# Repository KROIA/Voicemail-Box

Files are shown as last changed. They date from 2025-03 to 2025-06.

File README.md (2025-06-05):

# Voicemail-Box

## About
Modern-day communication is more and more reliant on smartphones. This can cause issues in numerous situations. It can alienate people with writing, seeing, or technological deficiencies. 

Since the development of new electronic systems is often too complicated for non-affine people, the goal is to develop a platform that makes it easier to get started with such a project. The highest priority was given to audio input and output, user differentiation/management, file saving, and transferring those wirelessly.

<tr>
<td>
<div align="center">
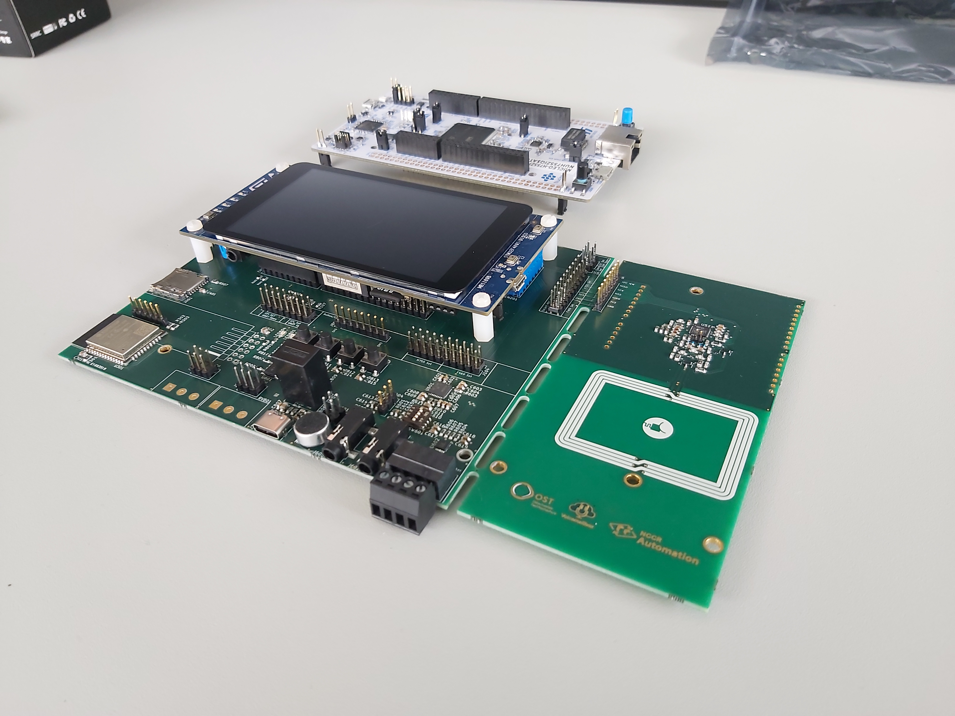
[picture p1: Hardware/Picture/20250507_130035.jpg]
     
</div>
</td>

---
## Repository overview
The repository is structured the following way:
- **Hardware** folder contains the hardware specific project.  
[Go to Hardware Dokumentation](Hardware/README.md)

- **Software** folder contains the main source code and api.  
[Go to Software Dokumentation](Software/BSP_VoiceMailBox/README.md)

---
## Features
The Voicemailbox Development Platform offers the basic hardware and software components to develop specific use cases out of it.
The custom PCB is designed to be flexible for different kind of configurations and the software is built in a modular and structural way, using modern C++ to be able to abstract hardware components better and make it easy to develop custom business logic on to it.

### The current state of development features the following:
- Recording audio from different sources:
  - Audio jack for left and right audio channel.
  - Built-in microphone
- Playback audio to the audio output jack
- Filesystem using a SD-Card and easy to use file class for reading and writing files
- Two different audio encodings for files are supported:
  - **WAV** Which is a lossless easy to write/read file format for audio data with the downside of beeing very large in filesize.
  - **MP3** Which is a more common used audio format, much more compressed and the prefered choice for a application such as this one.
            The only downside is, that it is not fully supported on a **M7** core.
- Testserver implementation that manages file upload/download.
  With the help of the ESP32, files can be uploaded/downloaded from a server using a WIFI connection.
  No user authentication is implemented at the current state of the development.
- Two free programmable LED's.
- Four free programmable buttons.
- Two free programmable analog inputs.
  
### Untested features:
- Playback using the speaker connection (J603) is implemented in hardware but not implemented and tested in the software.
- NFC module

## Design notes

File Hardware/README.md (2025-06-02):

# Hardware
This folder contains all HW-Files and documentation of how to use them

## Info
The name for the Microcontroller/Evaluation Boards will be abreviated in the instructions as the following:
- Voicemail-Box Board: 	VMBB
- STM32F469-Disco:		F469
- Nucleo-H755:			H755
- X-Nucleo NFC8:		NFC8
- P-Mod ESP32:			PMOD
- ...

## Orientation
All jumper/switch settings asume that the board is orientet like this image unless otherwise specified.   
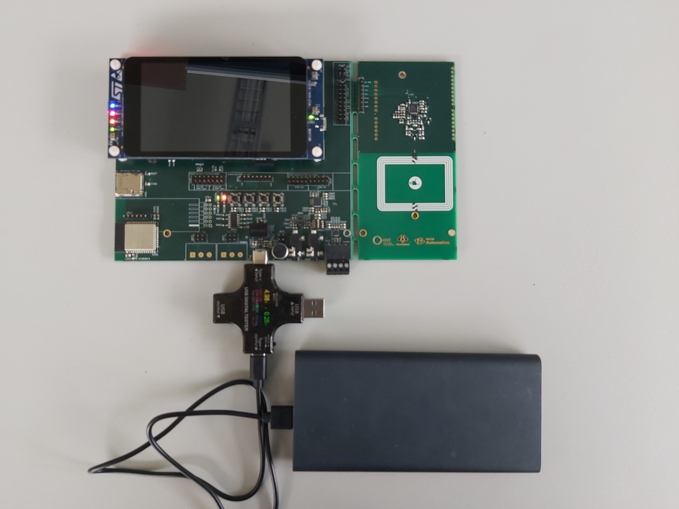
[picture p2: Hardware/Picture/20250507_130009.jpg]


Here is a schematic view where jumpers are also labled:  
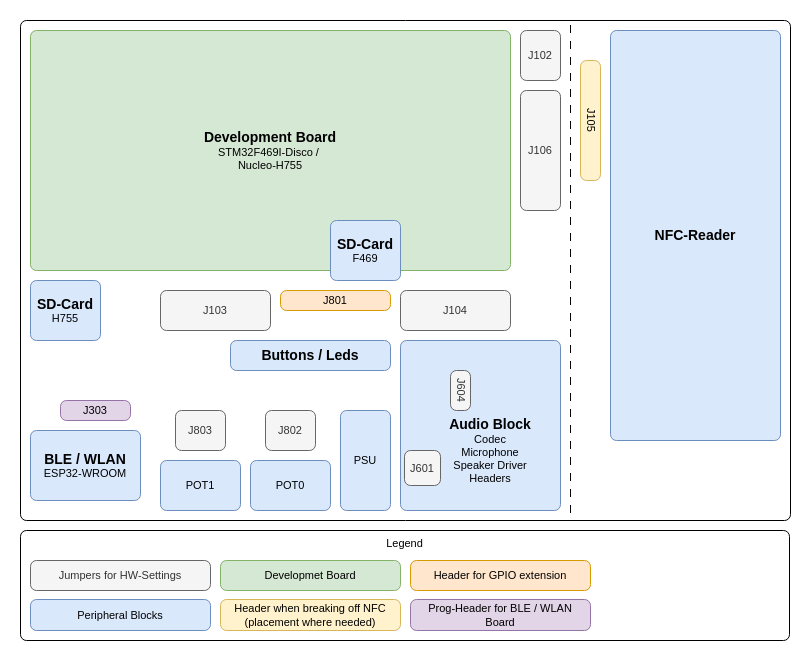
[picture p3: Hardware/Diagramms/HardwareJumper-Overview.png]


## HW Setup
The VMBB is made to be soldered in a full and a partial configuration as well as beeing compatible with
multiple Microcontrollerboards (F469 and H755)

The partial configuration is made for people that are inexperienced with soldering / are lacking equipment.  

The full configuration is made as the de-facto correct way of manufacturing at the cost off beeing way more difficult to produce.

> [!CAUTION]  
> When fully soldering the NFC part will likely require a microscope  
> and the Wifi part will require an aditional USB to UART Converter with 3.3V logic level write the flash memory of ESP32.

to use one or the other, select the correct BOM to solder and only solder the mentioned parts. There are no differences in the use of the finished board.

- tbd: make the BOMs and a assembly plan
- tbd: add pictures

### Soldering
There is no need to solder all possible parts on the pcb. Select the configuration you prefer and only solder the parts in the corresponding BOM.The [Assembly Plan](PCB/Fab/voicemail-box-F_Fab.pdf) shows the position and most of the part Values.
- [Go to partial BOM](PCB/BOM/voicemail-box_partial.csv)
- [Go to full BOM](PCB/BOM/voicemail-box_full.csv)

> [!NOTE]  
> If you want to edit the PCB files I recommend using KICAD with the KiVar Plugin

## Select Microcontroller Board in use (get the correct Jumper settings)
- [Configure Board for H755](Config/H755/H755.md)
- [Configure Board for F469](Config/F469/F469.md)

## Configure periperal Conections (for those which offer this feature)
Some devices can use different Connection Interfaces offereing different benefits.
This is due to the fact, that this is an development board.  
In a specific use, you would select one and ignore the other one.

## WLAN/BLE
Wireless connection can be made either through UART or SPI  
While SPI is way faster, it is more complicated to set up
- [Configure WLAN/BLE using SPI](Config/SPI_WLAN.md)
- [Configure WLAN/BLE using UART](Config/UART_WLAN.md)
## NFC
NFC can be read-out either through I2C or SPI  
While SPI is way faster and is tested.
I2C would help in case that there is a pin-limitation of the final project.
- F469
    - [Configure NFC using SPI](Config/F469/NFC_SPI_F469.md)
    - [Configure NFC using I2C](Config/F469/NFC_I2C_F469.md) 
- H755
    - [Configure NFC using SPI](Config/H755/NFC_SPI_H755.md)
    - [Configure NFC using I2C](Config/H755/NFC_I2C_H755.md) 

## Configure HW Features
- [Configure PSU](Config/PSU.md)
- [Configure Poti](Config/Poti.md)
- [Configure Audio](Config/Audio.md)
- [Configure LEDs](Config/Leds.md)
- [Configure Buttons](Config/Buttons.md)
- [Configure micro SD](Config/uSD.md)

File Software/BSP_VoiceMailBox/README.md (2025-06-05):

# BSP Voice Mail Box

## About
The Voice-Mail-Box Project (VMB in short) provides a Board Support Package (BSP) that abstracts all key peripheral components using c++.

---
## Content
- [Repository overview for the software part](#repository-overview-for-the-software-part)
- [Demos](#demos)
  - [Using STM32F469I-DISCOVERY](#using-stm32f469i-discovery)
  - [Using NUCLEO-H755ZI-Q](#using-nucleo-h755zi-q)
- [Software structure](#software-structure)
  - [Detailed Software structure](#detailed-software-structure)
  - [Peripheral classes](#peripheral-classes)
  - [Data processing classes](#data-processing-classes)
  - [Other utilitiy classes](#other-utilitiy-classes)
  - [HAL abstraction](#hal-abstraction)
  - [Update loop](#-update-loop)
- [Unfinished](#unfinished)
- [Needs to be implemented](#needs-to-be-implemented)

---
## Repository overview for the software part
The software part of this project contains the following folders:
- **BSP_VoiceMailBox** 
  The folder contains the **Board Support Package** for the Voice-Mail-Box and is the hart of the software project.
  It contains all classes which are visualized in the picture in the chapter [Detailed Software structure overview](#detailed-software-structure-overview).  
- **Demos**
  The folder contains some demo projects, using the **BSP** from above.
  In that folder are two sub folders
  - **F469** Containing the example projects for the **STM32F469I-DISCOVERY** board
  - **F755** Containing the example projects for the **NUCLEO-H755ZI-Q** board
- **DevSandbox** 
  The folder contains projects, used to develop the **BSP**. 
  They may be not working since they were created to test stuff or to test downloaded demo projects from ST.

Each project contains only the business logic for the application, the **BSP** is a shared code base over all projects.
The **BSP** gets included in every project. 

---
## Demos
### Using STM32F469I-DISCOVERY
- [HelloAudio](../Demos/F469/F469_HelloAudio/README.md) empty application + setup guide.
- [Record and Playback](../Demos/F469/F469_RecordPlayback/README.md) example that records audio and plays it back.
- [Multi Example](../Demos/F469/F469_MultiExample/README.md) project, containing multiple small examples for different classes of this project.

### Using NUCLEO-H755ZI-Q
- :warning: [HelloAudio](../Demos/H755/H755_HelloAudio/README.md) Currently not working

---
## Software structure
A very brief visualisation about the software hirarchy is displayed below.
<tr>
<td>
<div align="center">
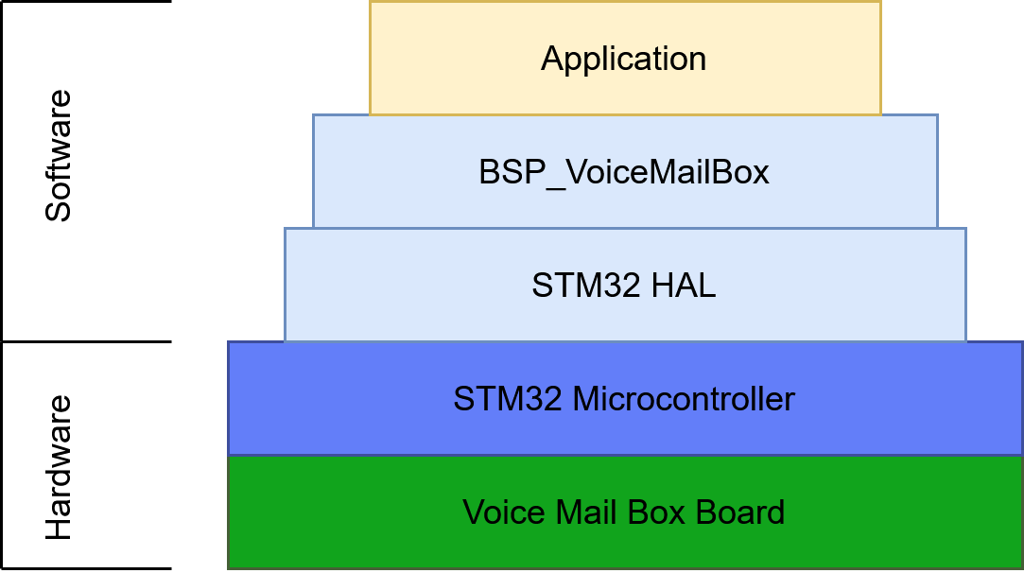
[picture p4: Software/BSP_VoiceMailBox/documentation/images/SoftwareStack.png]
     
</div>
</td>

---
### Detailed Software structure 
This view displays the relation between the key software components delivered by the BSP.
The Application must include only the **BSP_VoiceMailBox.h** header file, it already includes all relevant hardware components and software tools related to the VMB.

<tr>
<td>
<div align="center">
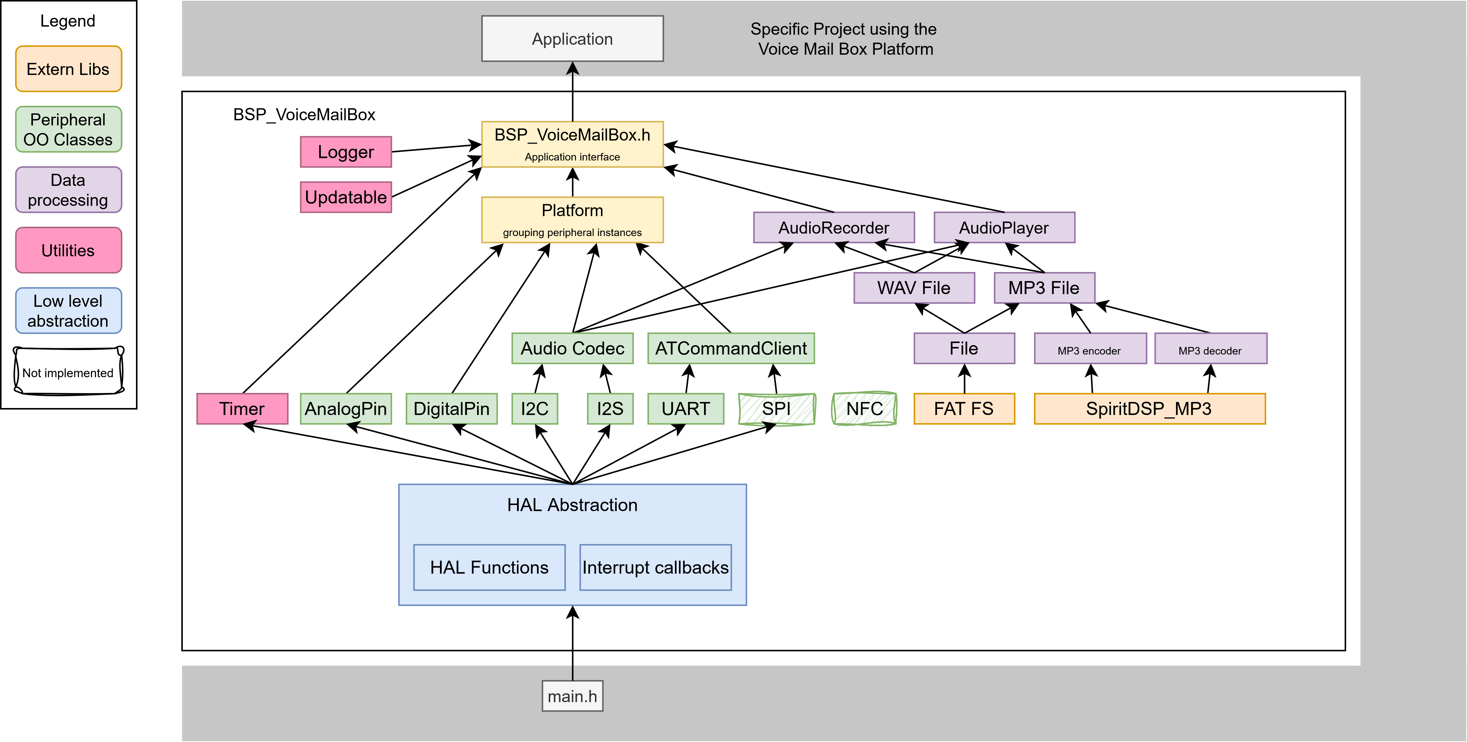
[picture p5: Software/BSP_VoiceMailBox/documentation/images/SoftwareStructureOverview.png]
     
</div>
</td>

### Peripheral classes
- [AnalogPin](documentation/AnalogPin.md)
- [DigitalPin](documentation/DigitalPin.md)
- [I2C](documentation/I2C.md)
- [I2S](documentation/I2S.md)
- [UART](documentation/UART.md)
- [AudioCodec](documentation/AudioCodec.md)
  - [Codec_TLV320AIC3104](documentation/Codec_TLV320AIC3104.md)
- :satellite: [ATCommandClient](documentation/ATCommandClient.md)

### Data processing classes
- [File](documentation/File.md)
  - :musical_note: [WAV File](documentation/WAVFile.md)
  - :musical_note: [MP3 File](documentation/MP3File.md)
- MP3
  - :small_red_triangle_down: [MP3 Encoder](documentation/MP3_encoder.md)
  - :small_red_triangle: [MP3 Decoder](documentation/MP3_decoder.md)
- :microphone: [Audio Recorder](documentation/AudioRecorder.md)
- :speaker: [Audio Player](documentation/AudioPlayer.md)

### Other utilitiy classes
- :pencil: [Logger](documentation/Logger.md)
- :repeat: [Updatable](documentation/Updatable.md)
- :watch: [Timer](documentation/Timer.md)

### HAL abstraction
All HAL related functions are located in two files:
- **HAL_abstraction.hpp**: 
  Contains inline functions, encapsulating all HAL functions used in the BSP.
  Do not use HAL functions inside the BSP directly, that would break the software design of the HAL abstraction. If a new HAL function is needed, create a new inline function with the same name but a **VMB_** in front to signalize its the same function but specific for the BSP
- **interrupts.cpp**: 
  Contains all interrupt callbacks used in the BSP.
  Each class that uses interrupt callbacks, contains a static method that gets called in the interrupt callback to simplify the logic inside the HAL callback.

### :repeat: Update loop
The update loop is programmed in the Platform struct and handles the updating of all **Updatable** objects, clears the I2S flags if configured so and handles the updating of the systick counter for when an overflow occures.
For a smooth operation, this function must be called cyclically without any delays if possible.
You can see the function calls in almost all examples in the loop() function.

---
## Unfinished
- :construction: [TLV320AIC3104 Audio Codec](documentation/Codec_TLV320AIC3104.md) has only the most basic functions implemented and can be expanded to use its full potential.
  
---
## Needs to be implemented
- :construction: SPI class to communicate with the ESP32
- :construction: SPI compatibility with the [ATCommandClient](documentation/ATCommandClient.md) class in order to use SPI for sending and receiving AT-Commands. 
- :construction: NFC class to read NFC tags.

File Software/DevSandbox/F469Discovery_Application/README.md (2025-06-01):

## IOC File Settings

### Middleware and Software Packs:
	- FREERTOS:
		Disable

### Buttons:
	PIN(PA7):	BTN0
		User Label:	BTN0
	PIN(PA2):	BTN1
		User Label:	BTN1
	PIN(PG12):	BTN2
		User Label:	BTN2
	PIN(PA1):	BTN3
		User Label:	BTN3

### LEDS:
	PIN(PA6): 	LED0
		User Label: LED0
	PIN(PG12): 	LED1
		User Label: LED1
		
### Potis:
	PIN(PC4):	ADC1_IN14
		User Label:	POT0
	PIN(PC3):	ADC2_IN13
		User Label:	POT1
		
### WiFi:
	USART6:
		Baud Rate: 115200
		Word Length: 8 Bits (including parity)
		Parity: None
		Stop Bits: 1
		PIN(PG14): 	TX 
		PIN(PG9): 	RX
		// DMA Settings:
		// 	DMA für RX & TX
		// 	Mode: Normal
		NVIC Settings:
			[x] USART6 global interrupt
	PIN(PC5): INT GPIO_ExtI5 with name: "ESP_INT"
	
### Debug Console:
	USART3:
		Baud Rate: 115200
		Word Length: 8 Bits (including parity)
		Parity: None
		Stop Bits: 1
		// DMA Settings: 
		// 	DMA für RX & TX
		// 	Mode: Normal
		NVIC Settings:
			[x] USART3 global interrupt
			
### Audio Codec
	I2S2:
		Mode: Full-Duplex Master
		[x] Master Clock Output
		GPIO Settings:
			PIN(PB12): I2S2_WS (I2S2_SCLK)
			PIN(PB13): I2S2_CK (I2S2_BCLK)
			PIN(PC1):  I2S2_SD (I2S2_SDA)
			PIN(PC2):  I2S2_ext_SD 	(I2S2_SDA_ext)
			PIN(PC6):  I2S2_MCK (I2S2_MCLK)
			
		Parameter Settings:
			Transmission Mode: Mode Master Transmit
			Communication Standard: I2S Philips
			Data and Frame Format: 16Bit Data on 16 Bits Frame
			Selected Audio Frequency: 48KHz
			
		DMA Settings:
			SPI2_TX:
				Mode: Circular
				Data Width: Half Word
	GPIO:
		PIN(PG13): CODEC_NRESET Digital Output
	
### SD-Card
	System Core:
		NVIC:
			SDIO global interrupt: ON
	Connectivity:
		SDIO:
			Mode = "SD 1 bit"
			DMA Setting:
				SDIO_RX, DMA2 Stream 3, Peripheral To Memory, Low
				SDIO_TX, DMA2 Stream 6, Memory To Peripheral, Low
	Middleware and Software Packs:
		FATFS:
		    SD Card: ON
		    Advanced Settings->SDIO:
		    Use dma template: Enabled
		
## Project Properties
		C/C++ General->Paths and Symbols:
			Includes:
				Add:
					Directory: "${ProjDirPath}/../../BSP_VoiceMailBox/inc"
					[x] Add to all configurations
					[x] Add to all languages
			Source Location:
				Link Folder:
					[x] Link to folder in file system
					Variables...
						New...
							Name: BSP_VoiceMailBox
							Location: "${PROJECT_LOC}/../../BSP_VoiceMailBox/src"
							OK
						Select the new created variable: BSP_VoiceMailBox
						OK
				OK
		
		Library Includes
		FPU setting

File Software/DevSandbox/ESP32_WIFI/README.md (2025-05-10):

# PmodESP32

## Setup
### Communication via UART
Board STM32F469
UART6 auf Stiftleiste CN12
ESP32:2 -- RX -- DiscoveryBoard(CN12:6 -- TX -- STM32:PC6)
ESP32:3 -- TX -- DiscoveryBoard(CN12:8 -- RX -- STM32:PC7)

Software:
UART6
Baud: 115200
DMA für UART6_RX & UART6_TX
NVIC->UART6 global interrupt ENABLED

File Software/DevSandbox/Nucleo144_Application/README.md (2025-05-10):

- Connectivity->ETH:
	Disable on both M7 & M4

- Connectivity->SDMMC1:
  Mode = "SD 1 bit"
  NVIC:
	SDMMC1 global interrupt: Enabled
  DMA Setting:
	? Nicht gefunden?: SDIO_RX, DMA2 Stream 3, Peripheral To Memory, Low
	? Nicht gefunden?: SDIO_TX, DMA2 Stream 6, Memory To Peripheral, Low

- WiFi-Modul:
	USART1:
		Enabled on M4
		DMA für RX and TX
		PIN(PB6): 	USART1_TX 
		PIN(PB7): 	USART1_RX
	? PIN(PC2):			INT

- I2S2 (I2S_A, Dataflow(STM32->Codec)):
	Enabled on M4
	? HalfDuplexMasterTransmit
	[x] Master Clock Output
	Parameter Settings:
		Selected Audio Frequency: 44KHz
	GPIO Settings:
		PIN(PB12): I2S2_WS
		PIN(PB13): I2S2_CK
		PIN(PB15): I2S2_SDO
		PIN(PC6): I2S_MCK
	NVIC Settings:
		SPI2 global interrupt: Enabled 
	DMA Settings:
		SPI2_TX:
			Mode: Circular
			Data Width: Half Word
	
- I2S3 (I2S_B, Dataflow(Codec->STM32)):
	Enabled on M4
	? HalfDuplexMasterReceive
	? [x] Master Clock Output
	Parameter Settings:
		Selected Audio Frequency: 44KHz
	GPIO Settings:
		PIN(PA15): I2S3_WS
		PIN(PB3): I2S3_CK
		PIN(PC7): I2S3_MCK
		PIN(PC11): I2S3_SDI
		? PIN(PB4):              I2S_SDA_ext
		? PIN(PG14): 		    CODEC_nReset  
	NVIC Settings:
		SPI3 global interrupt: Enabled
	DMA Settings:
		SPI3_RX:
			Mode: Circular
			Data Width: Half Word
		
- I2C1 (Codec config):
	Enabled on M4
	GPIO Settings:
		PIN(PB8):	I2C1_SCL
		PIN(PB9): 	I2C1_SDA
	DMA Settings:
		I2C1_TX:
			Mode: Normal
			Data Width: Byte
		I2S1_RX:
			Mode: Normal
			Data Width: Byte
			
- SPI1 (SPI2 auf dem Schema, NFC-Reader):
	Enabled on M4
	Full-Duplex Master
	Hardware NSS Output Signal
	GPIO Settings:
		PIN(PA4): 	SPI1_NSS
		PIN(PB3):	SPI1_SCK
		PIN(PB5):	SPI1_MOSI
		PIN(PG9):	SPI1_MISO
		? PIN(PA3): NFC_INT 
	DMA Settings:
		SPI1_RX:
			Mode: Circular
			Data Width: Byte
		SPI1_TX:
			Mode: Circular
			Data Width: Byte
	NVIC Settings:
		DMA1 stream2 global interrupt: Enabled
		DMA1 stream6 global interrupt: Enabled
		SPI1 global interrupt: Enabled

- LEDS:
	PIN(PA8): 	LED0
		User Label: LED0
		Pin Context Assignment: ARM Cortex-M4
	PIN(PG12): 	LED1
		User Label: LED1
		Pin Context Assignment: ARM Cortex-M4

- Buttons:
	PIN(PD15):	BTN0
		User Label:	BTN0
		Pin Context Assignment: ARM Cortex-M4
	PIN(PE11):	BTN1
		User Label:	BTN1
		Pin Context Assignment: ARM Cortex-M4
	PIN(PE14):	BTN2
		User Label:	BTN2
		Pin Context Assignment: ARM Cortex-M4
	PIN(PE13):	BTN3
		User Label:	BTN3
		Pin Context Assignment: ARM Cortex-M4
		
- Potis:
	PIN(PB1):	ADC1_INP5
		User Label:	POT0
		Pin Context Assignment: ARM Cortex-M4
	PIN(PC1):	ADC1_INP11
		User Label:	POT1
		Pin Context Assignment: ARM Cortex-M4

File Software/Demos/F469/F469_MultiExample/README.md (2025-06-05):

# Multi Example

## How to select a example
One example can be selected in the `Application.cpp`.
Set the variable `selectedExample` to a desired enum value.
The rest is handled automatically. You can now navigate to the examples specific code.
Lets take the AnalogPin example. Its code is programmed in the `Example_AnalogPin.cpp`.
In that file there may be multiple usecases programmed.
Each usecase can be enabled individually.
Each such `Example_XX.cpp` is structured the same way.
Here a quick file overview:
- On the top are function declarations for setup and loop for that specific usecase example. Additionally a quick description about that usecase is given.
- The `setup()` and `loop()` functions are called from the main `Application.cpp`.
  In that functions you have to uncomment that specific usecase you want to run.
  Do that for both functions and do not mix examples.
- On the bottom of the file are the different use case implementations.
  You can treat them as if they were in the main `Application.cpp` `setup()` and `loop()` functions. This makes it easy to copy code in your own project. 

---
## Examples
- [AnalogPin](#analogpin-example)
- [DigitalPin](#digitalpin-example)
- [AudioPlayer](#audioplayer-example)
- [AudioRecorder](#audiorecorder-example)
- [File](#file-example)
  - [WAV File](#wav-file-example)
  - [MP3 File](#mp3-file-example)
- [I2C](#i2c-example)
- [I2S](#i2s-example)
- [MP3 Encoder](#mp3-encoder-example)
- [MP3 Decoder](#mp3-decoder-example)
- [UART](#uart-example)
- [DC Offset correction example](#dc-offset-correction-example)
- [ATCommandClient example](#atcommandclient-example)
- [Codec TLV320AIC3104 example](#codec-tlv320aic3104-example)
- [Logger example](#logger-example)
- [Updatable example](#updatable-example)
- [Timer example](#timer-example)

---
### AnalogPin example
1) Usage of the built-in potentiometer. It prints the analog value to the console.
2) Instantiating a custom potentiometer. Also prints the analog value to the console.

### DigitalPin example
1) Usage of the built-in button and led. It takes the button value and switches the led on when the button is pressed.
2) Instantiating a custom button and led. It does the same as the first use case.
3) Usage of the callback functions of a button. 
  It turns the LED0 on when BTN0 gets pressed and turns the LED0 off when the BTN0 gets released.
  When the BTN0 is pressed down, the LED1 gets toggled, therefore blinks as long as the BTN0 is held down.

### AudioPlayer example
1) Plays a mp3 file called `record.mp3` from the SD-Card on startup once.
2) Plays a mp3 file called `record.mp3` from the SD-Card when the BTN0 gets pressed.
  By clicking the same button again, the playback will be stopped.
  When playing, the BTN1 can be used to pause/resume the playback.

### AudioRecorder example
1) Records a mp3 file called `record.mp3` to the SD-Card when the BTN0 gets pressed.
  By clicking the same button again, the recording will be stopped.
  When playing, the BTN1 can be used to pause/resume the recording.

### File example
1) Example on how to write to a file.
2) Example on how to append to a file.
3) Example on how to read from a file.

#### WAV File example
1) Example on how to write to a .wav file using live audio data from the codec.
2) Example on how to read from a .wav file and outputting it to the codec.

#### MP3 File example
1) Example on how to write to a .mp3 file using live audio data from the codec.
2) Example on how to read from a .mp3 file and outputting it to the codec.

#### I2C example
The example writes to the first register on the audio codec and reads the value back.

#### I2S example
The example uses a i2s object to read and write the audio data from the audio codec.
The codec sends microphone data and the application copies that microphone data to the
speaker output buffer. 
Since the audio codec needs to be configured before data arrives on the i2s, the following code is called first to ensure setup and then stop the DMA in order to start it manually afterwards again. Just for you to know that the DMA needs to be started on a i2s object.
Using the platforms audio codec object directly will take that step from you.
``` C++
VoiceMailBox::setup();
i2s.stopDMA();
```

#### MP3 Encoder example
This example reads audio samples from a .wav file and encodes them to .mp3 format using the `MP3_encoder` class. The encoded data is then written to a new .mp3 file.

#### MP3 Decoder example
This example uses the MP3_decoder class to decode an MP3 file and write the decoded audio data to a WAV file.
The MP3_decoder class is used to read compressed MP3 data and decode it into PCM audio samples.
The WAVFile class is used to write the decoded audio samples to a WAV file.

#### UART example
This example sends some simple text or byte arrays over the UART interface
The UART can also wait for a specific string to be received or read until a target string is found.

#### DC Offset correction example
This example shows how to remove the DC offset from the left and right audio channels.

#### ATCommandClient example
This example shows hot to use the ESP32 using the ATCommandClient abstraction to communicate with the server for uploading and downloading files.
To run this example, follow the [instructions](../../../BSP_VoiceMailBox/documentation/TestServer.md) to setup the testserver.

#### Codec TLV320AIC3104 example
1) This example shows a basic usage of the TLV320AIC3104 codec.
   The example captures audio data from the codec and plays it back directly.
2) This example shows a basic usage of the TLV320AIC3104 codec with volume control.
   The POT1 potentiometer is used to control the volume of the audio data captured from the codec.

#### Logger example
Shows some simple console output methodes that can be used.

#### Updatable example
Shows how to use the Updatable class to automatically call a update function in a derived class object.

#### Timer example
All examples in the timer example do the same thing but are implemented in different ways, to show the different ways the Timer can be used.

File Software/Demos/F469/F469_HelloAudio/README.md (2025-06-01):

# HelloAudio for the F469
The HelloAudio example is just a empty application ready to expand on.
Copy the project in case you want to develop a custom application.

Below is a setup guide that describes step by step how to configure a completly new project for the Voice Mail Box platform. It uses the **STM32F469I-DISCOVERY** board.
> [!WARNING]  
> Read each instruction carfully since there are many pitfalls. 

## Content
- [Project creation](#project-creation)
- [IOC File Setup](#ioc-file-setup)
  - [Disable unused parts](#disable-unused-parts)
  - [Buttons](#buttons)
  - [Leds](#leds)
  - [Debug Pins](#debug-pins)
  - [Potentiometer](#potentiometer)
  - [WIFI ESP32](#wifi-esp32)
  - [Debug Console](#debug-console)
  - [I2C](#i2c)
  - [SD-Card](#sd-card)
  - [Audio Codec](#audio-codec)
- [Create Application body](#create-application-body)
- [Setup de BSP_VoiceMailBox](#setup-de-bsp_voicemailbox)
  - [Microcontroller board selection](#microcontroller-board-selection)
  - [Peripheral handle getter functions](#peripheral-handle-getter-functions)
  - [Peripheral GPIOs](#peripheral-gpios)
  - [Basic Application using the BSP_VoiceMailBox](#basic-application-using-the-bsp_voicemailbox)
- [Project Properties](#project-properties)
  - [Includes](#includes)
  - [Source Locations](#source-locations)
  - [Libraries](#libraries)
    - [SpiritDSP MP3](#spiritdsp-mp3)
- [How to copy this project as tamplate](#how-to-copy-this-project)
- [Compiler errors](#compiler-errors)

---
## Project creation
Create a new STM32 Project and select the Board: **STM32F469I-DISCO** in the **Board Selector** window.
Select Target Language **C++**
Initialize all peripherals in default mode. 

## IOC File Setup
### Disable unused parts
#### Connectivity
- Disable I2C2
- QUADSPI

#### Multimedia
- SAI1

#### Middleware and Software Packages
- FREERTOS, we don't use a OS.
---
### Buttons
Select the Pins and assign them the given function and user label.

| Pin | Function | User Label |
| --- | --- | --- |
| PA7 | GPIO_Input  | BTN0 |
| PA2 | GPIO_Input  | BTN1 |
| PG12 | GPIO_Input  | BTN2 |
| PA1 | GPIO_Input  | BTN3 |

---
### Leds
Select the Pins and assign them the given function and user label.

| Pin | Function | User Label |
| --- | --- | --- |
| PA6 | GPIO_Output | LED0 |
| PG11 | GPIO_Output | LED1 |

---
### Debug Pins
The debug pins are optional and only used when the macro **VMB_DEVELOPMENT_CONFIGURATION** is defined in the `settings.h`.
Select the Pins and assign them the given function and user label.

| Pin | Function | User Label |
| --- | --- | --- |
| PC7 | GPIO_Output | DBG0 |
| PC13 | GPIO_Output | DBG1 |
| PA4 | GPIO_Output | DBG2 |

---
### Potentiometer
Select the Pins and assign them the given function and user label.

| Pin | Function | User Label |
| --- | --- | --- |
| PC4 | ADC1_IN14 | POT0 |
| PC3 | ADC2_IN13 | POT1 |

---
### WIFI ESP32
#### UART
Enable **USART6** in the **Connectivity** section.
- **Mode**: Asynchronous
- **Hardware Flow Control**: Disable

##### Parameter Settings
Let the settings to be default but check for the following:
- **Baud Rate**: 115200
- **Word Length**: 8 Bits
- **Parity**: None
- **Stop Bits**: 1

##### NVIC Settings
- **USART6 global interrupt**: Enabled

Select the Pins and assign them the given function.

| Pin | Function |
| --- | --- |
| PG14 | USART1_TX | 
| PG9 | USART1_RX |

---
### Debug Console
Enable **USART3** in the **Connectivity** section.
- **Mode**: Asynchronous
- **Hardware Flow Control**: Disable

##### Parameter Settings
Let the settings to be default but check for the following:
- **Baud Rate**: 115200
- **Word Length**: 8 Bits
- **Parity**: None
- **Stop Bits**: 1

##### NVIC Settings
- **USART3 global interrupt**: Enabled

Select the Pins and assign them the given function.

| Pin | Function |
| --- | --- |
| PB10 | USART3_TX | 
| PB11 | USART3_RX |

---
### I2C
Enable **I2C1** in the **Connectivity** section.
- **Runtime contexts**: Cortex-M7
- **I2C**: I2C

Select the Pins and assign them the given function.

| Pin | Function |
| --- | --- |
| PB8 | I2C1_SCL | 
| PB9 | I2C1_SDA |
  
--- 
### SD Card
#### System Core
##### NVIC
- **SDIO global interrupt**: ON
#### Connectivity
##### SDIO
- **Mode**: SD 1 bit
###### DMA Setting
- SDIO_RX, DMA2 Stream 3, Peripheral To Memory, Low
- SDIO_TX, DMA2 Stream 6, Memory To Peripheral, Low
#### Middleware and Software Packs
##### FATFS
- **SD Card**: ON
###### Advanced Settings->SDIO:
- **Use dma template**: Enabled
  
---
### Audio Codec
Enable **I2S2** in the **Multimedia** section.
- **Mode**: Full-Duplex Master
- **Master Clock Output**: Enabled

Select the Pins and assign them the given function.

| Pin | Function |
| --- | --- |
| PB12 | I2S2_WS | 
| PB13 | I2S2_CK |
| PC1 | I2S2_SD |
| PC2 | I2S2_ext_SD |
| PC6 | I2S2_MCK |

##### Parameter Settings
- **Communication Standard**: I2S Philips
- **Data and Frame Format**: 16 Bits Data on 16 Bits Frame
- **Selected Audio Frequency**: 48KHz

#### Reset pin
Select the Pin and assign them the given function.

| Pin | Function | User Label |
| --- | --- | --- |
| PG13 | GPIO_Output | CODEC_NRESET |

---
## Create Application body
Follow the instructions on [How to call C++ code from C](../../../BSP_VoiceMailBox/documentation/CppFromC.md) to setup the Application body.

---
## Setup de BSP_VoiceMailBox
### Microcontroller board selection
In the `main.h` add the following define.
It defines which board is selected to switch between the different HAL implementations in the BSP.
``` C
/* USER CODE BEGIN Private defines */
#define VMB_MICROCONTROLLER_BOARD__STM32F469I_DISCOVERY
/* USER CODE END Private defines */
``` 
---
### Peripheral handle getter functions
To get access to the peripheral handles, the following code must be inserted in the `main.h`:

``` C
/* USER CODE BEGIN EFP */

/**
 * @brief The BSP of the Voice Mail Box needs to access the different peripheral handles generated by the CubeMX.
 * @details
 * When porting the project to a different microcontroller, these getters have to be manually declared here,
 * implemented in the main.cpp and used in the Platform.cpp.
 */
ADC_HandleTypeDef* getADC_POT0();
ADC_HandleTypeDef* getADC_POT1();

UART_HandleTypeDef* getUART_DEBUG();
UART_HandleTypeDef* getUART_WIFI();

I2C_HandleTypeDef* getI2C_Handle();
I2S_HandleTypeDef* getI2S_CODEC();

/* USER CODE END EFP */
```

Implement the functions in the `main.c`.
The instance name may be different. You can find the correct name in the `main.c` on the top where CUBE MX has generated the structs instances.
``` C
/* USER CODE BEGIN PV */
ADC_HandleTypeDef* getADC_POT0()
{
    return &hadc1;
}
ADC_HandleTypeDef* getADC_POT1()
{
    return &hadc2;
}
UART_HandleTypeDef* getUART_DEBUG()
{
    return &huart3;
}
UART_HandleTypeDef* getUART_WIFI()
{
    return &huart6;
}
I2C_HandleTypeDef* getI2C_Handle()
{
    return &hi2c1;
}
I2S_HandleTypeDef* getI2S_CODEC()
{
    return &hi2s2;
}
/* USER CODE END PV */
```
---
### Peripheral GPIOs
CUBE MX sometimes generates macros using the user labels from the IOC file. But for the H755 for example, that process is not made during code generation.
In that case these definitions must been made manually and look like this:
``` C
#define BTN0_Pin GPIO_PIN_7
#define BTN0_GPIO_Port GPIOA
// ... Other pins
```
That macros will be used in the `Platform.cpp` for creating the `DigitalPin` instances.

``` C++
// Inside the Platform.cpp
// Fill in the GPIO_TypeDef* and pin values, generated from the CUBEMX for the buttons
DigitalPin& Platform::getButton(Button index)
{
    // Creating static instances of the DigitalPin class for each button
    // The constructor of the DigitalPin class takes the <GPIO_TypeDef*>, <pin number> and <isInverted> as parameters
    // On this board the buttons are active high, so the isInverted parameter is set to false or can be omitted
    static DigitalPin button[] = 
    {
        { BTN0_GPIO_Port, BTN0_Pin },  // <---
        { BTN1_GPIO_Port, BTN1_Pin },
        { BTN2_GPIO_Port, BTN2_Pin },
        { BTN3_GPIO_Port, BTN3_Pin }
    };
    return button[index];
}
```
Make sure you use the same macro names as they already are used in the `Platform.cpp`, so that the `Platform.cpp` can be let unchanged. Otherwise the `Platform.cpp` must be edited to fit your custom peripheral GOPIO macro names.

---
### Basic Application using the BSP_VoiceMailBox
Replace the empty Application by the following code

``` C++
// Application.cpp
#include "Application.h"
#include "BSP_VoiceMailBox.hpp"

void setup()
{
    VoiceMailBox::setup();
}

void loop()
{
    VoiceMailBox::update();
}

```
---
## Project Properties
Open the **Properties** window for the project.
Navigate to C/C++ General->Paths and Symbols.

### Includes
Click **Add** and paste the following path: `${ProjDirPath}/../../../BSP_VoiceMailBox/inc`.
The path may be different, depending on where the project got created, but in this case the include path is specified relative to the current projects path.
In the case, you create a project on a different location, you have to change the path accordingly.
Set the checkmarks: **Add to all configurations** and **Add to all languages**.
Confirm it by pressing the **OK** button.

For some reason, FATFS may not added to both C and C++, check that by clicking on the languages **GNU C** and **GNU C++**. If the includes for FATFS are only on C, then add them to the C++ language too.

### Source Locations
Click **Link Folder** and check the checkmark **Link to folder in the file system**.
Click on **Variables...**, add a **New** variable and name it: `BSP_VoiceMailBox` and the location: `${PROJECT_LOC}\..\..\..\BSP_VoiceMailBox\src`.
Click **OK**, select the newly created variable and click **OK** again, and then again **OK**.
Now switch the **Configuration** to the other one (Debug -> Release or Release -> Debug).
Now click **Add Folder**, select **BSP_VoiceMailBox** from the list and click **OK**.

### Libraries
#### SpiritDSP MP3 
The spiritDSP MP3 library was used in the [X-CUBE-AUDIO](https://www.st.com/en/embedded-software/x-cube-audio.html) example and therefore also used in this Project.
- In the `Libraries` section click on `Add...` and fill the following in the dialog:
  - **File**: `_mp3decoder_cortex_m4_v2.2.0`
  - **Add to all configurations**: `checked`
  - **Add to all languages**: `checked`
   `OK`
<br>

- In the `Libraries` section click on `Add...` and fill the following in the dialog:
  - **File**: `_mp3encoder_cortex_m4_v2.2.0`
  - **Add to all configurations**: `checked`
  - **Add to all languages**: `checked`
   `OK`
<br>
<br>

- In the `Library Paths` section click on `Add...` and fill the following in the dialog:
  - **Directory**: `${ProjDirPath}/../../../BSP_VoiceMailBox/Middlewares/ST/STM32_Audio/Codecs/SpiritDSP_MP3_Dec/lib`
  - **Add to all configurations**: `checked`
  - **Add to all languages**: `checked`
   `OK`
<br>

- In the `Library Paths` section click on `Add...` and fill the following in the dialog:
  - **Directory**: `${ProjDirPath}/../../../BSP_VoiceMailBox/Middlewares/ST/STM32_Audio/Codecs/SpiritDSP_MP3_Enc/lib`
  - **Add to all configurations**: `checked`
  - **Add to all languages**: `checked`
   `OK`
<br>
<br>

###### Floating point unit settings
Navigate to `C/C++ Build->Settings` and in the `MCU/MPU Settings` set the **floating point ABI** to `Mix HW/SW implementation`, otherwise the project will not compile.
Optional you can enable the `Use float with printf from newlib-nano` and the same for `... scanf ...`.
Do that for both configurations: **Debug** and **Release**

---
## How to copy this project
When you want to use this project as template to create your custom application, you have to repair some ST related copy proplems...
1) If you opened this project in the CubeIDE, close it and delete it from the worspace. **(not from the disc!)**
2) Navigate to the folder of this project and copy it to your desired project directory.
3) Change the name of the copied folder to your new projects name.
4) In the Cube IDE: `File->import->Existing Project into Workspace` and hit **Next >**.
5) Browse to your new project location and use that folder. In the Projects list, the HelloAudio project should be visible.
6) Click on **Finish**
7) Now right click on to the project to rename it using the new project name.
8) In the `Project Explorer` delete the folder called `BSP_VoiceMailBox`. (It is only a link) 
9) Open the `Project Properties`.
10) Navigate to `Resource->Linked Resources`.
11) In the list you may find `BSP_VoiceMailBox_1` with a long path, delete that. Only the `BSP_VoiceMailBox` is needed.
12) Navigate to `C/C++ General->Paths and Symbols`.
13) Now link the `BSP_VoiceMailBox` again using the variable. You find the instructions for that in the [Source Locations](#source-locations) chapter of this document. But you don't have to create a new variable since the variable aready exists.

Thats it, the copied project should now compile and is ready to be filled with some nice C++ code. :sunglasses:
Navigate to the folder `Application/src`, here you find the `Application.cpp` which is your main application file.

---
## Compiler errors
#### False floating point setting
Error: `F469_HelloAudio.elf uses VFP register arguments`
Means the [FPU setting](#floating-point-unit-settings) is not correct. 

#### No peripheral handle getter functions
Error: `'getADC_POT0' was not declared in this scope`
Or similar errors related to the `Platform.cpp` mean that there is no get function for the needed peripheral handle structs. [See here](#peripheral-handle-getter-functions) how to resolve the issue.

#### No peripheral GPIO macros defined
Error: `'BTN0_Pin' undeclared`
Or similar errors related to the `Platform.cpp` mean that there are undefined macros which must be defined in the `main.h`. [See here](#peripheral-gpios) how to resolve the issue.

#### No settings header
Error: `No settings header included, make sure to provide a custom settings header in the main.h file when VMB_CUSTOM_SETTINGS_HEADER is defined!`
If you use custom settings, make sure to not only define the macro `VMB_CUSTOM_SETTINGS_HEADER` but also include a custom settings header in the `main.h` that provides all settings needed for the BSP.

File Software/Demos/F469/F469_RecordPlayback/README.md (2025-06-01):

# RecordPlayback example
This example uses two buttons on the PCB to start/stop recording a mp3 file and to play/stop the recorded mp3 file.
The application code can be found in `Application/src/Application.cpp`

The whole applications business logic is implemented in the `setup()` function and consists of instantiating:
- The `recorder`, providing the audio codec and a led to work on.
- The `player`, providing the audio codec and a different led to work on.
- Registering the `setOnFallingEdgeCallback` for the buttons, providing the logic for both on what to do when a button gets pressed.

## How to use
Make sure a SD-Card is inserted in to the F469-Discovery board.
Either use the microphone or the audio input jack and also connect the output jack to a speaker box.

### Recording audio
By pressing the Button 0 (SW801) once, the recording starts. that is visualized by the green flashing LED.
To stop the recording, just press the same button again.
The recording will be saved to the SD-Card.

### Playback audio
Make sure that you recorded a audio before or manually placed a mp3 file in to the SD-Card with the correct name.
By pressing the Button 1 (SW802) once, the playback starts. that is visualized by the red flashing LED.
To stop the playback, just press the same button again.

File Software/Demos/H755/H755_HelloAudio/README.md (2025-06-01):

# Hello Audio Example
This Setup uses the NUCLEO-H755ZI-Q microcontroller board using the M7 core.

> [!CAUTION]  
> This board is not tested using this configuration
> Some steps may be faulty

> [!CAUTION]  
> MP3 encoding is not supported on the M7 
> In case MP3 needs to be used, use the M4 core.

## IOC File Setup
---
### Buttons
Select the Pins and assign them the given function and user label.

| Pin | Function | User Label |
| --- | --- | --- |
| PD15 | GPIO_Input  | BTN0 |
| PE11 | GPIO_Input  | BTN1 |
| PE14 | GPIO_Input  | BTN2 |
| PE13 | GPIO_Input  | BTN3 |

---
### Leds
Select the Pins and assign them the given function and user label.

| Pin | Function | User Label |
| --- | --- | --- |
| PA8 | GPIO_Output | LED0 |
| PG12 | GPIO_Output | LED1 |

---
### Debug Pins
The debug pins are optional and only used when the macro **VMB_DEVELOPMENT_CONFIGURATION** is defined in the `settings.h`.
Select the Pins and assign them the given function and user label.

| Pin | Function | User Label |
| --- | --- | --- |
| PD3 | GPIO_Output | DBG0 |
| PD4 | GPIO_Output | DBG1 |
| PD5 | GPIO_Output | DBG2 |

---
### Potentiometer
Enable the ADC's used in the **Analog** section
#### ADC1
- **Runtime contexts**: Enabled on Cortex-M7.
- **IN5**: IN5 Single-ended
  
#### ADC3
- **Runtime contexts**: Enabled on Cortex-M7.
- **IN1**: IN1 Single-ended

Select the Pins and assign them the given function and user label.

| Pin | Function | User Label |
| --- | --- | --- |
| PB1 | ADC1_INP5 | POT0 |
| PC3 | ADC3_INP1 | POT1 |

---

### WIFI ESP32
#### UART
Enable **USART1** in the **Connectivity** section.
- **Runtime contexts**: Cortex-M7
- **Mode**: Asynchronous
- **Hardware Flow Control**: Disable

##### Parameter Settings
Let the settings to be default but check for the following:
- **Baud Rate**: 115200
- **Word Length**: 8 Bits
- **Parity**: None
- **Stop Bits**: 1

##### NVIC Settings
- **USART1 global interrupt**: Enabled

Select the Pins and assign them the given function.

| Pin | Function |
| --- | --- |
| PB6 | USART1_TX | 
| PB7 | USART1_RX |

---
### Debug Console
In order to enable the UART for the debug console as we need, 
the **Virtual Com Port** in the **BSP** section must be disabled.
After that, USART3 can be enabled. 

Enable **USART3** in the **Connectivity** section.
- **Runtime contexts**: Cortex-M7
- **Mode**: Asynchronous
- **Hardware Flow Control**: Disable

##### Parameter Settings
Let the settings to be default but check for the following:
- **Baud Rate**: 115200
- **Word Length**: 8 Bits
- **Parity**: None
- **Stop Bits**: 1

##### NVIC Settings
- **USART3 global interrupt**: Enabled

Select the Pins and assign them the given function.

| Pin | Function |
| --- | --- |
| PD8 | USART3_TX | 
| PD9 | USART3_RX |

---
### I2C
Enable **I2C1** in the **Connectivity** section.
- **Runtime contexts**: Cortex-M7
- **I2C**: I2C

Select the Pins and assign them the given function.

| Pin | Function |
| --- | --- |
| PB8 | I2C1_SCL | 
| PB9 | I2C1_SDA |
  
--- 
### SD Card
Since The SD-Card slot is on our custom board, we need to setup it manually.
Enable **SDMMC1** in the **Connectivity** section.
- **Runtime contexts**: Cortex-M7
- **Mode**: SD 1 bit

Select the Pin and assign them the given function.

| Pin | Function | User Label |
| --- | --- | --- |
| PG10 | GPIO_Input  | SD_DETECT |
  
---
### Audio Codec
Enable **I2S2** in the **Multimedia** section.
- **Runtime contexts**: Cortex-M7
- **Mode**: Full-Duplex Master
- **Master Clock Output**: Enabled

Select the Pins and assign them the given function.

| Pin | Function |
| --- | --- |
| PB12 | I2S2_WS | 
| PB13 | I2S2_CK |
| PB14 | I2S2_SDI |
| PB15 | I2S2_SDO |
| PC6 | I2S2_MCK |

##### Parameter Settings
- **Communication Standard**: I2S Philips
- **Data and Frame Format**: 16 Bits Data on 16 Bits Frame
- **Selected Audio Frequency**: 48KHz

##### NVIC Settings
- **SPI2 global interrupt**: Enabled

##### DMA Settings
- **I2S2_EXT_RX** using DMA1 Stream 3 Peripheral To Memory
  **Mode**: Circular
  **Data Width**: Half Word
<br>
- **SPI2_TX** using DMA1 Stream 4 Memory To Peripheral
  **Mode**: Circular
  **Data Width**: Half Word

#### Reset pin
Select the Pin and assign them the given function.

| Pin | Function | User Label |
| --- | --- | --- |
| PG14 | GPIO_Output | CODEC_NRESET |

---
## Create Application body
Follow the instructions on [How to call C++ code from C](../../../BSP_VoiceMailBox/documentation/CppFromC.md) to setup the Application body.

### Setup de BSP_VoiceMailBox
#### Microcontroller board selection
In the `main.h` add the following define.
It defines which board is selected to switch between the different HAL implementations in the BSP.
``` C
/* USER CODE BEGIN Private defines */
#define VMB_MICROCONTROLLER_BOARD__STM32F469I_DISCOVERY
/* USER CODE END Private defines */
``` 
---
#### Peripheral handle getter functions
To get access to the peripheral handles, the following code must be inserted in the `main.h`:

``` C
/* USER CODE BEGIN EFP */

/**
 * @brief The BSP of the Voice Mail Box needs to access the different peripheral handles generated by the CubeMX.
 * @details
 * When porting the project to a different microcontroller, these getters have to be manually declared here,
 * implemented in the main.cpp and used in the Platform.cpp.
 */
ADC_HandleTypeDef* getADC_POT0();
ADC_HandleTypeDef* getADC_POT1();

UART_HandleTypeDef* getUART_DEBUG();
UART_HandleTypeDef* getUART_WIFI();

I2C_HandleTypeDef* getI2C_Handle();
I2S_HandleTypeDef* getI2S_CODEC();

/* USER CODE END EFP */
```

Implement the functions in the `main.c`.
The instance name may be different. You can find the correct name in the `main.c` on the top where CUBE MX has generated the structs instances.
``` C
/* USER CODE BEGIN PV */
ADC_HandleTypeDef* getADC_POT0()
{
    return &hadc1;
}
ADC_HandleTypeDef* getADC_POT1()
{
    return &hadc2;
}
UART_HandleTypeDef* getUART_DEBUG()
{
    return &huart3;
}
UART_HandleTypeDef* getUART_WIFI()
{
    return &huart6;
}
I2C_HandleTypeDef* getI2C_Handle()
{
    return &hi2c1;
}
I2S_HandleTypeDef* getI2S_CODEC()
{
    return &hi2s2;
}
/* USER CODE END PV */
```
---
#### Peripheral GPIOs
CUBE MX sometimes generates macros using the user labels from the IOC file. But for the H755 for example, that process is not made during code generation.
In that case these definitions must been made manually and look like this:
``` C
// Buttons
// BTN0 is on PD15
#define BTN0_GPIO_Port GPIOD
#define BTN0_Pin GPIO_PIN_15
// BTN1 is on PE11
#define BTN1_GPIO_Port GPIOE
#define BTN1_Pin GPIO_PIN_11
// BTN2 is on PE14
#define BTN2_GPIO_Port GPIOE
#define BTN2_Pin GPIO_PIN_14
// BTN3 is on PE13
#define BTN3_GPIO_Port GPIOE
#define BTN3_Pin GPIO_PIN_13

// LEDs
// LED0 is on PA8
#define LED0_GPIO_Port GPIOA
#define LED0_Pin GPIO_PIN_8
// LED1 is on PG12
#define LED1_GPIO_Port GPIOG
#define LED1_Pin GPIO_PIN_12

// Debug pins
// DBG0 is on PD3
#define DBG0_GPIO_Port GPIOD
#define DBG0_Pin GPIO_PIN_3
// DBG1 is on PD4
#define DBG1_GPIO_Port GPIOD
#define DBG1_Pin GPIO_PIN_4
// DBG2 is on PD5
#define DBG2_GPIO_Port GPIOD
#define DBG2_Pin GPIO_PIN_5

// Audio codec
// CODEC_NRESET is on PG14
#define CODEC_NRESET_GPIO_Port GPIOG
#define CODEC_NRESET_Pin GPIO_PIN_14
```
That macros will be used in the `Platform.cpp` for creating the `DigitalPin` instances.

``` C++
// Inside the Platform.cpp
// Fill in the GPIO_TypeDef* and pin values, generated from the CUBEMX for the buttons
DigitalPin& Platform::getButton(Button index)
{
    // Creating static instances of the DigitalPin class for each button
    // The constructor of the DigitalPin class takes the <GPIO_TypeDef*>, <pin number> and <isInverted> as parameters
    // On this board the buttons are active high, so the isInverted parameter is set to false or can be omitted
    static DigitalPin button[] = 
    {
        { BTN0_GPIO_Port, BTN0_Pin },  // <---
        { BTN1_GPIO_Port, BTN1_Pin },
        { BTN2_GPIO_Port, BTN2_Pin },
        { BTN3_GPIO_Port, BTN3_Pin }
    };
    return button[index];
}
```
Make sure you use the same macro names as they already are used in the `Platform.cpp`, so that the `Platform.cpp` can be let unchanged. Otherwise the `Platform.cpp` must be edited to fit your custom peripheral GOPIO macro names.

---
### Project Properties
Open the **Properties** window for the CM7 sub project.
Navigate to **C/C++ General->Paths and Symbols**.

#### Includes
Click **Add** and paste the following path: `${ProjDirPath}/../../../../BSP_VoiceMailBox/inc`.
This Path only works if the project was created in the same location as this project.
In the case, you create a project on a different location, you have to change the path accordingly.
Set the checkmarks: **Add to all configurations** and **Add to all languages**.
Confirm it by pressing the **OK** button.

For some reason, FATFS may not added to both C and C++, check that by clicking on the languages **GNU C** and **GNU C++**. If the includes for FATFS are only on C, then add them to the C++ language too.

#### Source Locations
Click **Link Folder** and check the checkmark **Link to folder in the file system**.
Click on **Variables...**, add a **New** variable and name it: `BSP_VoiceMailBox` and the location: `${PROJECT_LOC}\..\..\..\..\BSP_VoiceMailBox\src`.
Click **OK**, select the newly created variable and click **OK** again, and then again **OK**.
Now switch the **Configuration** to the other one (Debug -> Release or Release -> Debug).
Now click **Add Folder**, select **BSP_VoiceMailBox** from the list and click **OK**.

#### Libraries
##### SpiritDSP MP3 
The spiritDSP MP3 library was used in the [X-CUBE-AUDIO](https://www.st.com/en/embedded-software/x-cube-audio.html) example and therefore also used in this Project.
- In the `Libraries` section click on `Add...` and fill the following in the dialog:
  - **File**: `_mp3decoder_cortex_m7_v2.2.0`
  - **Add to all configurations**: `checked`
  - **Add to all languages**: `checked`
   `OK`
<br>
<br>

- In the `Library Paths` section click on `Add...` and fill the following in the dialog:
  - **Directory**: `${ProjDirPath}/../../../../BSP_VoiceMailBox/Middlewares/ST/STM32_Audio/Codecs/SpiritDSP_MP3_Dec/lib`
  - **Add to all configurations**: `checked`
  - **Add to all languages**: `checked`
   `OK`
<br>
<br>

> [!CAUTION]  
> Sadly there is no encoder library available for the M7. I don't know why and did't find it someware else.
A other MP3 encoder must be used and implemented which is not very straight forward.
An other way would be to use the M4 core. In that case it is the same way as it is for the F469 Discovery board.

###### Floating point unit settings
Navigate to `C/C++ Build->Settings` and in the `MCU/MPU Settings` set the **floating point ABI** to `Mix HW/SW implementation`, otherwise the project will not compile.
Do that for both configurations: **Debug** and **Release**

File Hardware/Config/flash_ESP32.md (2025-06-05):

# Flash ESP32

If you have soldered ESP32 on Board instead of using Pmod ESP32, you will have to flash the AT-Command Firmware in order to use it accordingly.

precompiled binaries can be found [here](https://github.com/espressif/esp-at/actions), if you want the most up-to-date version. If not, use the binaries in this [folder](../esp32-wroom-at/build/).

to flash it, you can follow the istructions from [espressif](https://docs.espressif.com/projects/esptool/en/latest/esp32/esptool/flashing-firmware.html)

## Connector J303

Position:  
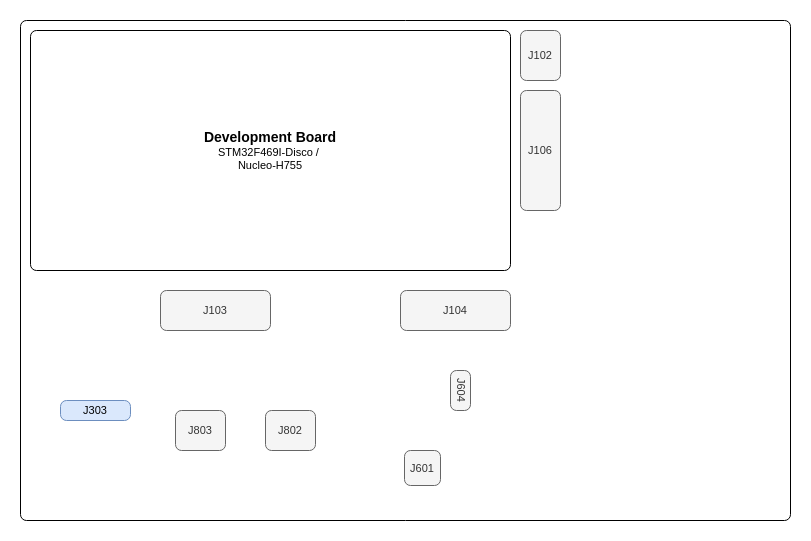
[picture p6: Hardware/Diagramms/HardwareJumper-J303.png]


Jumper to enter Boot-Mode:  


# Pinout J303:

| Function | Pin | Info |
|---|-----|---|
| +3V3 | 1 | |
| Boot | 2 | |
| Gnd | 3 | |
| RX0 | 4 | |
| TX0 | 5 | |
| Gnd | 6 | |

---

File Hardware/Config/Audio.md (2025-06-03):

# Configure Audio Codec / Periphery

## Jumper J104 (use to connect On Board Mic to Codec)

Position:  
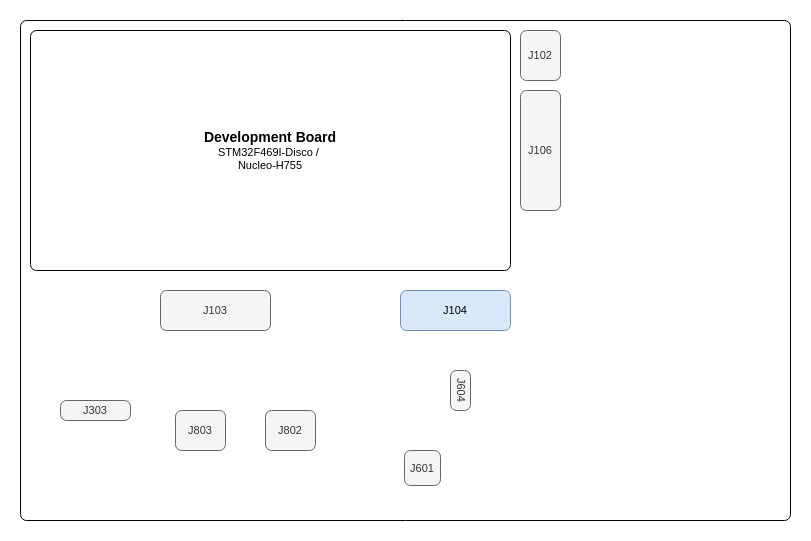
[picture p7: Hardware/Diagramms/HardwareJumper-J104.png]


Jumper for F469:  
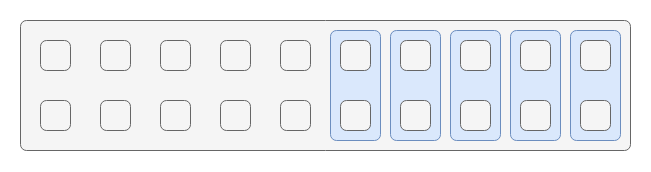
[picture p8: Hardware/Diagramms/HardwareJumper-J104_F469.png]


Jumper for H755:  
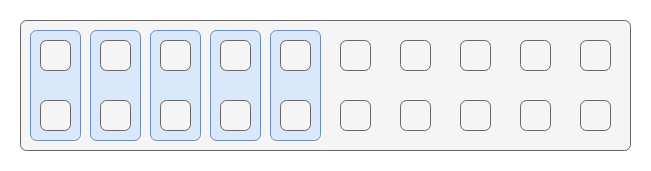
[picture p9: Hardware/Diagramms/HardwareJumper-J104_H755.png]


---

## Jumper J604

Position:  
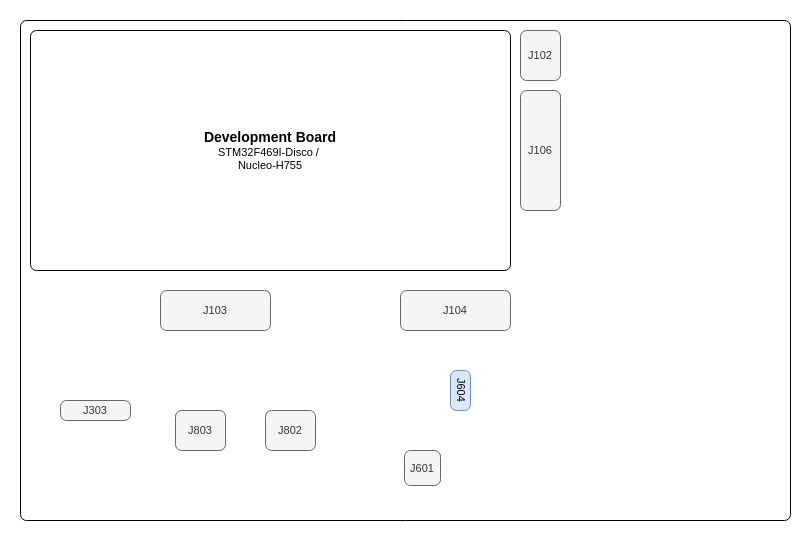
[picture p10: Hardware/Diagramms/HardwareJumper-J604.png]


Jumper for dynamic feedback:  


Jumper for static feedback:  


Jumper for no feedback:  


## Jumper J601

Position:  
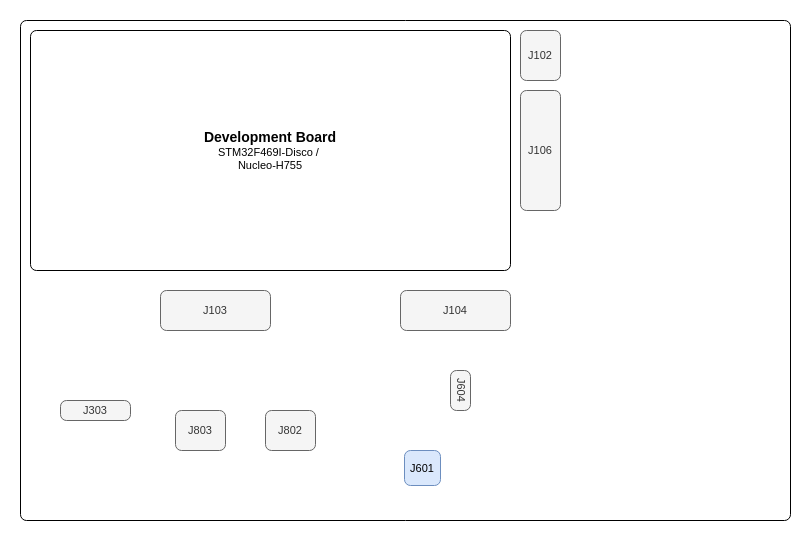
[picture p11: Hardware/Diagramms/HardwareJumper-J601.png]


enable Microphone for left channel:  
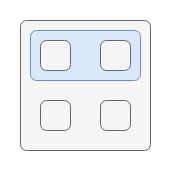
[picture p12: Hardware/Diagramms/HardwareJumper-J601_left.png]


enable Microphone for right channel:  
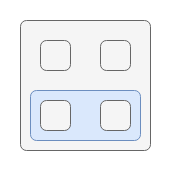
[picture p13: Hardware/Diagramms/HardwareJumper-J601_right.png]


DIP Switch SW601 (blue for recommended settings)

```mermaid
block-beta
        columns 2
        a0["enable DC Blocking Cap left"]
        b0["Short DC Blocking Cap left"]
        a1["enable DC Blocking Cap right"]
        b1["Short DC Blocking Cap right"]
        a2["Disconnect Diff Minus as neg. Output"]
        b2["Connect Diff Minus as neg. Output"]
        a3["Disconnect GND as neg. Output"]   
        b3["Connect GND as neg. Output"]    
classDef highlighter fill:#8bc8e8,stroke:#6c757d,color:#000000,stroke-width:1.5px;
class a0 highlighter
class a1 highlighter
class b2 highlighter
class a3 highlighter
```

---

# Pinout F469:

### I2S
| Function | Pin | Info |
|---|-----|---|
| I2S_SDA  | PC1 | |
| I2S_SDAe | PC2 | |
| I2S_MCLK | PC6 | |
| I2S_WCLK | PB12 | |
| I2S_BCLK | PB13 | |

### I2C
| Function | Pin | Info |
|---|-----|---|
| I2C_SDA  | PB8 | shared |
| I2C_SCL  | PB9 | shared |

### GPIOs
| Function | Pin | Info |
|---|-----|---|
| nReset | PG13 | Output |

---

# Pinout H755:

### I2S
| Function | Pin | Info |
|---|-----|---|
| I2S_SDA  | PB15 | |
| I2S_SDAe | PB4 | |
| I2S_MCLK | PC6 | |
| I2S_WCLK | PC6 | |
| I2S_BCLK | PB13 | Jumper SB8 on H755 needs to be placed |

### I2C
| Function | Pin | Info |
|---|-----|---|
| I2C_SDA  | PB8 | shared |
| I2C_SCL  | PB9 | shared |

### GPIOs
| Function | Pin | Info |
|---|-----|---|
| nReset | PG14 | Output |

---

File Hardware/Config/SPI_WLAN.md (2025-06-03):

# Configure WLAN/BLE to communicate by SPI

## J103

Position:  
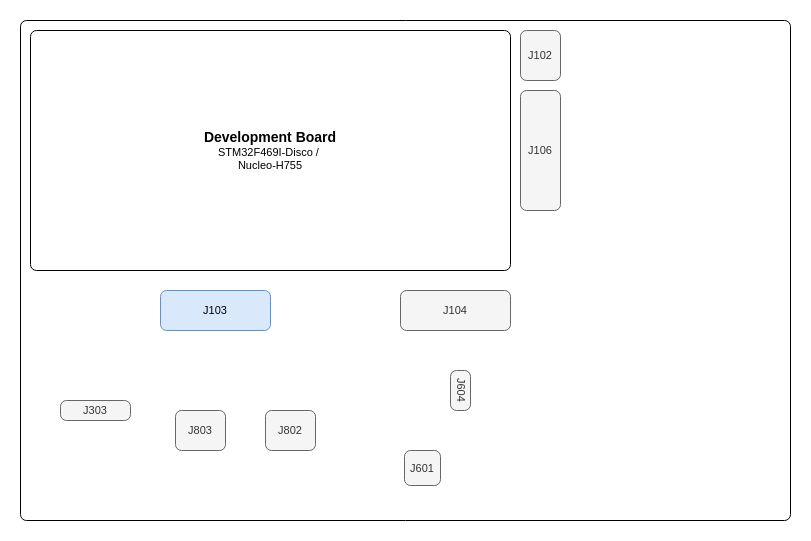
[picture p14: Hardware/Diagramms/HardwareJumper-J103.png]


Jumper:  
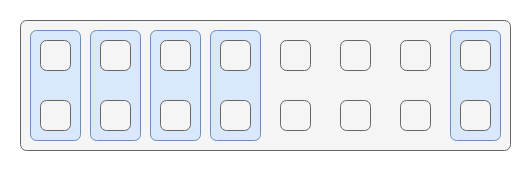
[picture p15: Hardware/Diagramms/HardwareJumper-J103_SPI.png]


Jumper J103 set WLAN/BLE using SPI
```mermaid
block-beta
    block
        columns 8
        a0["Set"]
        a1["Set"]
        a2["Set"]
        a3["Set"]
        a4["n.c."]
        a5["open"]
        a6["open"]
        a7["Set"]
    end

classDef highlighter fill:#8bc8e8,stroke:#6c757d,color:#000000,stroke-width:1.5px;
class a0 highlighter
class a1 highlighter
class a2 highlighter
class a3 highlighter
class a7 highlighter
```

---

# Pinout F469:

### SPI
| Function | Pin | Info |
|---|-----|---|
| SPI_MOSI  | PB15 | |
| SPI_MISO | PB14 | |
| SPI_SCK | PD3 | |
| SPI_NSS | PH6 | |

---

# Pinout H755:

### SPI
| Function | Pin | Info |
|---|-----|---|
| SPI_MOSI  | PB5 | validate!!! |
| SPI_MISO | PA6 | |
| SPI_SCK | PA5 | |
| SPI_NSS | PD14 | |

---

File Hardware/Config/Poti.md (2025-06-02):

# Configure internal / external Potentiometers

## Jumpers and connections J802/J803

Position:  
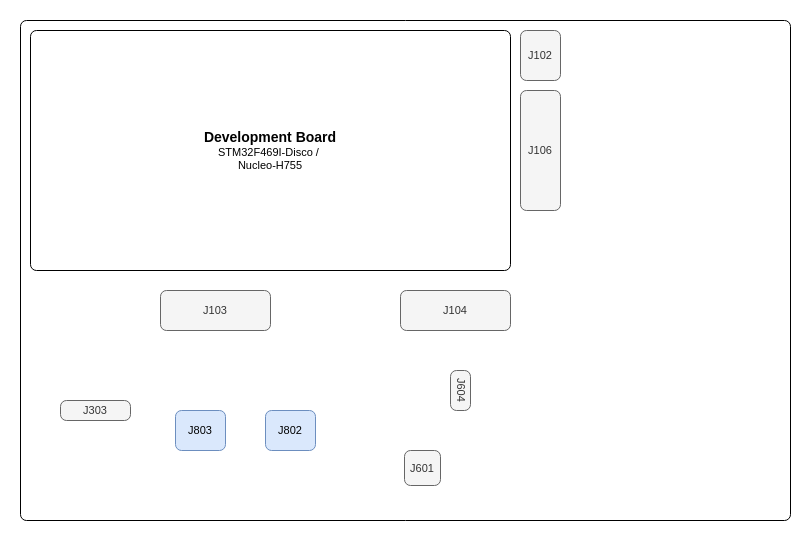
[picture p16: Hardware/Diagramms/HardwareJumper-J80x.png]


Jumper use Potentiometer on Board:  
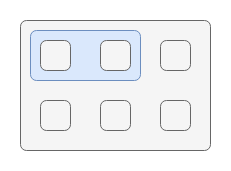
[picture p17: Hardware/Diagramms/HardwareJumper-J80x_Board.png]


Jumper use Potentiometer external:  
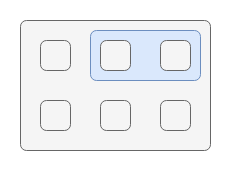
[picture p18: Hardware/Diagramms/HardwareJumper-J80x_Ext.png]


Select on-board Potentiometer
```mermaid
block-beta
    block:group1
        columns 3
        a[" Jumper for On Board \n Potentiometer "]:2
        c["Ext. Potentiometer"]
        d["VCC 3.3V"]
        e["Ext. Potentiometer"]
        f["GND"]
    end

classDef highlighter fill:#8bc8e8,stroke:#6c757d,color:#000000,stroke-width:1.5px;
class a highlighter
```

Select ext. Potentiometer
```mermaid
block-beta
    block:group1
        columns 3
        a[" On Board Potentiometer "]
        c[" Jumper for Ext. \n Potentiometer "]:2
        d["VCC 3.3V"]
        e["Ext. Potentiometer"]
        f["GND"]
    end

classDef highlighter fill:#8bc8e8,stroke:#6c757d,color:#000000,stroke-width:1.5px;
class c highlighter
```

---

# Pinout F469:

### Analog
| Function | Pin | Info |
|---|-----|---|
| Potentiometer 0 | PC4 | Input |
| Potentiometer 1 | PC3 | Input |

---

# Pinout H755

### Analog
| Function | Pin | Info |
|---|-----|---|
| Potentiometer 0 | PB1 | Input |
| Potentiometer 1 | PC3 | Input |

---

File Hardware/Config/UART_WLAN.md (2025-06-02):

# Configure WLAN/BLE to communicate by UART

## J103

Position:  


Jumper:  
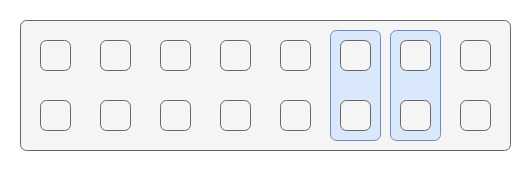
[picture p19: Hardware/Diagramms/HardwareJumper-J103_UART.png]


Jumper J103 set WLAN/BLE using UART
```mermaid
block-beta
    block
        columns 8
        a0["open"]
        a1["open"]
        a2["open"]
        a3["open"]
        a4["n.c."]
        a5["set"]
        a6["set"]
        a7["open"]
    end

classDef highlighter fill:#8bc8e8,stroke:#6c757d,color:#000000,stroke-width:1.5px;
class a5 highlighter
class a6 highlighter
```

---

# Pinout F469:

### UART
| Function | Pin | Info |
|---|-----|---|
| UART_TX  | PG14 |  |
| UART_RX  | PG9 |  |

---

# Pinout H755:

### UART
| Function | Pin | Info |
|---|-----|---|
| UART_TX  | PB6 |  |
| UART_RX  | PB7 |  |

---

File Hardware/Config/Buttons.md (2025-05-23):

# Configure Buttons

## Pinout
J801 [Ext. Periphery]
```mermaid
block-beta
    block
        columns 8
        a0["5.0V"]
        a1["Led 0"]
        a2["Led 1"]
        a3["Button 0"]
        a4["Button 1"]
        a5["Button 2"]
        a6["Button 3"]
        a7["GND"]
    end

classDef highlighter fill:#8bc8e8,stroke:#6c757d,text:#000000,stroke-width:1.5px;
class a3 highlighter
class a4 highlighter
class a5 highlighter
class a6 highlighter
```

## Connection Type
In oder to connect an external button or switch use one of the button pins on connector J801.
Connect the Button so, that it connects the pin to GND.
> [!Caution]
> the button input is low active.

---

# Pinout F469:

### GPIOs
| Function | Pin | Info |
|---|-----|---|
| Button 0 | PA7 | Input |
| Button 1 | PA2 | Input |
| Button 2 | PG12 | Input |
| Button 3 | PA1 | Input |

---

# Pinout H755

### GPIOs
| Function | Pin | Info |
|---|-----|---|
| Button 0 | PD15 | Input |
| Button 1 | PE11 | Input |
| Button 2 | PE14 | Input |
| Button 3 | PE13 | Input |

---

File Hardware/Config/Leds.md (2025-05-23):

# Configure Leds

## Pinout
J801 [Ext. Periphery]
```mermaid
block-beta
    block
        columns 8
        a0["5.0V"]
        a1["Led 0"]
        a2["Led 1"]
        a3["Button 0"]
        a4["Button 1"]
        a5["Button 2"]
        a6["Button 3"]
        a7["GND"]
    end

classDef highlighter fill:#8bc8e8,stroke:#6c757d,text:#000000,stroke-width:1.5px;
class a1 highlighter
class a2 highlighter
```

## Connection Type
In oder to connect an external led use one of the led pins on connector J801 to connect the leds cathode.
Connect the annode of the led to the pos Voltage of Choice (+5V is available on the Connector).
> [!Caution]
> the led output is low active.
> do not connect a positive Voltage greater than 30V.

---

# Pinout F469:

### GPIOs
| Function | Pin | Info |
|---|-----|---|
| LED 0 | PA6 | Output |
| LED 1 | PG11 | Output |

---

# Pinout H755

### GPIOs
| Function | Pin | Info |
|---|-----|---|
| LED 0 | PA8 | Output |
| LED 1 | PG12 | Output |

---

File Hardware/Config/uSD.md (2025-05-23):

# Configure micro SD Card Slot

## H755 vs F469

If you want to use F469, use the micro SD Slot on the F469 itself.
Since H755 does not have one by default, use the one on VMBB.

---

# Pinout F469:

### SDIO
| Function | Pin | Info |
|---|-----|---|
| SD_DAT0  | PC8 | |
| SD_DAT1 | PC9 | |
| SD_DAT2 | PC10 | |
| SD_DAT3 | PC11 | |
| SD_CLK | PD2 | |
| SD_CMD | PC11 | |

### GPIOs
| Function | Pin | Info |
|---|-----|---|
| SD_DET | PG2 | Input |

---

# Pinout H755:

### SDMMC
| Function | Pin | Info |
|---|-----|---|
| SD_DAT0  | PC8 | |
| SD_DAT1 | PC9 | |
| SD_DAT2 | PC10 | |
| SD_DAT3 | PC11 | |
| SD_CLK | PC12 | |
| SD_CMD | PD2 | |

### GPIOs
| Function | Pin | Info |
|---|-----|---|
| SD_DET | PG10 | Input |

---

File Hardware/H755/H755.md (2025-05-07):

# H755 Jumper Positions

J104 [Audio]
```mermaid
block-beta
    block
        columns 10
        a0["Set"]
        a1["Set"]
        a2["Set"]
        a3["Set"]
        a4["Set"]
        a5["open"]
        a6["open"]
        a7["open"]
        a8["open"]
        a9["open"]
    end

classDef highlighter fill:#8bc8e8,stroke:#6c757d,color:#000000,stroke-width:1.5px;
class a0 highlighter
class a1 highlighter
class a2 highlighter
class a3 highlighter
class a4 highlighter
```

J106 [NFC] -> if you want to connect NFC using I2C leave all connection open
```mermaid
block-beta
    block
        columns 1
        a0["Set"]
        a1["Set"]
        a2["Set"]
        a3["Set"]
        a4["3.3V"]
        a5["GND"]
        a6["open"]
        a7["open"]
        a8["open"]
        a9["open"]
    end

classDef highlighter fill:#8bc8e8,stroke:#6c757d,color:#000000,stroke-width:1.5px;
class a0 highlighter
class a1 highlighter
class a2 highlighter
class a3 highlighter
```

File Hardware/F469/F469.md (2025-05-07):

# F469 Jumper Positions

J104 [Audio]
```mermaid
block-beta
    block
        columns 10
        a0["open"]
        a1["open"]
        a2["open"]
        a3["open"]
        a4["open"]
        a5["Set"]
        a6["Set"]
        a7["Set"]
        a8["Set"]
        a9["Set"]
    end

classDef highlighter fill:#8bc8e8,stroke:#6c757d,color:#000000,stroke-width:1.5px;
class a5 highlighter
class a6 highlighter
class a7 highlighter
class a8 highlighter
class a9 highlighter
```

J106 [NFC] -> if you want to connect NFC using I2C leave all connection open
```mermaid
block-beta
    block
        columns 1
        a0["open"]
        a1["open"]
        a2["open"]
        a3["open"]
        a4["3.3V"]
        a5["GND"]
        a6["Set"]
        a7["Set"]
        a8["Set"]
        a9["Set"]
    end

classDef highlighter fill:#8bc8e8,stroke:#6c757d,color:#000000,stroke-width:1.5px;
class a6 highlighter
class a7 highlighter
class a8 highlighter
class a9 highlighter
```

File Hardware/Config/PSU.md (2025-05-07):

# Configure Power Supply Unit

## PSU Setup
There is two ways to Supply the Eval Board:
- Supply using the Connector for ST-Link on the Eval-Boards
	- Set the Supply Jumper on H755 or F469 to STLINK
	- only connect the micro-usb to the H755 / F469
	- use only when you are certain, that your power draw is low (meaning mostly "no External Speakers")

- Supply using the USB Type-C Connector on the VMBB
	- Set the Supply Jumper on H755 or F469 to E5V
	- connect USB-C to supply on VMBB and MIcro-USB on H755 or F469 to connect programmer/debugger
	- use for permanent setup (when you are finished with the coding)
	- use when you have a more power demanding setup

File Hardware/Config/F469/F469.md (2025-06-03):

# F469 Jumper Positions
When using F469 as the main board, place the following jumpers.

## J104

Position:  


Jumper:  


## NFC
NFC can be configured to use either SPI or I2C choose one configuration:
- [SPI](NFC_SPI_F469.md)
- [I2C](NFC_I2C_F469.md)

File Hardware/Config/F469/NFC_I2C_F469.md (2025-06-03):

# NFC for F469 using I2C

Position:  
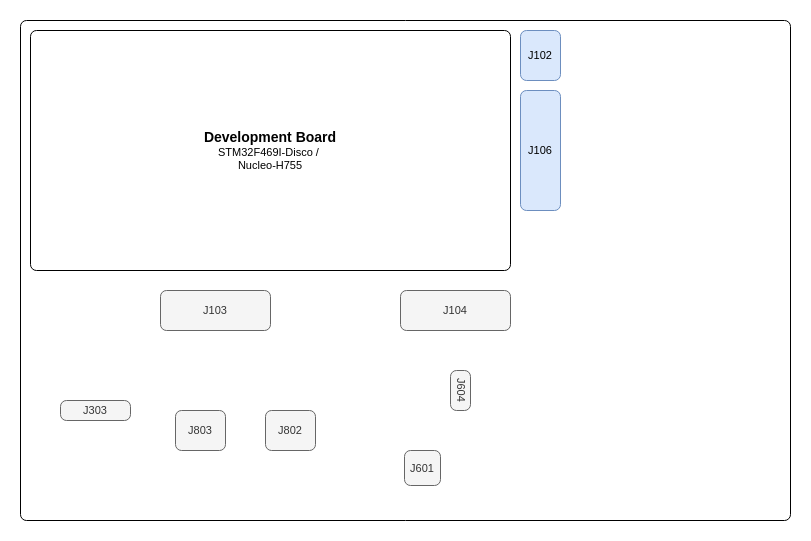
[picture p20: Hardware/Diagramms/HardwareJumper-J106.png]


## J102

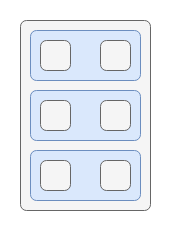
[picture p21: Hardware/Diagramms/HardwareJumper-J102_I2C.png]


## J106

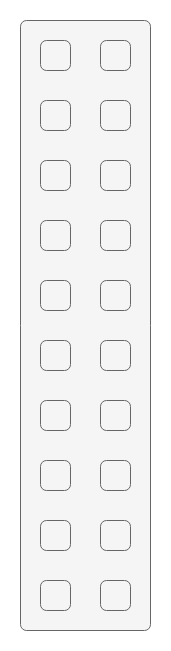
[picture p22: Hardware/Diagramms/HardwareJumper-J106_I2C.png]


---

# Pinout:

### I2C
| Function | Pin | Info |
|---|-----|---|
| I2C_SDA  | PB8 | shared |
| I2C_SDA  | PB9 | shared |

### GPIOs
| Function | Pin | Info |
|---|-----|---|
| NFC_int | PB1 | Input |

---

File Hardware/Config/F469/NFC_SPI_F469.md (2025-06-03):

# NFC for F469 using SPI

Position:  


## J102

Jumper:  
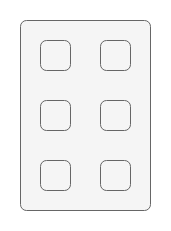
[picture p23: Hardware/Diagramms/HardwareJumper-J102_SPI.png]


## J106

Jumper:  
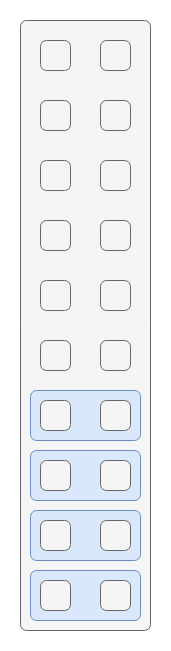
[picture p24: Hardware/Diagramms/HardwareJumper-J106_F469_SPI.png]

 
 ---

# Pinout:

### SPI
| Function | Pin | Info |
|---|-----|---|
| SPI_MOSI  | PA5 | |
| SPI_MISO | PA8 | |
| SPI_SCK | PB4 | |
| SPI_NSS | PA15 | |

### GPIOs
| Function | Pin | Info |
|---|-----|---|
| NFC_int | PB1 | Input |

---

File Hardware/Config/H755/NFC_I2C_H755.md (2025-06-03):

# NFC for H755 using I2C

Position:  


## J102

Jumper:  


## J106

Jumper:  


## J106
```mermaid
block-beta
    block
        columns 1
        a0["open"]
        a1["open"]
        a2["open"]
        a3["open"]
        a4["3.3V"]
        a5["GND"]
        a6["open"]
        a7["open"]
        a8["open"]
        a9["open"]
    end

classDef highlighter fill:#8bc8e8,stroke:#6c757d,color:#000000,stroke-width:1.5px;
```

## J106
```mermaid
block-beta
    block
        columns 1
        a0["Set"]
        a1["Set"]
        a2["Set"]
    end

classDef highlighter fill:#8bc8e8,stroke:#6c757d,color:#000000,stroke-width:1.5px;
class a0 highlighter
class a1 highlighter
class a2 highlighter
```

# Pinout:

### I2C
| Function | Pin | Info |
|---|-----|---|
| I2C_SDA  | PB8 | shared |
| I2C_SDA  | PB9 | shared |

### GPIOs
| Function | Pin | Info |
|---|-----|---|
| NFC_int | PA3 | Input |

---

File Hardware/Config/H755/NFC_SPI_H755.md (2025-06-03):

# NFC for H755 using SPI

Position:  


## J102



## J106

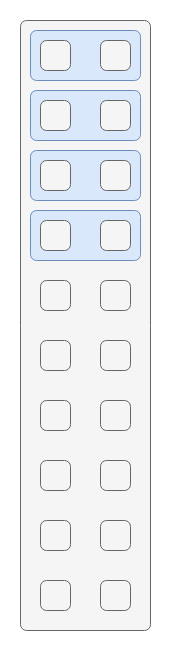
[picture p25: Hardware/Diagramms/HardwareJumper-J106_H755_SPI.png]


---

# Pinout:

### SPI
| Function | Pin | Info |
|---|-----|---|
| SPI_MOSI  | PB5 | |
| SPI_MISO | PG9 | |
| SPI_SCK | PB3 | |
| SPI_NSS | PA4 | |

### GPIOs
| Function | Pin | Info |
|---|-----|---|
| NFC_int | PA3 | Input |

---

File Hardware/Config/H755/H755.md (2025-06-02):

# H755 Jumper Positions

## J104

Position:  


Jumper:  


## NFC
NFC can be configured to use either SPI or I2C choose one configuration:
- [SPI](NFC_SPI_H755.md)
- [I2C](NFC_I2C_H755.md)

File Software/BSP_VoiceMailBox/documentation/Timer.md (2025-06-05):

# Timer
This class offers a timer that can be used to run specific code periodically.
You can find a ready to run project [here](../../Demos/F469/F469_MultiExample/README.md).

---
## Content
- [Features](#features)
- [Benefit of this timer](#benefit-of-this-timer)
- [Setup](#setup)
- [Usage](#usage)
    - [Timer with if statement](#timer-with-if-statement)
    - [Timer with callback](#timer-with-callback)
    - [Automatic restart](#automatic-restart)

---
## Features
- Timing in approximate millisecond accuracy.
- Using timer in a if statement that gets executed if the timer has expired.
- Using callback functions to execute a function when the timer has expired.

> [!NOTE]
> The Timer class does not handle time overflows.
> Since the internal used time is 64bit this would only be a problem after 3655 Years at a clock frequency of 160MHz.

---
## Benefit of this timer
A usecase for the Timer class is the following code where some code needs to be executed at a given interval. Using classical methodes this is a common solution to the problem:
``` C++
#include "BSP_VoiceMailBox.hpp"
uint32_t previousTick = HAL_GetTick();  // Record the start time

void loop()
{
    VoiceMailBox::update();
    uint32_t currentTick = HAL_GetTick();
    if ((currentTick - previousTick) >= 1000)  // 1000 ms = 1 second
    {
        previousTick = currentTick;

        // Your code to run every 1 second goes here
        HAL_GPIO_TogglePin(GPIOA, GPIO_PIN_5);  // For example, toggle an LED
    }
}
```

Using the Timer class, the same task can be done with much less and more readable code:
``` C++
#include "BSP_VoiceMailBox.hpp"
VoiceMailBox::Timer timer;

void setup()
{
    VoiceMailBox::update();
    timer.onFinish([](){
        HAL_GPIO_TogglePin(GPIOA, GPIO_PIN_5);  // For example, toggle an LED
    });
    timer.enableAutoRestart(true);
    timer.start(1000);
}
void loop()
{
    VoiceMailBox::update(); // Will update the timer objects
}
```
---
## Setup    
- Make sure the C++ application is setup in order to use this class
You can find the instructions on how to do so [here](CppFromC.md).

---
## Usage
#### Timer with if statement
``` C++ 
#include "BSP_VoiceMailBox.hpp"

VoiceMailBox::Timer* timer = nullptr;
void setup()
{
    VoiceMailBox::setup();

    timer = new VoiceMailBox::Timer();
    timer->start(1000); // time in ms
}
void loop()
{
    using namespace VoiceMailBox;
    VoiceMailBox::update();

    if (timer->hasFinished())
    {
        timer->start();
        println("Cyclic print after " + std::to_string(getTickCountInMs())+ "ms");
    }
}
```
---

#### Timer with callback
``` C++ 
#include "BSP_VoiceMailBox.hpp"

VoiceMailBox::Timer* timer = nullptr;
void setup()
{
    using namespace VoiceMailBox;
    VoiceMailBox::setup();

    timer = new VoiceMailBox::Timer([]() {
            timer->start(); // Restart the timer for the next callback
            println("Cyclic print after " + std::to_string(getTickCountInMs()) + "ms");
        });
    timer->start(1000);
}
void loop()
{
    VoiceMailBox::update();
}
```
---

#### Automatic restart
``` C++ 
#include "BSP_VoiceMailBox.hpp"

VoiceMailBox::Timer* timer = nullptr;
void setup()
{
    using namespace VoiceMailBox;
    VoiceMailBox::setup();

    timer = new VoiceMailBox::Timer([]() {
            println("Cyclic print after " + std::to_string(getTickCountInMs()) + "ms");
        });
    timer->enableAutoRestart(true); // Enable auto-restart
    timer->start(1000);
}
void loop()
{
    VoiceMailBox::update();
}
```
---

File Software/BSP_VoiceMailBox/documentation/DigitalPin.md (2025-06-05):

# DigitalPin
This class can be used to write or read a digital pin state, depending on the configuration from within CubeMX.
You can find a ready to run project [here](../../Demos/F469/F469_MultiExample/README.md).

---
## Content
- [Features](#features)
- [Setup](#setup)
- [Usage](#usage)
    - [Simple](#simple)
    - [Use button callbacks](#use-button-callbacks)

---
## Features
For a pin, configured as input:
- Specify if the pin is inverted or not
- Read pin value
- Attach callbacks for events: **Falling**, **Rising** and **High**.

For a pin, configured as output:
- Specify if the pin is inverted or not
- Set pinstate to **LOW** or **HIGH**
- Toggle current pin state

---
## Setup
- Inside CubeMX, select a pin and configure it as **GPIO_Output** or **GPIO_Input**.
- Define a **User Label** for that pin in order to find it faster after code generation.
- Start the code generation and open the code editor.
- Make sure the C++ application is setup in order to use this class
You can find the instructions on how to do so [here](CppFromC.md).

---
## Usage
### Simple
The macros are generated by the CubeMX code generator
``` C++ 
// main.h
// ...

// Macro, created by the CubeMX code generator using the 
// UserLabel "LED1" (GPIO_Output)
#define LED1_Pin GPIO_PIN_11
#define LED1_GPIO_Port GPIOG

// UserLabel "BTN1" (GPIO_Input)
#define BTN1_Pin GPIO_PIN_12
#define BTN1_GPIO_Port GPIOG
```

To use the DigitalPin class, a c++ function is needed, therefore the following code is not inside the **main.c** but in a **Application.cpp**.
You can find instructions on how to setup a c++ function that can be called in the main.c [here](CppFromC.md).
``` C++ 
// Application.cpp
#include "BSP_VoiceMailBox.hpp" // includes "peripherals/digitalPin.hpp"

// using a namespace globaly is not recommended for production
// but it simplyfies the example here
using namespace VoiceMailBox; 

// Create a DigitalPin object
// Specify the port and pin, given by the macros
DigitalPin led1(LED0_GPIO_Port, LED0_Pin);
DigitalPin button1(BTN1_GPIO_Port, BTN1_Pin);

// Called periodically
void loop()
{
    // Set the pin to a high state
    led1.set(true);

    // Toggle the pin
    led1.toggle();

    // Reads the pin state
    bool buttonIsPressed = button1.get();
}
```
---
### Use button callbacks
When the DigitalPin is used as input, callback functions can be subscribed which get called when the pin state changes.
>:bulb: Pin change detection is not implemented using interrupts.

>:bulb: Only one callback for each of the 3 events are allowd.
Calling the **button1.setOnFallingEdgeCallback(...);** twice will overwrite the first callback function assigned to that specific pin event.

```C++
// Application.cpp
#include "BSP_VoiceMailBox.hpp" // includes "peripherals/digitalPin.hpp"
#include <stdio.h>

// using a namespace globaly is not recommended for production
// but it simplyfies the example here
using namespace VoiceMailBox; 

// Create a DigitalPin object
// Specify the port and pin, given by the macros
DigitalPin button1(BTN1_GPIO_Port, BTN1_Pin);

// Declare a callback function
void callbackWhenBtnDown(VoiceMailBox::DigitalPin& btn);

// Called once on startup after peripheral initialisation
void setup()
{
    // Setup the platform
    VoiceMailBox::setup();

    // Subscribing using a lambda function as callback
    button1.setOnFallingEdgeCallback([](DigitalPin&)    
        {
            // This code gets executed when the pin state gets 
            // from high to low.
            printf("Button pressed down");
        });
    
    button1.setOnRisingEdgeCallback([](DigitalPin&)    
        {
            // This code gets executed when the pin state gets 
            // from low to high.
            printf("Button released");
        });

    // Subscribing without a lamda function as callback
    button1.setOnDownCallback(callbackWhenBtnDown);
}

// Called periodically after setup
void loop()
{
    // Needs to be called periodically
    // This function checks the pin state change and triggers the callback functions
    button1.update();

    // The button1.update() already gets called from within this function:
    VoiceMailBox::update();
    // Therefore, if you put the VoiceMailBox::update(); in the loop, 
    // updating buttons must not be done manually.
}

// Gets called by the DigitalPin class automatically in its update function.
void callbackWhenBtnDown(VoiceMailBox::DigitalPin& btn)
{
    printf("Button is pressed");
}
```

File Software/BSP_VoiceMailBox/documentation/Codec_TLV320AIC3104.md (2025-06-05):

# Codec_TLV320AIC3104 Audio codec
>The TLV320AIC3104 is a low-power stereo audio codec with stereo headphone amplifier, 
as well as multiple inputs and outputs that are programmable in single-ended or fully differential configurations. 
The device includes extensive register-based power control is included, thus enabling stereo 48-kHz DAC
playback as low as 14 mW from a 3.3-V analog supply, 
making the device ideal for portable battery-powered audio and telephony applications.

Source from the datasheet: [TLV320AIC3104](https://www.ti.com/product/de-de/TLV320AIC3104)
You can find a ready to run project [here](../../Demos/F469/F469_MultiExample/README.md).

---
## Content
- [Features](#features)
- [Setup](#setup)
- [Usage](#usage)
  - [Modify main.h and main.c](#modify-mainh-and-mainc)
  - [Inside the C++ Application](#inside-the-c-application)
- [Performance tracking](#performance-tracking)
  - [Results](#results)
    - [Good processing utilizatuion](#good-processing-utilizatuion)
    - [Okey processing utilization](#okey-processing-utilization)
    - [Bad processing utilization](#bad-processing-utilization)
    - [Worst processing utilization](#worst-processing-utilization)
  - [Finding a good utilization](#finding-a-good-utilization)
- [Currently available signal path](#currently-available-signal-path)

---
## Features
This codec is very complex and features much more than needed for the Voice Mail Box.
The most features are therefore not implemented into the class for easy usage.
The following features are implemented so far:
- Starting and stopping of the I2S DMA
- Easy access to the microphone and speaker data arrays.
- Performance benchmarking for checking audio processing time vs DMA time
- Setting the microphone gain in dB
  
---
## Setup
The audio codec uses a I2C for configuration, a I2S for audio sample transfer and an digital reset pin.
Visit the following pages to setup a I2C, I2S one digital output pin.<br>
[I2C setup](I2C.md/#setup)<br>
[I2S setup](I2S.md/#setup)<br>
[Digital Pin setup](DigitalPin.md/#setup)<br>
Make sure the C++ application is setup in order to use this class
You can find the instructions on how to do so [here](CppFromC.md).

---
## Usage
CubeMX generates a **I2S_HandleTypeDef** and **I2C_HandleTypeDef** instance in the **main.c**
The **Codec_TLV320AIC3104** class needs access to these handles. Since the C++ code can't be used directly in the **main.c**, another way of getting to the handle is needed.

#### Modify main.h and main.c
In the **main.h** create a get function that returns a pointer to the handles.
``` C
// main.h

// Function declaration
I2S_HandleTypeDef* getI2S_handle();
I2C_HandleTypeDef* getI2C_handle();
```

``` C
// main.c

/* Private variables generated by CubeMX */
I2S_HandleTypeDef hi2s1;
I2C_HandleTypeDef hi2c1;

/* USER CODE BEGIN PV */
// Function implementation
I2S_HandleTypeDef* getI2S_handle()
{
    // Return the pointer to the handle
    return &hi2s1;
}
I2C_HandleTypeDef* getI2C_handle()
{
    // Return the pointer to the handle
    return &hi2c1;
}
/* USER CODE END PV */
```

#### Inside the C++ Application

``` C++ 
// Application.cpp
#include "BSP_VoiceMailBox.hpp" // includes the needed peripheral headers
#include "main.h" // Is needed to access the handle get function

// using a namespace globaly is not recommended for production
// but it simplyfies the example here
using namespace VoiceMailBox; 

Codec_TLV320AIC3104* codec = nullptr;
I2C *i2c = nullptr;

void setup()
{ 
    // Create a I2C object on which the codec is connected
    i2c = new VoiceMailBox::I2C(getI2C_Handle());

    // Create a codec object and providing the I2S and I2C haldes.
    // 1024 for the I2S buffer size which is only used when the macro "VMB_I2S_USE_STATIC_BUFFER_SIZE" is not defined in the settings.h.
    // 0x18 is the default I2C address of the TLV320AIC3104 and can be found in its datasheet.
    // GPIO_TypeDef* and pin must be passed. It is the Reset pin of the codec: PIN 31.
    codec = new Codec_TLV320AIC3104(getI2S_handle(), 1024,
                                    *i2c, 0x18,
                                    CODEC_NRESET_GPIO_Port, CODEC_NRESET_Pin);

    codec->setup();
}

// Called periodically
void loop()
{
    // Process the codecs audio data
    if (codec->isDataReadyAndClearFlag())
    {
        int16_t* txBuffer = (int16_t*)codec->getTxBufPtr();
        int16_t* rxBuffer = (int16_t*)codec->getRxBufPtr();
        uint32_t size = codec->getBufferSize();

        // Redirect capture to the output
        memcpy(txBuffer, rxBuffer, size * sizeof(int16_t));
    }
}
```

---
## Performance tracking
Processing audio happens while the audio codec already sends new audio samples. Therefore chunks of audio samples are processed and after processing the main loop waits until a new chunk of audio samples are available or requested, depending if audio gets captured or played back.
Processing the audio must not take longer than the I2S DMA needs to send/receive the new chunk of samples. If the processing takes longer than the DMA, that means that at some point, some samples are lost because the DMA overwrites samples that are not processed yet.
Measuring the time it takes to perform the signal processing vs DMA time is key to know if the application works as expected.
The AudioCodec class offers a interface that can mesure the performance ratio. That value is the processingTime devided by the DMATime and must be lower than 1. If it is larger than one, it means that the signal processing takes longer as allowed.

Make sure that the macro `VMB_ENABLE_CODEC_PERFORMANCE_MEASUREMENTS` is defined in the settings.h, otherwise no performance measurement will take place.
To use the performance mesurement, the function `codec.startDataProcessing();` must be called and at the end of processing the `codec.endDataProcessing();`.
The performance is returned by the function: `codec.getProcessingTimeRatio();`.
``` C++
#include "BSP_VoiceMailBox.hpp"
#include <memory>
void setup()
{
    VoiceMailBox::setup();
}
void loop()
{
    using namespace VoiceMailBox;
    DigitalPin& led0 = getLed(LED::LED0);
    DigitalPin& led1 = getLed(LED::LED1);

    led0.set(1);

    VoiceMailBox::update();
    AudioCodec& codec = getCodec();
    AnalogPin& potentiometer = getPotentiometer(Potentiometer::POT1);

    led0.set(0);
    if (codec.isDataReadyAndClearFlag())
    {
        // Start processing
        led1.set(1);
        codec.startDataProcessing();                              // Used to mesure processing performance
        uint32_t potentiometerValue = potentiometer.getValue();
        uint32_t delayMS = maxDelayMS - ((double)potentiometerValue * maxDelayMS / (double)potentiometer.getMaxValue()); // 0 - 100 ms

        int16_t* rxBuffer = (int16_t*)codec.getRxBufPtr();
        int16_t* txBuffer = (int16_t*)codec.getTxBufPtr();
        uint32_t bufferSize = codec.getBufferSize();

        delay(delayMS);											  // simulate processing time
        memcpy(txBuffer, rxBuffer, bufferSize * sizeof(int16_t)); // Redirect capture to the output
        codec.endDataProcessing();                                // Used to mesure processing performance
        led1.set(0);
        // End processing

        // The optimal ratio is between 0 and 1, smaller is better.
        float performanceRatio = codec.getProcessingTimeRatio();
        if (performanceRatio > 1)
        {
            println("Processing time utilization: %.2f%% ! Processing takes longer than it should !", performanceRatio * 100.0f);
        }
        else
        {
            println("Processing time utilization: %.2f%%", performanceRatio * 100.0f);
        }
    }
}
```

### Results
Below are different examples that are generated using the code above. 
The yellow graph shows the signal for the LED0 which is turned on at the start of the `loop()` function and turned off before the the codecs data ready flag gets read.
The green graph shows the signal for the LED1 which is turned on at the start when the codec has confirmed to have new audio samples available.
The green signal is turned off after the processing has finished.

> [!NOTE] 
> Both leds, LED0 and LED1 are inverted on the PCB, therefore when the signal is low, that means that the LED is actually turned on.
 
The blue graph shows the internaly used DBG0 pin which is not wired to any pin on the PCB. It is on the **GPIOC** on **GPIO_PIN_7** for the board: **F469-DISCOVERY**.
Everytime the DMA has new data ready to be processed, that is on the **DMA_half_complete_interrupt** and **DMA_complete_interrupt**, the signal gets toggled.
That means that the application has as much time as the blue signal does not change.

> [!NOTE] 
> The original logic analyzer files can be found in the folder **images** 
> **.sal** files can be opened using the free software: [Logic](https://www.saleae.com/de)

#### Good processing utilizatuion
<tr>
<td>
<figure style="text-align: center;">
    
    <figcaption>Figure 1: Good I2S DMA vs Processing Time Utilization</figcaption>
</figure>
</td>
</tr>

`Figure 1` shows a good processing time diagram. The CPU is spending the most time waiting for new data to arrive from the I2S DMA.
Processing the data does take much less time than the DMA needs to gather new samples.
This is a very good situation.

#### Okey processing utilization
<tr>
<td>
<figure style="text-align: center;">
    
    <figcaption>Figure 2: Okey I2S DMA vs Processing Time Utilization</figcaption>
</figure>
</td>
</tr>

`Figure 2` shows a utilization that is okey because the processing is always finished before the DMA has gathered new data.

#### Bad processing utilization
<tr>
<td>
<figure style="text-align: center;">
    
    <figcaption>Figure 3: Bad I2S DMA vs Processing Time Utilization</figcaption>
</figure>
</td>
</tr>

`Figure 3` shows a bad utilization because it does not take much until the processing part uses as much time as the DMA. Very little time margin left.

#### Worst processing utilization
<tr>
<td>
<figure style="text-align: center;">
    
    <figcaption>Figure 4: Worst I2S DMA vs Processing Time Utilization</figcaption>
</figure>
</td>
</tr>

`Figure 4` shows a very bad utilization, you will hear the result when running the example. That is because the processing task takes so much time, it will not be able to process all samples and therefore loose some which can be heared.

### Finding a good utilization
Depending on the task of signal processing that takes place to process the audio data, it may be easy or difficult to get a good utilization.
The simplest indicator is the function used in the code example above: `float performanceRatio = codec.getProcessingTimeRatio();`.
Use that indicator to find out if something has to be done or if everything is fine.
If the utilization value is **larger than 1.0**, things have to change. 
**Possible solutions:**
- Make the processing code faster (may be difficult sometimes)
- Increase the I2S DMA buffer size. [Click here](I2S.md/#inside-the-c-application) to learn how to define the I2S DMA buffer size.

---
## Currently available signal path
<tr>
<td>
<figure style="text-align: center;">
    
</figure>
</td>
</tr>

The constructor of the Codec_TLV320AIC3104 class configures the codec so that the signal path in the picture above is used for input (orange) and output (green).
The custom PCB offers a second audio output path using **LEFT_LOP**, **LEFT_LOM** and **RIGHT_LOP**, **RIGHT_LOM** outputs that are used to connect speakers on the connector **J603**.
To use these, a other configuration must be made in order to redirect the audio signal to that outputs.
The image shows which register must be edited in order to acheave different signal paths.

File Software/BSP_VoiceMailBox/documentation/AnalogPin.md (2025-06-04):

# AnalogPin
This class can be used for easy access of analog input values provided by a ADC.
You can find a ready to run project [here](../../Demos/F469/F469_MultiExample/README.md).

---
## Content
- [Features](#features)
- [Setup](#setup)
- [Usage](#usage)

---
## Features
- Reading of the ADC value from one pin

Currently multiple pins from the same ADC are not supported.

---
## Setup
- Inside CubeMX, select a pin and configure it as **ADCX_INXX**.
- Start the code generation and open the code editor.
- Make sure the C++ application is setup in order to use this class
You can find the instructions on how to do so [here](CppFromC.md).
  
---
## Usage
In the `main.c` the ADC handle gets created. That is needed to pass to the constructor of the AnalogPin class. Since the C++ code can't be used directly in the **main.c**, another way of getting to the handle is needed.

#### Modify main.h and main.c
In the **main.h** create a get function that returns a pointer to the handle we want.
``` C
// main.h

// Function declaration
ADC_HandleTypeDef* getADC_handle();
```

``` C
// main.c

/* Private variables generated by CubeMX */
ADC_HandleTypeDef hadc1;

/* USER CODE BEGIN PV */
// Function implementation
ADC_HandleTypeDef* getADC_handle()
{
    // Return the pointer to the handle
    return &hadc1;
}
/* USER CODE END PV */
```

#### Inside the C++ Application
``` C++ 
// Application.cpp
#include "BSP_VoiceMailBox.hpp" // includes "peripherals/i2c.hpp"
#include "main.h" // Is needed to access the handle get function

// using a namespace globaly is not recommended for production
// but it simplyfies the example here
using namespace VoiceMailBox; 

// Create a I2C object and providing the handle from the main.c
AnalogPin analogPin(getADC_handle());

// Called periodically
void loop()
{
    println("Value 0: %d", analogPin.getValue());
    delay(100);
}
```

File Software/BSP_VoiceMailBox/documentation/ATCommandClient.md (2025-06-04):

# ATCommandClient
This class is used to communicate with a device that uses [AT-Commands](https://docs.espressif.com/projects/esp-at/en/latest/esp32/AT_Command_Set/Basic_AT_Commands.html).
In this project, the class is used to communicate with the ESP32  using the UART interface.
You can find a ready to run project [here](../../Demos/F469/F469_MultiExample/README.md).

---
## Content
- [Features](#features)
- [Setup](#setup)
- [Usage](#usage)
  - [Connecting to WiFi](#connecting-to-wifi)
  - [Upload file to server](#upload-file-to-server)
  - [Download file from server](#download-file-from-server)
- [How it works behind the scenes](#how-it-works-behind-the-scenes)
  - [Uploading a file](#uploading-a-file)
  - [Downloading a file](#downloading-a-file)

---
## Features
* Function to connect to a WiFi
* Function to send a file to a server
* Function to download a file from a server
* Function to send custom AT-Commands

---
## Setup
* In the IOC, setup the [UART](../../Demos/F469/F469_HelloAudio/README.md/#wifi-esp32) on which, in this case the ESP32, is connected to.
* Setup the [test server](TestServer.md) in order to be able to upload/download files.
* Make sure the C++ application is setup in order to use this class
You can find the instructions on how to do so [here](CppFromC.md).
  
---
## Usage
---
### Connecting to WiFi
Inside your applications C++ code, this code snippet can be used. 
``` C++
using namespace VoiceMailBox;
ATCommandClient& pmodESP = getPmodESP();
if(pmodESP.connectToWifi("WIFI_SSID", "WIFI_PASSWORD"))
{
    println("Connected to WIFI");
}
else
{
    println("Failed to connect to WIFI");
}
```

---
### Upload file to server
Inside your applications C++ code, this code snippet can be used. 
Make sure that the ATCommandClient object is already connected to a WiFi. 
``` C++
using namespace VoiceMailBox;
ATCommandClient& pmodESP = getPmodESP();
if (pmodESP.sendFileToServer("test.txt", "devicesbackend/upload/", "192.168.137.1", 8000))
    println("File sent successfully");
else
    println("Failed to send file");
```

---
### Download file from server
Inside your applications C++ code, this code snippet can be used. 
Make sure that the ATCommandClient object is already connected to a WiFi. 
``` C++
using namespace VoiceMailBox;
ATCommandClient& pmodESP = getPmodESP();
if (pmodESP.downloadFileFromServer("test.txt", "media/test.txt", "192.168.137.1", 8000))
    println("File downloaded successfully");
else
    println("Failed to download file");
```

---
## How it works behind the scenes
### Uploading a file
Below are all the commands used to upload a file in chronological order.
Thats what happens when the `pmodESP.sendFileToServer("test.txt", "devicesbackend/upload/", "192.168.137.1", 8000)` is called.

1) Open a TCP connection to the server 
   `AT+CIPSTART="TCP","192.168.137.1",8000\r\n`

2) Wait for the responce from the ESP32:
   `CONNECT\r\n` && `\r\nOK\r\n`

3) Specify how many bytes we send to the ESP32
   After receiving that many bytes, the ESP32 will automatically send a packet to the server.
   That must not nessesary be the whole HTTP header and file content. More about that later.
   `AT+CIPSEND=238\r\n`
   
4) Wait for the response from the ESP32:
   `\r\nOK\r\n\r\n>`
   It is important that the `>` is at the end, indicating that the ESP now waits for packet data.

5) Sending the HTTP POST request as the first package
   ```
   POST /devicesbackend/upload/ HTTP/1.1\r\n
   Host: 192.168.137.1:8000\r\n
   Content-Type: multipart/form-data; boundary=ESP\r\n
   Content-Length: 147\r\n
   \r\n
   --ESP\r\n
   Content-Disposition: form-data; name="test"; filename="test.txt"\r\n
   Content-Type: text/plain\r\n
   \r\n
   ```

> [!NOTE] 
> The `Content-Length` must be specified in order for the server to know how many bytes are usable data.
> This size is not the sice of the whole packet it self, it is the size of the following part:
> ```
> \r\n
> --ESP\r\n
> Content-Disposition: form-data; name="test"; filename="test.txt"\r\n
> Content-Type: text/plain\r\n
> \r\n
> This is a test file for upload.\r\n
> \r\n
> --ESP--\r\n
> ```
>
> 

1) The ESP32 has now received 238 bytes and will respond with:
   `\r\nRecv 238 bytes\r\n`
   and shortly after with:
   `\r\nSEND OK\r\n`
   The first package was sent successfully.

2) Starting a new package since the file data is not sent yet.
   Again define how many bytes the ESP32 will receive for the second package.
   `AT+CIPSEND=33\r\n`

3) Wait for the response from the ESP32:
   `\r\nOK\r\n\r\n>`
   It is important that the `>` is at the end, indicating that the ESP now waits for packet data.

4) Now the file content starts
   `This is a test file for upload.\r\n`

5)  The ESP32 has now received 238 bytes and will respond with:
   `\r\nRecv 33 bytes\r\n`
   and shortly after with:
   `\r\nSEND OK\r\n`
   The first package was sent successfully.

> [!NOTE] 
> If the file is large, it gets split in to chunks of **1024** bytes each.
> In that case the steps 7, 8, 9 and 10 are repeated until all bytes of the file have been sent.

11) Now the file has been sent completle but the communication is not done.
    The end of the content must be signalized. For that, a new packet gets created.
    `AT+CIPSEND=11\r\n`

12) Wait for the response from the ESP32:
   `\r\nOK\r\n\r\n>`
   It is important that the `>` is at the end, indicating that the ESP now waits for packet data.

13) Now the end string gets sent, which was specified in the header at the beginning.
    `\r\n--ESP--\r\n`

14) The ESP32 has now received 238 bytes and will respond with:
   `\r\nRecv 11 bytes\r\n`
   and shortly after with:
   `\r\nSEND OK\r\n`
   The first package was sent successfully.

15) The connection can now be closed.
    `AT+CIPCLOSE\r\n`

16) The ESP32 will respond with
    `CLOSED\r\n\r\nOK\r\n`

The file should appear on the server now.

### Downloading a file
Below are all the commands used to upload a file in chronological order.
Thats what happens when the `pmodESP.downloadFileFromServer("test.txt", "media/test.txt", "192.168.137.1", 8000)` is called.

1) Open a TCP connection to the server 
   `AT+CIPSTART="TCP","192.168.137.1",8000\r\n`

2) Wait for the responce from the ESP32:
   `CONNECT\r\n` && `\r\nOK\r\n`

3) Specify how many bytes we send to the ESP32
   After receiving that many bytes, the ESP32 will automatically send a packet to the server.
   `AT+CIPSEND=96\r\n`

4) Wait for the response from the ESP32:
   `\r\nOK\r\n\r\n>`
   It is important that the `>` is at the end, indicating that the ESP now waits for packet data.

5) Sending the HTTP GET request as the first package   
   ```
   GET /media/file.txt HTTP/1.1\r\n
   Host: 192.168.137.1:8000\r\n
   User-Agent: ESP32\r\n
   Connection: close\r\n
   \r\n
   ```

6) The ESP32 has now received 238 bytes and will respond with:
   `\r\nRecv 96 bytes\r\n`
   and shortly after with:
   `\r\nSEND OK\r\n`
   The first package was sent successfully.

7) After that the ESP32 already starts to send the packet from the server.
   ```
   \r\n
   +IPD,397:HTTP/1.1 200 OK\r\n
   Date: Sun, 01 Jun 2025 09:11:17 GMT\r\n
   Server: WSGIServer/0.2 CPython/3.13.3\r\n
   Content-Type: text/plain\r\nContent-Length: 33\r\n
   Content-Disposition: inline; filename="file.txt"\r\n
   Last-Modified: Sun, 01 Jun 2025 09:11:16 GMT\r\n
   X-Frame-Options: DENY\r\n
   X-Content-Type-Options: nosniff\r\n
   Referrer-Policy: same-origin\r\n
   Cross-Origin-Opener-Policy: same-origin\r\n
   \r\n
   This is a test file for upload.\r\n
   ```

> [!NOTE] 
> The ESP32 will send a text with the syntax: `+IPD,XXX:` 
> The number `XXX` represents the amount of bytes that do follow after.
> The STM32 must receive that many bytes and then process it. 
>
> If the file is large, multiple such chunks will arrive.
> In that case the ESP32 will send its next `+IPD,XXX:` right after the previous bytes have been sent.

8) At the end the ESP32 will send:
   `\r\nCLOSED\r\n`

9) The filename can be extracted out of the first received chunk.
10) The file content statrts after `\r\n\r\n` was found.

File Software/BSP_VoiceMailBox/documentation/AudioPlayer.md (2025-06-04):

# AudioPlayer
This class manages the dataflow from the SD-card to the microphone.
You can find a ready to run project [here](../../Demos/F469/F469_MultiExample/README.md).

---
## Content
- [Features](#features)
- [Setup](#setup)
- [Usage](#usage)
    - [Basic usage](#basic-usage)
    - [Using the debug Pin](#using-the-debug-pin)

## Features
- Start playback
- Stop playback
- Pause/Resume playback
- Display optional debug information on a digital pin for performance measurement and timing constraint check.

## Setup
- Make sure the C++ application is setup in order to use this class
  You can find the instructions on how to do so [here](CppFromC.md).

## Usage
### Basic usage
A AudioPlayer object can be instantiated in the Application.cpp.
The codec on which the sound gets played on, must be provided to the constructor.
Make sure that the codec is not a temporary object, since the AudioPlayer class only holds a reference to it.
``` C++
// Application.cpp
#include "BSP_VoiceMailBox.hpp"
#include <string>

// using a namespace globaly is not recommended for production
// but it simplyfies the example here
using namespace VoiceMailBox; 

AudioPlayer* player = nullptr;
const std::string fileName = "record.mp3";

void setup()
{
    VoiceMailBox::setup();

    // Assign the codec from the Voice Mail Box platform to the audio player
    player = new AudioPlayer(getCodec());
}

void loop()
{
    VoiceMailBox::update();

    if(/*any start condition*/)
        player->start(fileName);

    if(/*any pause condition*/)
        player->pause();

    if(/*any resume condition*/)
        player->resume();
   
    if(/*any stop condition*/)
        player->stop(); 
}
```

### Using the debug Pin
``` C++
// Application.cpp
#include "BSP_VoiceMailBox.hpp"

// using a namespace globaly is not recommended for production
// but it simplyfies the example here
using namespace VoiceMailBox; 

AudioPlayer* player = nullptr;
const std::string fileName = "record.mp3";

void setup()
{
    VoiceMailBox::setup();

    DigitalPin &dbgPin = getLed(LED::LED0);

    // Provide the constructor with a reference to a digital pin
    // Make sure that this given pin is not a temporary object, since the Player only holds a reference to it.
    player = new AudioPlayer(getCodec(), dbgPin);
}

void loop()
{
    VoiceMailBox::update();

    // ...
}
```

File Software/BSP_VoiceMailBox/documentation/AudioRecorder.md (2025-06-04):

# AudioRecorder
This class manages the dataflow from the microphone to the SD-card.
You can find a ready to run project [here](../../Demos/F469/F469_MultiExample/README.md).

---
## Content
- [Features](#features)
- [Setup](#setup)
- [Usage](#usage)
    - [Basic usage](#basic-usage)
    - [Using the debug Pin](#using-the-debug-pin)

## Features
- Start recording
- Stop recording
- Pause/Resume recording
- Display optional debug information on a digital pin for performance measurement and timing constraint check.

## Setup
- Make sure the C++ application is setup in order to use this class
  You can find the instructions on how to do so [here](CppFromC.md).

## Usage
### Basic usage
A AudioRecorder object can be instantiated in the Application.cpp.
The codec on which the sound gets recorded from, must be provided to the constructor.
Make sure that the codec is not a temporary object, since the AudioRecorder class only holds a reference to it.
``` C++
// Application.cpp
#include "BSP_VoiceMailBox.hpp"
#include <string>

// using a namespace globaly is not recommended for production
// but it simplyfies the example here
using namespace VoiceMailBox; 

AudioRecorder* recorder = nullptr;
const std::string fileName = "record.mp3";

void setup()
{
    VoiceMailBox::setup();

    // Assign the codec from the Voice Mail Box platform to the audio recorder
    recorder = new AudioRecorder(getCodec());
}

void loop()
{
    VoiceMailBox::update();

    if(/*any start condition*/)
        recorder->start(fileName);
    
    if(/*any pause condition*/)
        recorder->pause();

    if(/*any resume condition*/)
        recorder->resume();

    if(/*any stop condition*/)
        recorder->stop(); 
}
```

### Using the debug Pin
``` C++
// Application.cpp
#include "BSP_VoiceMailBox.hpp"
#include <string>

// using a namespace globaly is not recommended for production
// but it simplyfies the example here
using namespace VoiceMailBox; 

AudioRecorder* recorder = nullptr;
const std::string fileName = "record.mp3";

void setup()
{
    VoiceMailBox::setup();

    DigitalPin &dbgPin = getLed(LED::LED0);

    // Provide the constructor with a reference to a digital pin
    // Make sure that this given pin is not a temporary object, since the Player only holds a reference to it.
    recorder = new AudioRecorder(getCodec(), dbgPin);
}

void loop()
{
    VoiceMailBox::update();

    // ...
}
```

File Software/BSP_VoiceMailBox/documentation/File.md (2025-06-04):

# File
This class is a simplfied interface for reading and writing files to the SD-Card.
All Basic functions used in the project are implemented here.
The class uses the FATFS filesystem.
You can find a ready to run project [here](../../Demos/F469/F469_MultiExample/README.md).

---
## Content
- [Features](#features)
- [Setup](#setup)
- [Usage](#usage)
    - [Writing to a file](#writing-to-a-file)
    - [Appending to a file](#appending-to-a-file)
    - [Reading from a file](#reading-from-a-file)

---
## Features
- Writing/Appending/Reading files.
- Deleting files at a given path.
- Rename files.
- Check if a given file path exists.
- reading a list of files in a given directory.

---
## Setup    
- Inside CubeMX, enable the FATFS in the **Middleware and Software Packages** section.
- Start the code generation and open the code editor.
- Make sure the C++ application is setup in order to use this class
You can find the instructions on how to do so [here](CppFromC.md).

---
## Usage
#### Writing to a file
``` C++ 
#include "BSP_VoiceMailBox.hpp" 
// ...
void simpleWrite()
{
    using namespace VoiceMailBox;

    File file;
    if (file.open("example.txt", File::AccessMode::write))
    {
        file.write("Hello, World!\n");
        file.close();
        println("File written successfully.");
    }
    else
    {
        println("Failed to open file for writing.");
    }
}
```
---

#### Appending to a file
``` C++ 
#include "BSP_VoiceMailBox.hpp" 
// ...
void simpleAppend()
{
    using namespace VoiceMailBox;

    File file;
    if (file.open("example.txt", File::AccessMode::append))
    {
        file.write("Appending a new line.\r\n");
        file.close();
        println("File appended successfully.");
    }
    else
    {
        println("Failed to open file for appending.");
    }
}
```
---

#### Reading from a file
``` C++ 
#include "BSP_VoiceMailBox.hpp" 
// ...
void simpleRead()
{
    using namespace VoiceMailBox;

    File file;
    if (file.open("example.txt", File::AccessMode::read))
    {
        char buffer[64] = { 0 }; // Buffer to hold the read data
        while (file.read(buffer, sizeof(buffer)))
        {
            println("Read data: \r\n\"\r\n%s\"", buffer);
        }
        file.close();
        println("File read successfully.");
    }
    else
    {
        println("Failed to open file for reading.");
    }
}
```
---

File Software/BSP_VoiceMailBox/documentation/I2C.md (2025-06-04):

# I2C
This class is a simplfied interface for the i2c peripheral.
All Basic functions used in the project are implemented here.
The implementaion is designed to be blocking.
You can find a ready to run project [here](../../Demos/F469/F469_MultiExample/README.md).

---
## Content
- [Features](#features)
- [Setup](#setup)
- [Usage](#usage)
    - [Modify main.h and main.c](#modify-mainh-and-mainc)
    - [Inside the C++ Application](#inside-the-c-application)

---
## Features
- Writing one byte to a specific 8bit register on a I2C device.
- Reading one byte from a specifc 8bit register on a I2C device.

---
## Setup    
- Inside CubeMX, configure your i2c interface.
- Start the code generation and open the code editor.
- Make sure the C++ application is setup in order to use this class
You can find the instructions on how to do so [here](CppFromC.md).

---
## Usage
CubeMX generates a **I2C_HandleTypeDef** instance in the **main.c**
The **I2C** class needs access to that handle. Since the C++ code can't be used directly in the **main.c**, another way of getting to the handle is needed.

#### Modify main.h and main.c
In the **main.h** create a get function that returns a pointer to the handle we want.
``` C
// main.h

// Function declaration
I2C_HandleTypeDef* getI2C_Handle();
```

``` C
// main.c

/* Private variables generated by CubeMX */
I2C_HandleTypeDef hi2c1;

/* USER CODE BEGIN PV */
// Function implementation
I2C_HandleTypeDef* getI2C_Handle()
{
    // Return the pointer to the handle
    return &hi2c1;
}
/* USER CODE END PV */
```

#### Inside the C++ Application
``` C++ 
// Application.cpp
#include "BSP_VoiceMailBox.hpp" // includes "peripherals/i2c.hpp"
#include "main.h" // Is needed to access the handle get function

// using a namespace globaly is not recommended for production
// but it simplyfies the example here
using namespace VoiceMailBox; 

// Create a I2C object and providing the handle from the main.c
VoiceMailBox::I2C* i2c = nullptr;
void setup()
{
	i2c = new VoiceMailBox::I2C(getI2C_Handle());

	VoiceMailBox::setup();
	uint8_t deviceAddress = 0x18;   // Use the address of the Codec
	uint8_t registerAddress = 0x00; // Use the "Page Select" register to write to the first page
	// inside the target.
	uint8_t dataToWrite = 0x01;

	// Writes the value 0x01 to the register 0x00 on the device 0x05.
	i2c->writeRegister(deviceAddress, registerAddress, dataToWrite);

	// Reads the register 0x00 from the device 0x18 and
	// stores the value in the <readData> variable
	uint8_t readData = 0;
	i2c->readRegister(deviceAddress, registerAddress, readData);
	VoiceMailBox::println("Read data: 0x%02X", readData);
}
```

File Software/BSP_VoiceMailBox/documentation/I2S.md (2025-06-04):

# I2S
This class is a simplfied interface to access the i2s peripheral.
All Basic functions used in the project are implemented here.
The implementation does use a DMA in Full-Duplex mode.
You can find a ready to run project [here](../../Demos/F469/F469_MultiExample/README.md).

---
## Content
- [Features](#features)
- [Setup](#setup)
- [Usage](#usage)
    - [Modify main.h and main.c](#modify-mainh-and-mainc)
    - [Inside the C++ Application](#inside-the-c-application)
- [I2S behind the scenes](#i2s-behind-the-scenes)
    - [Data flow](#data-flow)
    - [Ping-Pong Buffering](#ping-pong-buffering)
    - [Audio Samples](#audio-samples)

---
## Features
- Writing audio samples using a DMA
- Receiving audio samples using a DMA

---
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

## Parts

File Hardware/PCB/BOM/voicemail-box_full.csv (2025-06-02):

Reference | Value | Footprint | Datasheet | Qty | Manufacturer | Part Number | DNP | Var
C301 | 100n | Capacitor_SMD:C_0805_2012Metric_Pad1.18x1.45mm_HandSolder | ~ | 1 | Kemet | C0805C104K5RACTU |  | Assembly Full(+!) Partial(-!)
C401 | 100n | Capacitor_SMD:C_0805_2012Metric_Pad1.18x1.45mm_HandSolder | ~ | 1 | Kemet | C0805C104K5RACTU
C501,C502,C531,C533 | 10p | Capacitor_SMD:C_0603_1608Metric_Pad1.08x0.95mm_HandSolder | ~ | 4 | Kemet | C0603C100K5GACTU |  | Assembly Full(+!) Partial(-!)
C503,C504,C506,C508,C510,C512,C516,C518 | 10n | Capacitor_SMD:C_0603_1608Metric_Pad1.08x0.95mm_HandSolder | ~ | 8 | Kemet | C0603C103K5RACTU |  | Assembly Full(+!) Partial(-!)
C505,C507,C509,C513,C515,C517,C519 | 2u2 | Capacitor_SMD:C_0603_1608Metric_Pad1.08x0.95mm_HandSolder | ~ | 7 | Kemet | C0603C225K4PACTU |  | Assembly Full(+!) Partial(-!)
C511 | 1u | Capacitor_SMD:C_0603_1608Metric_Pad1.08x0.95mm_HandSolder | ~ | 1 | Kemet | C0603C105K4RACTU |  | Assembly Full(+!) Partial(-!)
C514 | 22n | Capacitor_SMD:C_0603_1608Metric_Pad1.08x0.95mm_HandSolder | ~ | 1 | Kemet | C0603C223K1RACTU |  | Assembly Full(+!) Partial(-!)
C520,C521 | 100p | Capacitor_SMD:C_0603_1608Metric_Pad1.08x0.95mm_HandSolder | ~ | 2 | Kemet | C0603C101J5GACTU |  | Assembly Full(+!) Partial(-!)
C522,C523 | 680p | Capacitor_SMD:C_0603_1608Metric_Pad1.08x0.95mm_HandSolder | ~ | 2 | Kemet | C0603C681K5RACTU |  | Assembly Full(+!) Partial(-!)
C524,C525,C526 | 47p | Capacitor_SMD:C_0603_1608Metric_Pad1.08x0.95mm_HandSolder | ~ | 3 | Kemet | C0603C470K5GACTU |  | Assembly Full(+!) Partial(-!)
C527,C528 | 56p | Capacitor_SMD:C_0603_1608Metric_Pad1.08x0.95mm_HandSolder | ~ | 2 | Kemet | C0603C560M3HACTU |  | Assembly Full(+!) Partial(-!)
C532,C534 | 180p | Capacitor_SMD:C_0603_1608Metric_Pad1.08x0.95mm_HandSolder | ~ | 2 | Kemet | C0603C181J5GACTU |  | Assembly Full(+!) Partial(-!)
C601,C603,C605,C608,C612,C613,C621,C805,C807,C809,C811,C812,C813,C814,C815 | 100n | Capacitor_SMD:C_0603_1608Metric_Pad1.08x0.95mm_HandSolder | ~ | 15 | Kemet | C0603C104K5RACTUCT
C602,C604,C607,C609 | 10u | Capacitor_SMD:C_0603_1608Metric_Pad1.08x0.95mm_HandSolder | ~ | 4 | Kemet | C0603C106M9PAC7411
C606,C622 | 1u | Capacitor_SMD:C_0603_1608Metric_Pad1.08x0.95mm_HandSolder | ~ | 2 | Kemet | C0603C105K4RACTU
C610,C611 | 100u | Capacitor_SMD:C_0805_2012Metric_Pad1.18x1.45mm_HandSolder | ~ | 2 | Samsung Electro-Mechanics | CL21A107MQYNNWE
C614,C615,C620 | np | Capacitor_SMD:C_0603_1608Metric_Pad1.08x0.95mm_HandSolder | ~ | 3 | - | - | DNP
C616,C617,C618,C619 | 47n | Capacitor_SMD:C_0603_1608Metric_Pad1.08x0.95mm_HandSolder | ~ | 4 | Kemet | C0603C473K5RACTUCT
C806,C808 | 10u | Capacitor_SMD:C_0805_2012Metric_Pad1.18x1.45mm_HandSolder | ~ | 2 | Kemet | C0603C106M9PAC7411
C810 | 1n | Capacitor_SMD:C_0603_1608Metric_Pad1.08x0.95mm_HandSolder | ~ | 1 | Kemet | C0603C102K5RACTUCT
CN201 | Conn_02x08_Odd_Even | Connector_PinSocket_2.54mm:PinSocket_2x08_P2.54mm_Vertical | ~ | 1 | Würth Elektronik | 61301621821
CN202 | ~ | Connector_PinHeader_2.54mm:PinHeader_2x08_P2.54mm_Vertical |  | 1 | Würth Elektronik | 61301621121
CN203 | ~ | Connector_PinHeader_2.54mm:PinHeader_2x15_P2.54mm_Vertical |  | 1 | Samtec Inc. | TSW-115-24-L-D
CN204 | ~ | Connector_PinHeader_2.54mm:PinHeader_2x10_P2.54mm_Vertical |  | 1 | Adam Tech | PH2-20-UA
CN205 | ~ | Connector_PinHeader_2.54mm:PinHeader_2x17_P2.54mm_Vertical |  | 1 | Amphenol ICC (FCI) | 67997-234HLF
D502 | BAV70W | Package_TO_SOT_SMD:SOT-23-3 | ~ | 1 | Diodes Incorporated | BAV70W-7-F |  | Assembly Full(+!) Partial(-!)
J102,J802,J803 | Conn_02x03_Odd_Even | Connector_PinHeader_2.54mm:PinHeader_2x03_P2.54mm_Vertical | ~ | 3 | Würth Elektronik | 61300621121
J103 | Conn_02x08_Odd_Even | Connector_PinHeader_2.54mm:PinHeader_2x08_P2.54mm_Vertical | ~ | 1 | Würth Elektronik | 61301621121
J104,J106 | Conn_02x10_Odd_Even | Connector_PinHeader_2.54mm:PinHeader_2x10_P2.54mm_Vertical | ~ | 2 | Molex | 0901310770
J105,J801 | Conn_01x08 | Connector_PinHeader_2.54mm:PinHeader_1x08_P2.54mm_Vertical | ~ | 2 | Würth Elektronik | 61300811121
J303 | Conn_01x06 | Connector_PinHeader_2.54mm:PinHeader_1x06_P2.54mm_Vertical | ~ | 1 | Würth Elektronik | 61300611121 |  | Assembly Full(+!) Partial(-!)
J401 | Micro_SD_Card_Det1 | Connector_Card:microSD_HC_Hirose_DM3AT-SF-PEJM5 | https://datasheet.lcsc.com/lcsc/2110151630_XKB-Connectivity-XKTF-015-N_C381082.pdf | 1 | Hirose Electric Co Ltd | DM3AT-SF-PEJM5
J501 | Conn_01x02 | Connector_PinHeader_1.27mm:PinHeader_1x02_P1.27mm_Vertical | ~ | 1 | Harwin Inc. | M50-3532042 |  | Assembly Full(+!) Partial(-!)
J601 | Conn_02x02_Odd_Even | Connector_PinHeader_2.54mm:PinHeader_2x02_P2.54mm_Vertical | ~ | 1 | Würth Elektronik | 61300421121
J602,J605 | AudioJack3_SwitchTR | additional parts:Jack_3.5mm_CUI_SJ2-3593D-SMT_Horizontal | ~ | 2 | Same Sky (Formerly CUI Devices) | SJ2-3593D-SMT-TR
J603 | Phoenix 1844236 | Connector_Phoenix_MC:PhoenixContact_MC_1,5_4-G-3.5_1x04_P3.50mm_Horizontal | ~ | 1 | Amphenol Anytek | OQ041G01B000G, TJ0411030000G
J604 | Conn_01x03 | Connector_PinHeader_2.54mm:PinHeader_1x03_P2.54mm_Vertical | ~ | 1 | Würth Elektronik | 61300311121
J701 | USB_C_Receptacle_PowerOnly_6P | additional parts:USB_C_Receptacle_HRO_TYPE-C-31-M-17 | https://www.usb.org/sites/default/files/documents/usb_type-c.zip | 1 | Amphenol ICC (FCI) | 10164359-00011LF
L501,L502 | 270n | Inductor_SMD:L_0603_1608Metric_Pad1.05x0.95mm_HandSolder | ~ | 2 | Murata | LQW18ANR27J00D |  | Assembly Full(+!) Partial(-!)
L701 | FerriteBead_0603_1.5A | Inductor_SMD:L_0603_1608Metric_Pad1.05x0.95mm_HandSolder |  | 1 | Laird | MI0603K300R-10
LED801 | Red_100mcd_0603 | PCM_4ms_LED:LED_0603_1608Metric |  | 1 | Lite-On Inc. | LTST-C190KFKT
LED804 | Green_350mcd_0603 | PCM_4ms_LED:LED_0603_1608Metric |  | 1 | Lite-On Inc. | LTST-C190GKT
MK601 | CMA-4544PF-W | additional parts:Mic, dia 10mm pitch 2.54mm | ~ | 1 | Same Sky (Formerly CUI Devices) | CMA-4544PF-W
Q501 | NX3008NBK | Package_TO_SOT_SMD:SOT-23-3 | https://ngspice.sourceforge.io/docs/ngspice-html-manual/manual.xhtml#cha_MOSFETs | 1 | Nexperia USA Inc. | NX3008NBKW,115 |  | Assembly Full(+!) Partial(-!)
R101,R102,R103,R805,R806,R807,R808,R809,R810,R811,R812,R813,R814 | 4k7 | Resistor_SMD:R_0603_1608Metric_Pad0.98x0.95mm_HandSolder | ~ | 13 | Yageo | RC0603FR-074K7L
R106,R107 | 220R | Resistor_SMD:R_0603_1608Metric_Pad0.98x0.95mm_HandSolder | ~ | 2 | Yageo | RC0603FR-07220RL
R301,R501 | 10k | Resistor_SMD:R_0805_2012Metric_Pad1.20x1.40mm_HandSolder | ~ | 2 | Yageo | RC0603FR-0710KL |  | Assembly Full(+!) Partial(-!)
R302 | 20k | Resistor_SMD:R_0805_2012Metric_Pad1.20x1.40mm_HandSolder | ~ | 1 | Yageo | RC0603FR-0720KL |  | Assembly Full(+!) Partial(-!)
R303 | 1k | Resistor_SMD:R_0805_2012Metric_Pad1.20x1.40mm_HandSolder | ~ | 1 | Yageo | RC0603FR-071KL |  | Assembly Full(+!) Partial(-!)
R502 | 47k | Resistor_SMD:R_0805_2012Metric_Pad1.20x1.40mm_HandSolder | ~ | 1 | Yageo | RC0603FR-0747KL |  | Assembly Full(+!) Partial(-!)
R503,R504 | 2k4 | Resistor_SMD:R_0805_2012Metric_Pad1.20x1.40mm_HandSolder | ~ | 2 | Yageo | RC0603FR-072K4L |  | Assembly Full(+!) Partial(-!)
R505 | 100R | Resistor_SMD:R_0805_2012Metric_Pad1.20x1.40mm_HandSolder | ~ | 1 | Yageo | RC0805FR-07100RL |  | Assembly Full(+!) Partial(-!)
R506,R507 | 10k | Resistor_SMD:R_0805_2012Metric_Pad1.20x1.40mm_HandSolder | ~ | 2 | Yageo | RC0603FR-0710KL
R601,R602 | 2k2 | Resistor_SMD:R_0603_1608Metric_Pad0.98x0.95mm_HandSolder | ~ | 2 | Yageo | RC0603FR-072K2L
R603 | 100k | Resistor_SMD:R_0603_1608Metric_Pad0.98x0.95mm_HandSolder | ~ | 1 | Yageo | RC0603FR-07100KL
R604,R605,R606,R607 | 100R | Resistor_SMD:R_0603_1608Metric_Pad0.98x0.95mm_HandSolder | ~ | 4 | Yageo | RC0603FR-07100RL
R608,R609 | np | Resistor_SMD:R_0603_1608Metric_Pad0.98x0.95mm_HandSolder | ~ | 2 | - | - | DNP
R610,R611 | 0R | Resistor_SMD:R_0603_1608Metric_Pad0.98x0.95mm_HandSolder | ~ | 2 | Bourns Inc. | CR0603AJ/-000EAS
R612 | 2k7 | Resistor_SMD:R_0603_1608Metric_Pad0.98x0.95mm_HandSolder | ~ | 1 | Yageo | RC0603FR-072K7L
R701,R702 | 5k1 | Resistor_SMD:R_0603_1608Metric_Pad0.98x0.95mm_HandSolder | ~ | 2 | Yageo | RC0603FR-075K1L
R801,R802 | 1k2 | Resistor_SMD:R_0603_1608Metric_Pad0.98x0.95mm_HandSolder | ~ | 2 | Yageo | RC0603FR-071K2L
RN401 | 10k | Resistor_SMD:R_Array_Convex_4x0603 | ~ | 1 | Panasonic Electronic Components | EXB-38V103JV
RN402 | 220R | Resistor_SMD:R_Array_Convex_4x0603 | ~ | 1 | Panasonic Electronic Components | EXB-38V221JV
RV801,RV802 | potentiometer_RK163 | Potentiometer_THT:Potentiometer_Alps_RK163_Single_Horizontal |  | 2 | Alps Alpine | RK1631110U2A
SW601 | CTS 218-4LPSTJ | additional parts:SSOP-8_3.9x5.05mm_P1.27mm | ~ | 1 | CTS Electrocomponents | 218-4LPSTJ
SW801,SW802,SW803,SW804 | Push_Button | Button_Switch_THT:SW_PUSH_6mm |  | 4 | Same Sky (Formerly CUI Devices) | TS02-66-70-BK-100-SCR-D
U301 | ESP32-WROOM-32 | RF_Module:ESP32-WROOM-32 | https://www.espressif.com/sites/default/files/documentation/esp32-wroom-32_datasheet_en.pdf | 1 | Espressif Systems | ESP32-WROOM-32E-H4 |  | Assembly Full(+!) Partial(-!)
U501 | ST25R3916B | additional parts:UFQFPN-32-1EP_5x5mm_P0.5mm_EP3.5x3.5mm |  | 1 | STMicroelectronics | ST25R3916B-AQET |  | Assembly Full(+!) Partial(-!)
U502,U503,U505 | LXRW0YV600-054 | additional parts:LXRW0_MUR-M | LXRW0YV600-054 | 3 | Murata Electronics | LXRW0YV600-054 |  | Assembly Full(+!) Partial(-!)
U601 | TLV320AIC3104 | additional parts:VQFN-32-1EP_5x5mm_P0.5mm_EP3.1x3.1mm |  | 1 | Texas Instruments | TLV320AIC3104IRHBR
U602 | MAX98306xDT | additional parts:TDFN-14-1EP_3x3mm_P0.4mm_EP1.78x2.35mm | https://datasheets.maximintegrated.com/en/ds/MAX98306.pdf | 1 | Analog Devices Inc./Maxim Integrated | MAX98306ETD+T
U701 | R-78B3.3-2.0 | Converter_DCDC:Converter_DCDC_RECOM_R-78B-2.0_THT | https://www.recom-power.com/pdf/Innoline/R-78Bxx-2.0.pdf | 1 | Recom Power | R-78K3.3-2.0
U702 | TC2015-1.8VxCTTR | Package_TO_SOT_SMD:SOT-23-5 | http://ww1.microchip.com/downloads/en/DeviceDoc/21662F.pdf | 1 | Microchip Technology | MIC5259-1.8YD5-TR
U801 | 74LS07 | Package_SO:SOIC-14_3.9x8.7mm_P1.27mm | www.ti.com/lit/ds/symlink/sn74ls07.pdf | 1 | Texas Instruments | SN74LS07DR
Y501 | 27.12Mhz | Crystal:Crystal_SMD_SeikoEpson_FA128-4Pin_2.0x1.6mm | ~ | 1 | EPSON | FA-118T 27.1200MD50Z-K3 |  | Assembly Full(+!) Partial(-!)

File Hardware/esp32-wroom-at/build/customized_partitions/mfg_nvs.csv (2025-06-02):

key | type | encoding | value
server_cert | namespace
server_cert | file | binary | /home/runner/work/esp-at/esp-at/components/customized_partitions/raw_data/server_cert/server_cert.crt
server_key | namespace
server_key | file | binary | /home/runner/work/esp-at/esp-at/components/customized_partitions/raw_data/server_key/server.key
server_ca | namespace
server_ca | file | binary | /home/runner/work/esp-at/esp-at/components/customized_partitions/raw_data/server_ca/server_ca.crt
client_cert | namespace
client_cert.0 | file | binary | /home/runner/work/esp-at/esp-at/components/customized_partitions/raw_data/client_cert/client_cert_00.crt
client_cert.1 | file | binary | /home/runner/work/esp-at/esp-at/components/customized_partitions/raw_data/client_cert/client_cert_01.crt
client_key | namespace
client_key.0 | file | binary | /home/runner/work/esp-at/esp-at/components/customized_partitions/raw_data/client_key/client_key_00.key
client_key.1 | file | binary | /home/runner/work/esp-at/esp-at/components/customized_partitions/raw_data/client_key/client_key_01.key
client_ca | namespace
client_ca.0 | file | binary | /home/runner/work/esp-at/esp-at/components/customized_partitions/raw_data/client_ca/client_ca_00.crt
client_ca.1 | file | binary | /home/runner/work/esp-at/esp-at/components/customized_partitions/raw_data/client_ca/client_ca_01.crt
mqtt_cert | namespace
mqtt_cert | file | binary | /home/runner/work/esp-at/esp-at/components/customized_partitions/raw_data/mqtt_cert/mqtt_client.crt
mqtt_key | namespace
mqtt_key | file | binary | /home/runner/work/esp-at/esp-at/components/customized_partitions/raw_data/mqtt_key/mqtt_client.key
mqtt_ca | namespace
mqtt_ca | file | binary | /home/runner/work/esp-at/esp-at/components/customized_partitions/raw_data/mqtt_ca/mqtt_ca.crt
factory_param | namespace
version | data | i8 | 4
module_name | data | string | WROOM-32
max_tx_power | data | i8 | 78
country_code | data | string | CN
start_channel | data | u8 | 1
channel_num | data | u8 | 13
uart_port | data | i8 | 1
uart_baudrate | data | i32 | 115200
uart_tx_pin | data | i32 | 17
uart_rx_pin | data | i32 | 16
uart_cts_pin | data | i32 | 15
uart_rts_pin | data | i32 | 14
sys_store | data | u8 | 1
ble_data | namespace
cfg0 | data | string | 0,16,0x2800,0x01,2,2,A002
cfg1 | data | string | 1,16,0x2803,0x01,1,1,02
cfg2 | data | string | 2,16,0xC300,0x01,1,1,30
cfg3 | data | string | 3,16,0x2901,0x11,1,1,30
cfg4 | data | string | 4,16,0x2803,0x01,1,1,02
cfg5 | data | string | 5,16,0xC301,0x01,512,512,
cfg6 | data | string | 6,16,0x2901,0x11,512,512,
cfg7 | data | string | 7,16,0x2803,0x01,1,1,08
cfg8 | data | string | 8,16,0xC302,0x10,1,1,30
cfg9 | data | string | 9,16,0x2901,0x01,1,1,01
cfg10 | data | string | 10,16,0x2803,0x01,1,1,04
cfg11 | data | string | 11,16,0xC303,0x10,1,1,30
cfg12 | data | string | 12,16,0x2901,0x10,1,1,30
cfg13 | data | string | 13,16,0x2803,0x01,1,1,08
cfg14 | data | string | 14,16,0xC304,0x10,512,512,
cfg15 | data | string | 15,16,0x2803,0x01,1,1,10
cfg16 | data | string | 16,16,0xC305,0x01,1,1,00
cfg17 | data | string | 17,16,0x2902,0x11,2,2,0000
cfg18 | data | string | 18,16,0x2803,0x01,1,1,20
cfg19 | data | string | 19,16,0xC306,0x01,1,1,00
cfg20 | data | string | 20,16,0x2902,0x11,2,2,0000
cfg21 | data | string | 21,16,0x2803,0x01,1,1,02
cfg22 | data | string | 22,16,0xC307,0x01,1,1,30
cfg23 | data | string | 23,16,0x2901,0x11,256,1,30
cfg24 | data | string | 24,16,0x2800,0x01,2,2,A003
cfg25 | data | string | 25,16,0x2803,0x01,1,1,02
cfg26 | data | string | 26,16,0xC400,0x01,1,1,30
cfg27 | data | string | 27,16,0x2901,0x11,1,1,30
cfg28 | data | string | 28,16,0x2803,0x01,1,1,02
cfg29 | data | string | 29,16,0xC401,0x01,1,1,30
cfg30 | data | string | 30,16,0x2901,0x11,256,1,30

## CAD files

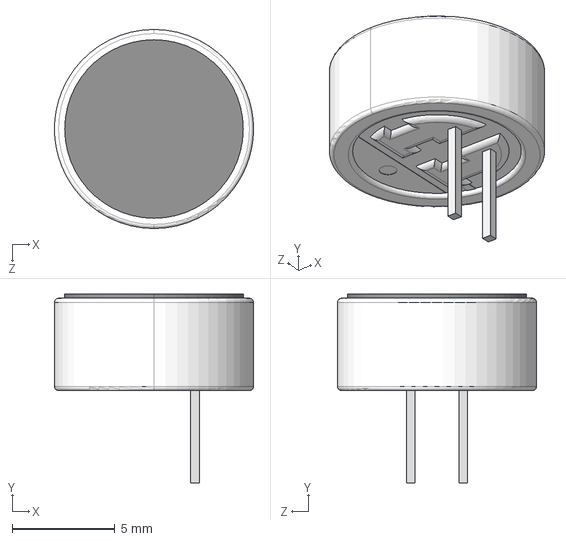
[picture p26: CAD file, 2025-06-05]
Hardware/PCB/additional Parts/Same_Sky_CMA-4544PF-W.step
9.70 x 9.20 x 9.70 mm

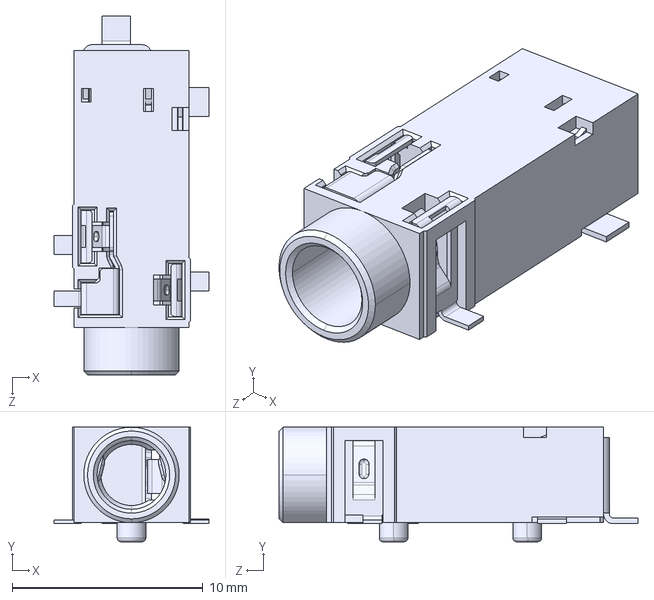
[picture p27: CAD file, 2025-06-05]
Hardware/PCB/additional Parts/Same_Sky_SJ2-3593D-SMT-TR.step
8.10 x 6.00 x 18.8 mm

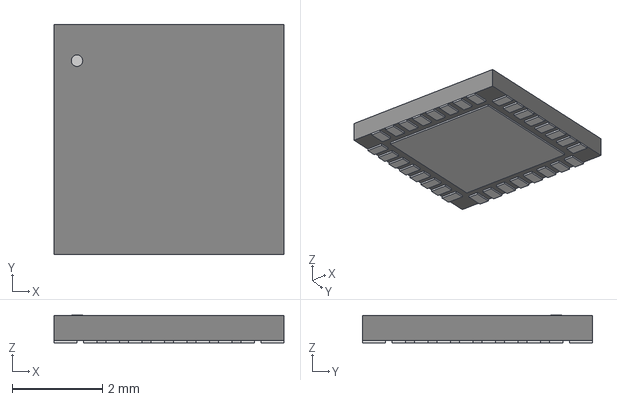
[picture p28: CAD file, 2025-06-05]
Hardware/PCB/additional Parts/ST25R3916B_AQET.step
5.11 x 5.11 x 0.612 mm

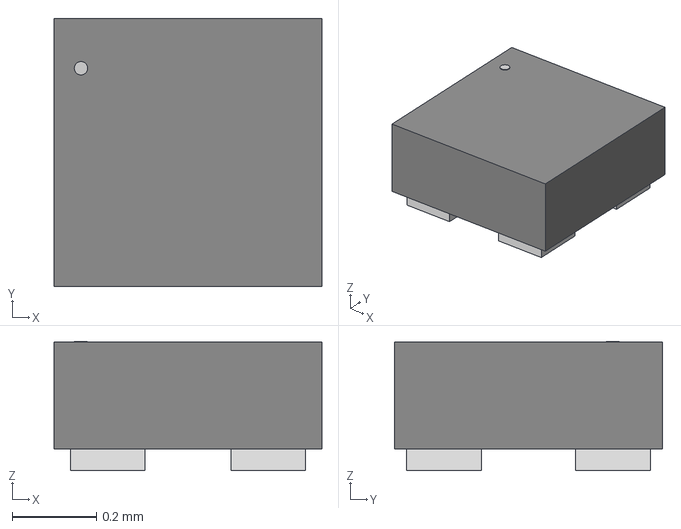
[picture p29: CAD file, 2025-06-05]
Hardware/PCB/additional Parts/LXRW0_MUR.step
0.636 x 0.636 x 0.307 mm

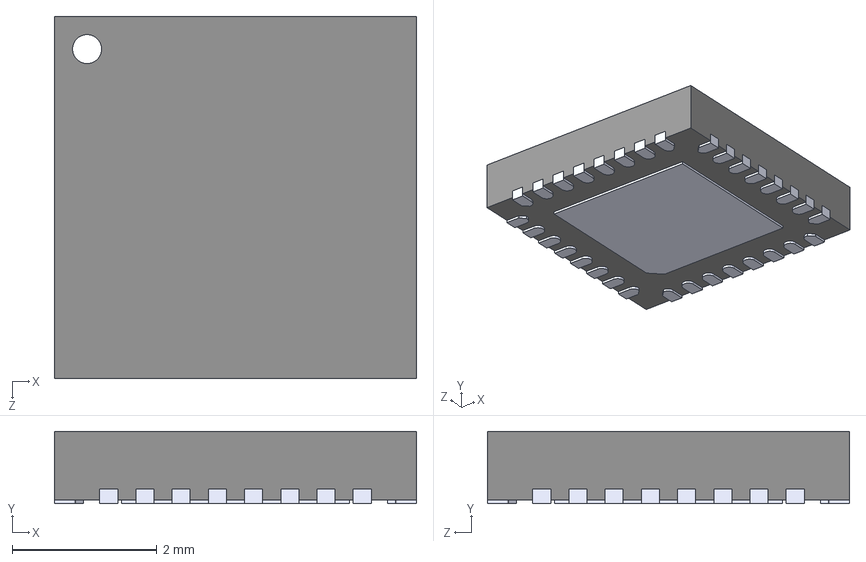
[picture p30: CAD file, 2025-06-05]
Hardware/PCB/additional Parts/TLV320AIC3104IRHBR.step
5.00 x 1.00 x 5.00 mm

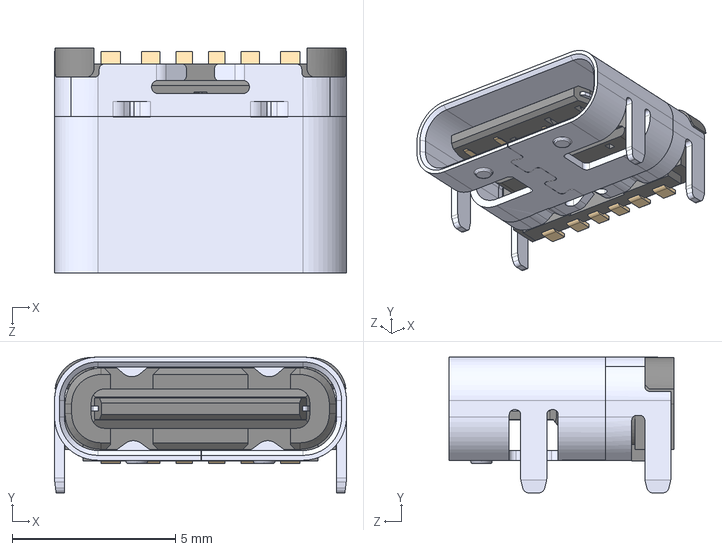
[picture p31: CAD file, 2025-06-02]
Hardware/PCB/additional Parts/USB-C.STEP
8.94 x 4.16 x 6.90 mm

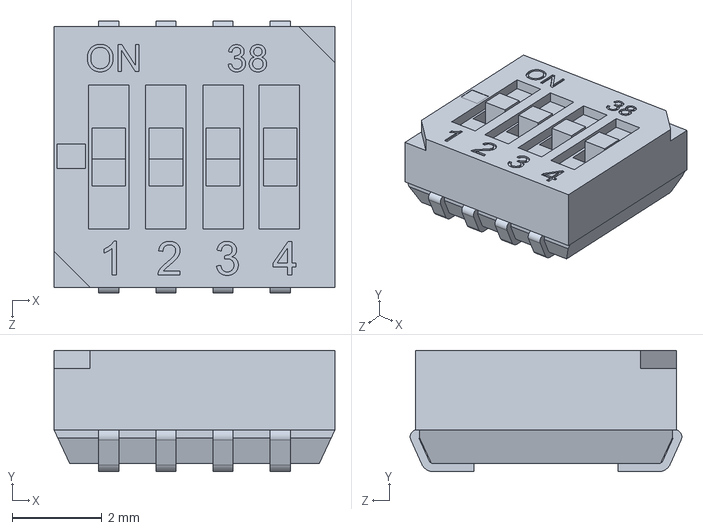
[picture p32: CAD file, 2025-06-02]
Hardware/PCB/additional Parts/218-4LPJ.STEP
6.25 x 2.70 x 6.04 mm

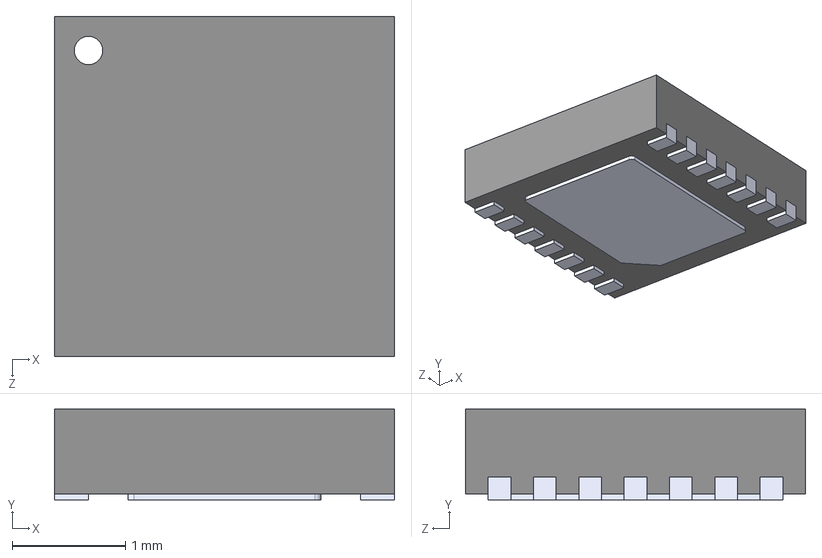
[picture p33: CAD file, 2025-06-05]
Hardware/PCB/additional Parts/MAX98306ETD_T.step
3.00 x 0.8 x 3.00 mm

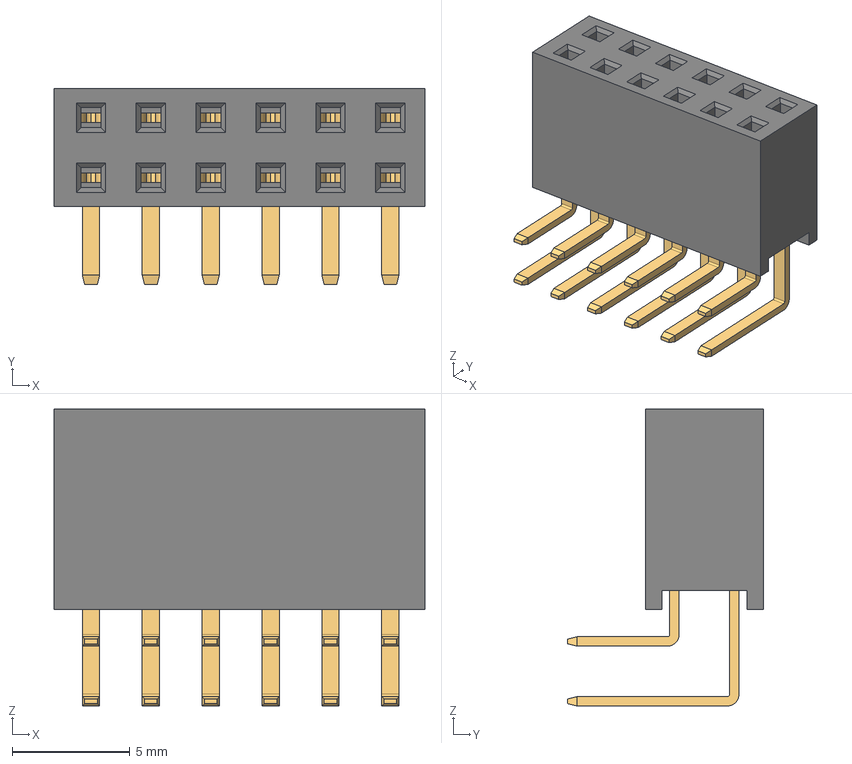
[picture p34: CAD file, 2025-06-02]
Hardware/PCB/additional Parts/613012243121.stp
15.7 x 8.30 x 12.6 mm
6130xx243121_PIN x 6
6130xx243121_PIN_G x 6

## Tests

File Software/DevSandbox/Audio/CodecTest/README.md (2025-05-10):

## Setup
Multimedia->
	SAI1->
		Master with master Clock Out
		[X] I2S/PCM Protocol
		NVIC Setings->
			SAI1 global interrupt: Enabled
		Parameter Settings->
			Basic Parameters->
				Audio Mode: Master Receive
			Clock Parameters->
				Audio Frequency: 48kHz
		DMA Settings->
			SAI1_A, DMA2 Stream1, Peripheral to Memory
			Mode: Circular
			Data Width: Half Word

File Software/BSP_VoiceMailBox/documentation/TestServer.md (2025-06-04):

# Test Server
This is the Testserver for the Voicemail Box SA in the spring semester 2025.
It offers only basic proof of concept functionalities.

> [!WARNING] 
> Do not use this server for production since the most security fearutes are disabled
 
---
## Content
- [Features](#features)
- [Setup](#setup)
  - [Firewall](#firewall)
- [Usage](#usage)
  - [Where to find the uploaded files?](#where-to-find-the-uploaded-files)
  - [Uploading the same file twice](#uploading-the-same-file-twice)
  - [Uploading a file](#uploading-a-file)
    - [Using curl](#using-curl)
    - [Using the STM32](#using-the-stm32)
  - [Downloading a file](#downloading-a-file)
    - [Using curl](#using-curl-1)
    - [Using the STM32](#using-the-stm32-1)

---
## Features
* Files can be uploaded
* Files can be downloaded

---
## Setup
1) Make sure Python is installed on the server machine
2) Unpack the `Testserver_Docker.zip` in the path `Software\Demos`                         
3) Follow the setup instruction from the servers markdown file inside the unpacked folder.

### Firewall
- On the server machine, the port **8000** must be opened for TCP.
- Test the connection from another machine in the same network by uploading a file using the command:
  `curl -F 'test=@test.txt' serverip:8000/devicesbackend/upload/`

  If the sender pc can't connect to the server, try to disable the firewall on the server machine complety, but enable it again, after finish working with the server.

---
## Usage
#### Where to find the uploaded files?
The uploaded files can be found in the path `ServerRootFolder/src/media`

#### Uploading the same file twice
When a file gets uploaded with the same name twice, the old file gets overwritten.

---
#### Uploading a file
##### Using curl
1) On the sender PC, open the terminal and type the following command:
2) `curl -F 'test=@test.txt' serverip:8000/devicesbackend/upload/`
   > `serverip` is the IP address of the server machine.
  
   > Execute the command in a directory where the file `test.txt` is avilable or enter the full file path there.

##### Using the STM32
Using the [ATCommandClient](ATCommandClient.md) class, uploading a file is easy.
More informations can be found [here](ATCommandClient.md/#upload-file-to-server)

---
#### Downloading a file
##### Using curl
1) On the sender PC, open the terminal and type the following command:
2) `curl -O serverip:8000/media/test.txt`
   > `serverip` is the IP address of the server machine.

   > `media/` is the servers download path.

   > `test.txt` is the target file to download, it will be downloaded to the location the command was executed from.

##### Using the STM32
Using the [ATCommandClient](ATCommandClient.md) class, downloading a file is easy.
More informations can be found [here](ATCommandClient.md/#download-file-from-server)

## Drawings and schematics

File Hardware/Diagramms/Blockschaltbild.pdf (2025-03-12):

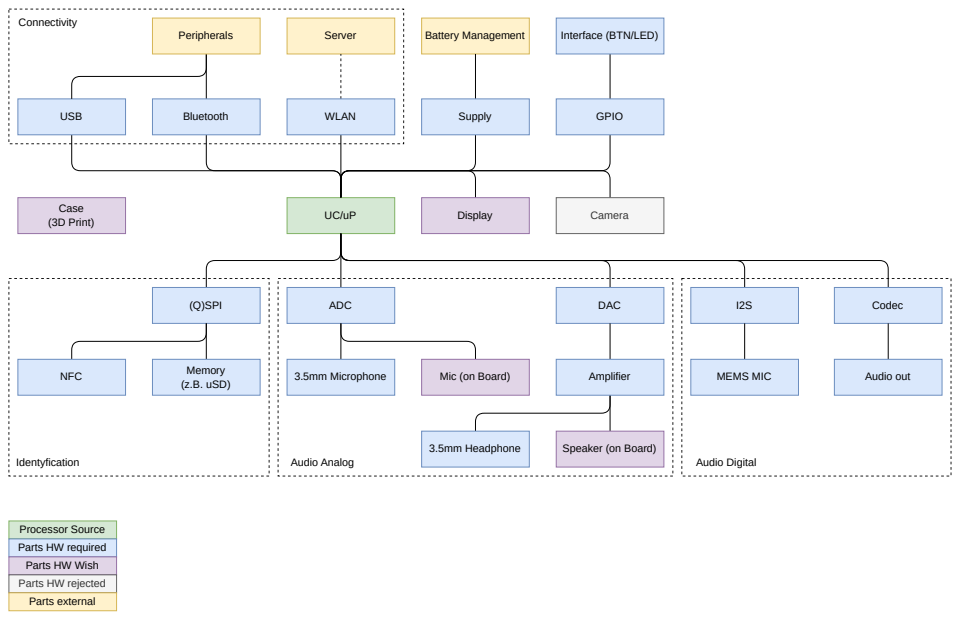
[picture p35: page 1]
USB; Bluetooth; Peripherals; Server; WLAN; Battery Management; Supply; (Q)SPI; NFC; Memory; (z.B. uSD); ADC; 3.5mm Headphone; Display; Camera; GPIO; Case (3D Print); DAC; 3.5mm Microphone; Amplifier; Connectivity; Identyfication; Audio Analog; MEMS MIC; Codec; Audio out; Audio Digital

Interface (BTN/LED)

Mic (on Board)

Speaker (on Board)

Processor Source
Parts HW required
Parts HW Wish
Parts HW rejected
Parts external

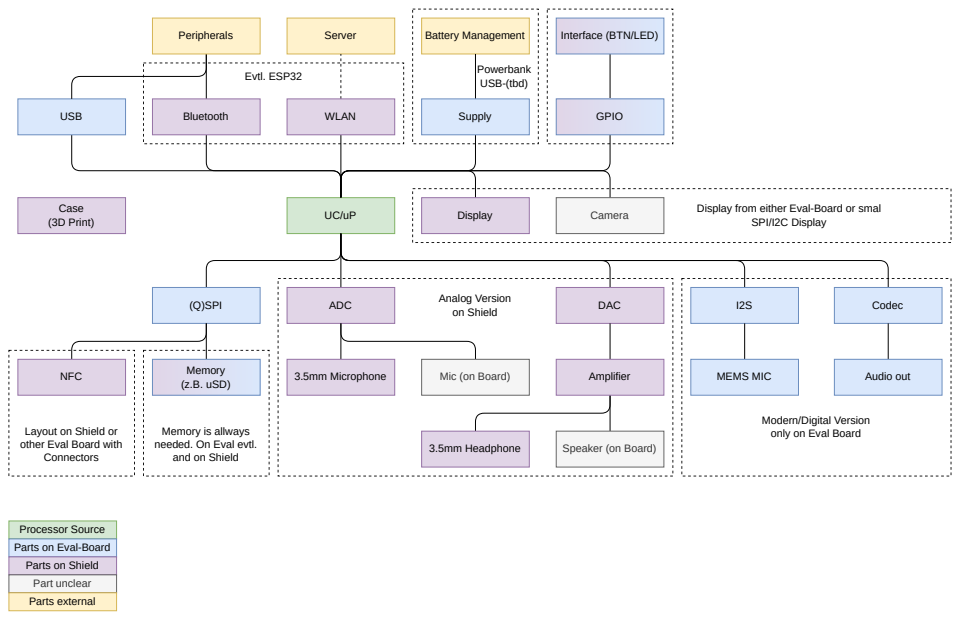
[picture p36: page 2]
USB; Bluetooth; Peripherals; Server; WLAN; Battery Management; Supply; (Q)SPI; NFC; Memory; (z.B. uSD); ADC; 3.5mm Headphone; Display; Camera; GPIO; Case (3D Print); DAC; 3.5mm Microphone; Amplifier; MEMS MIC; Codec; Audio out; Evtl. ESP32; Powerbank; USB-(tbd); SPI/I2C Display; Analog Version on Shield

Interface (BTN/LED)

Display from either Eval-Board or smal

Mic (on Board)

Modern/Digital Version
only on Eval Board

Layout on Shield or
other Eval Board with
Connectors

Memory is allways
needed. On Eval evtl.
and on Shield

Speaker (on Board)

Processor Source
Parts on Eval-Board
Parts on Shield
Part unclear
Parts external

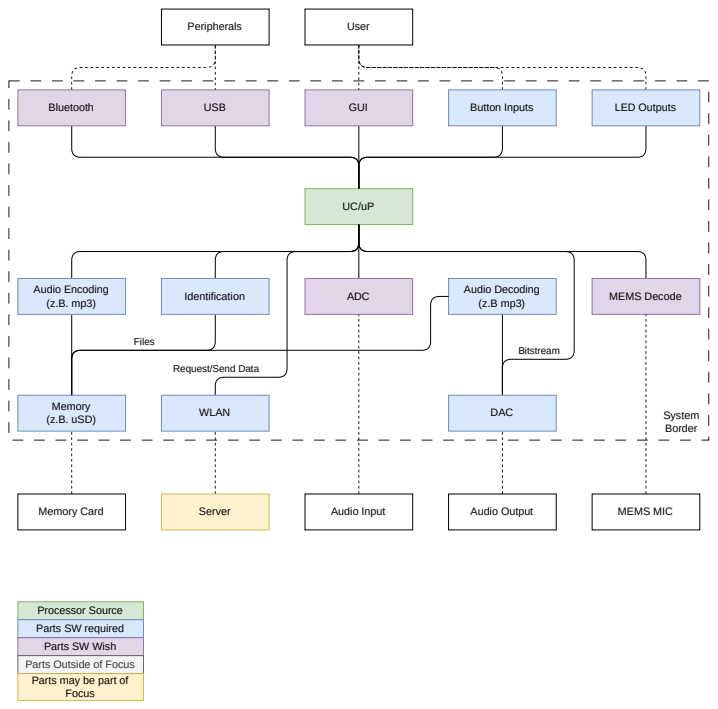
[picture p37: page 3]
Bluetooth; USB; Peripherals; Server; WLAN; Files; Audio Encoding (z.B. mp3); Bitstream; Audio Decoding (z.B mp3); Memory; (z.B. uSD); DAC; Identification; MEMS Decode; Audio Input; Audio Output; MEMS MIC; ADC; Memory Card; GUI; Button Inputs; LED Outputs; User; System Border

Request/Send Data

Processor Source
Parts SW required
Parts SW Wish
Parts Outside of Focus
Parts may be part of
Focus

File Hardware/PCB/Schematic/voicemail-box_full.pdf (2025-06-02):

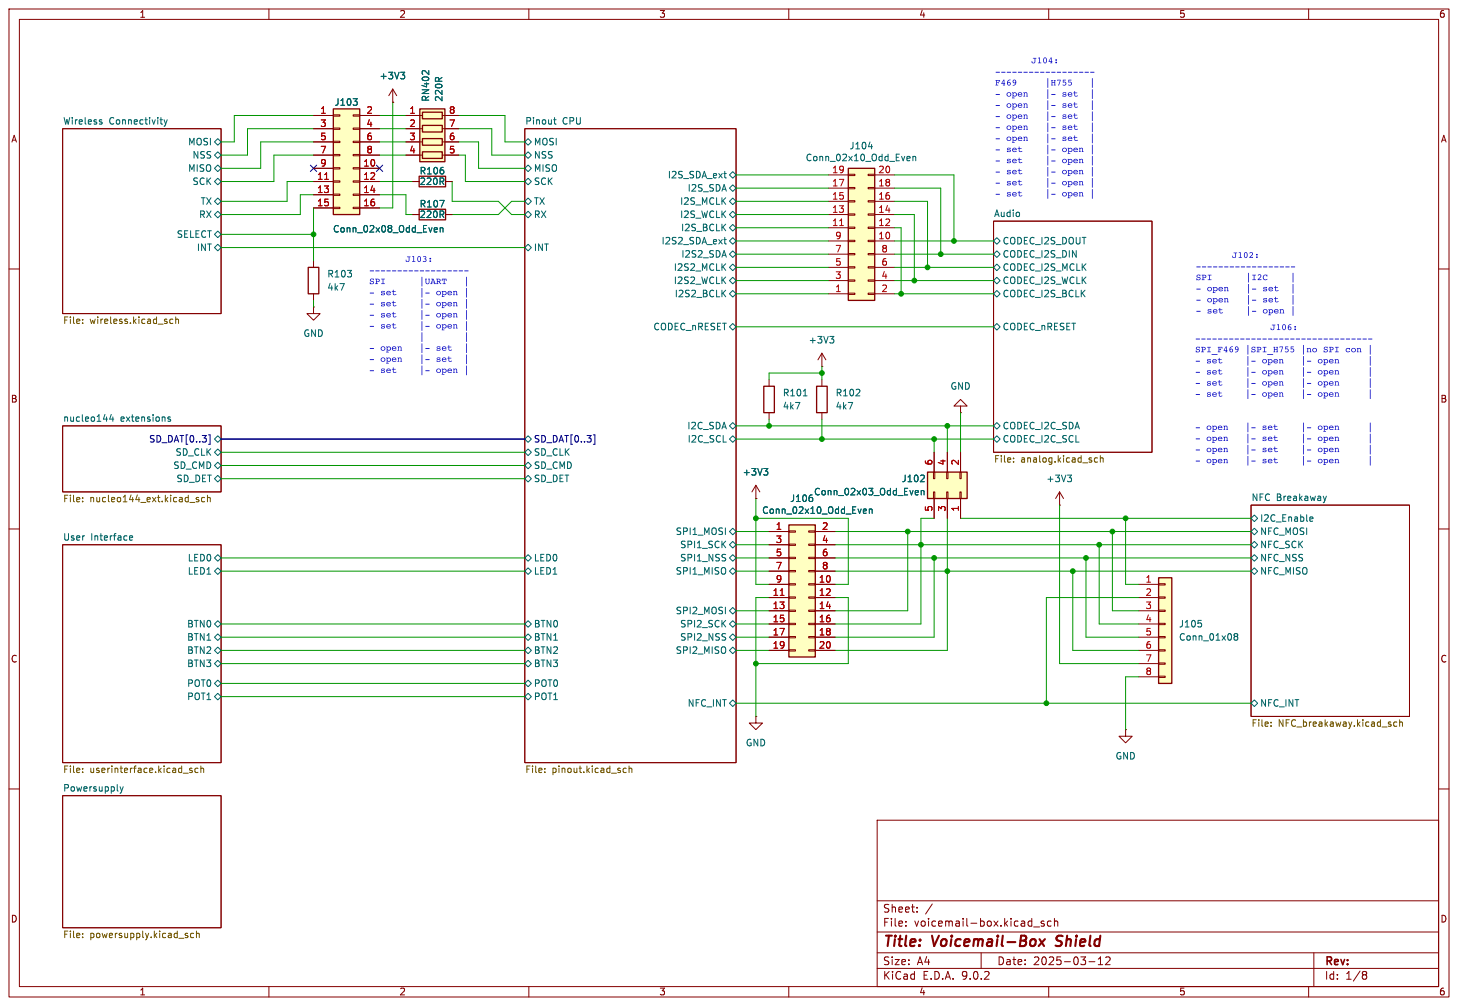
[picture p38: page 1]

INT Wireless Connectivity File: wireless.kicad_sch SD_CLK

File: voicemail-box.kicad_sch Sheet: /

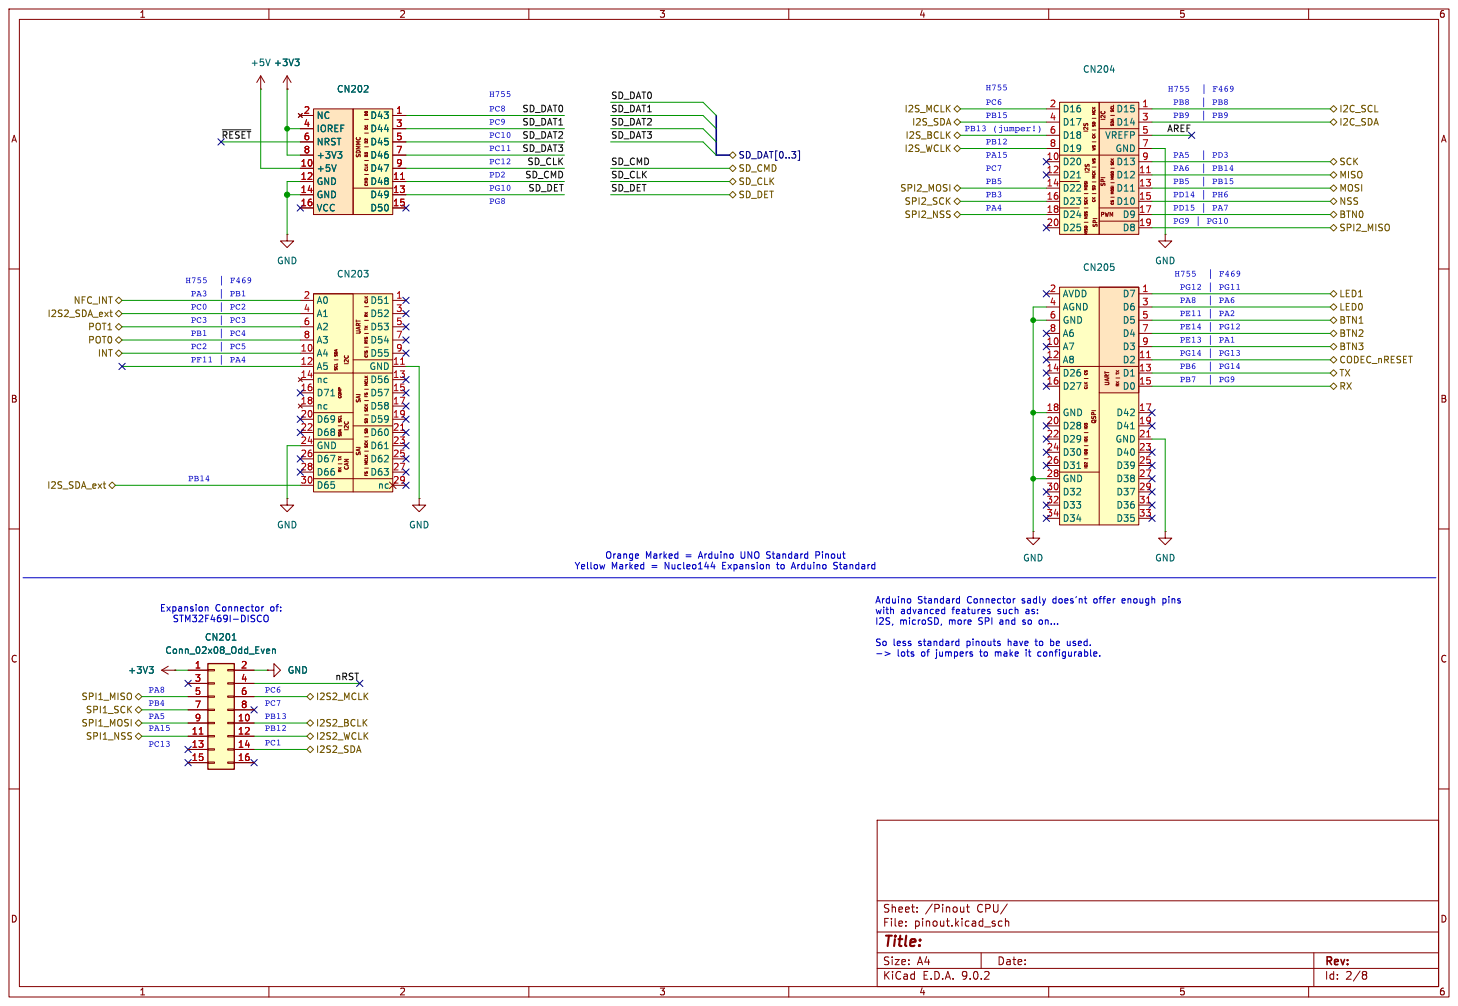
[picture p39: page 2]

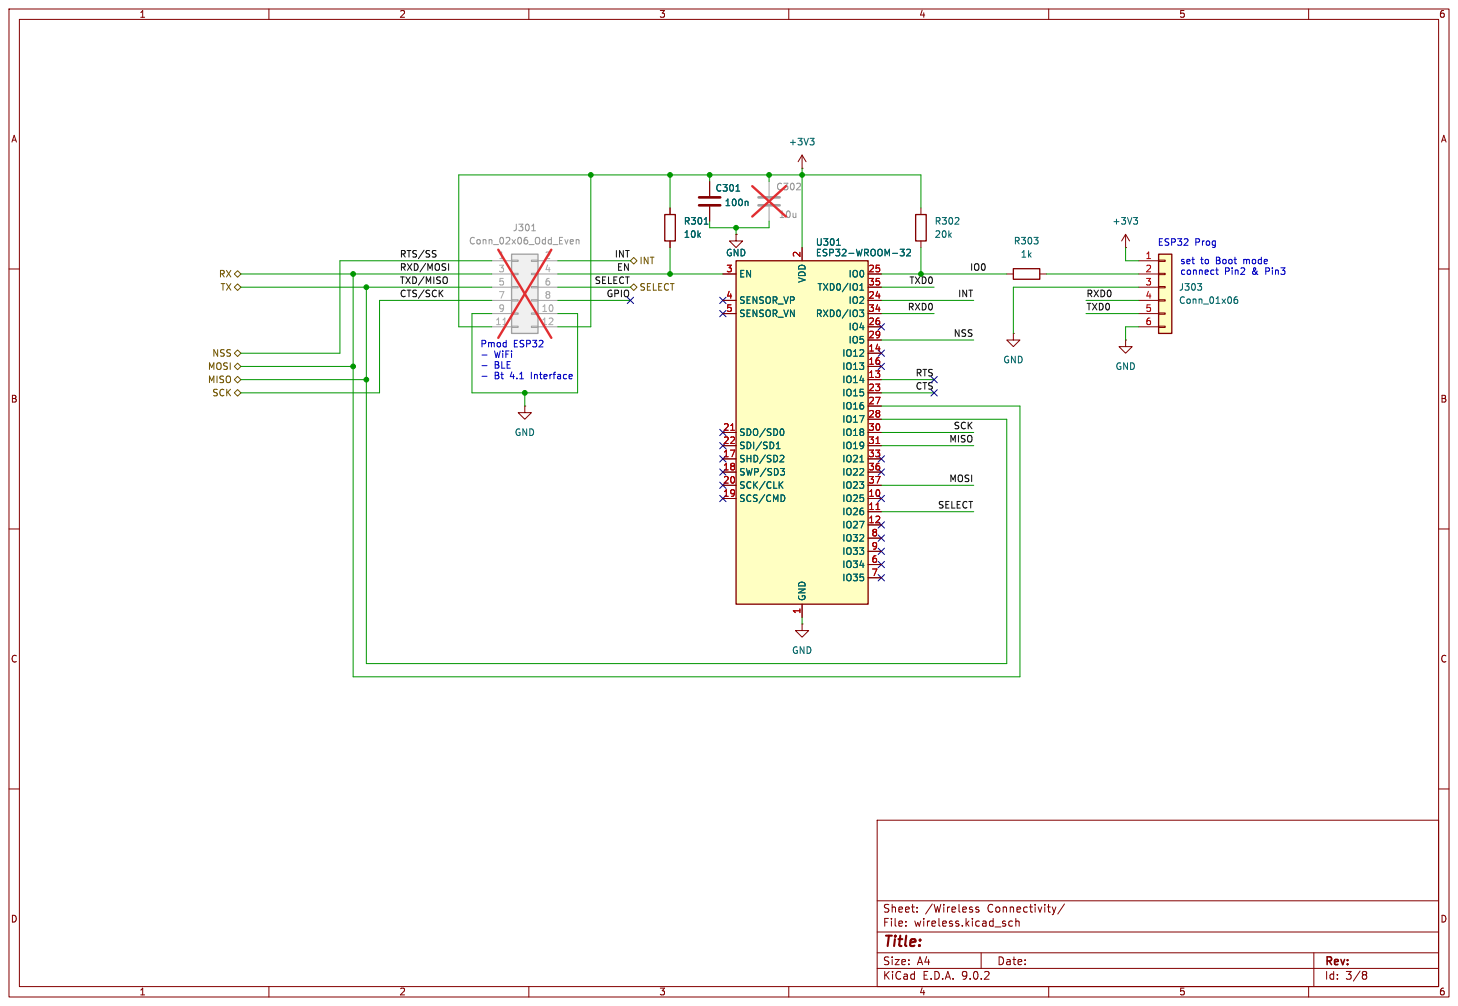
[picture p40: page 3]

set to Boot mode

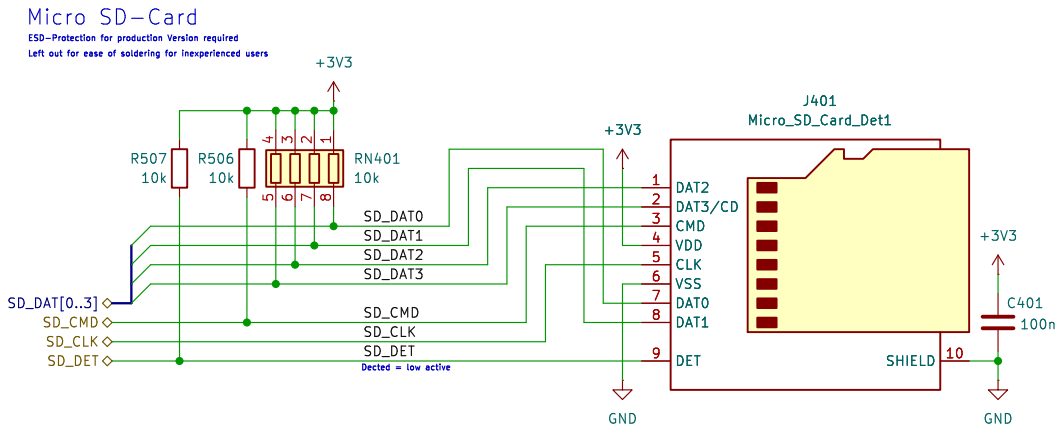
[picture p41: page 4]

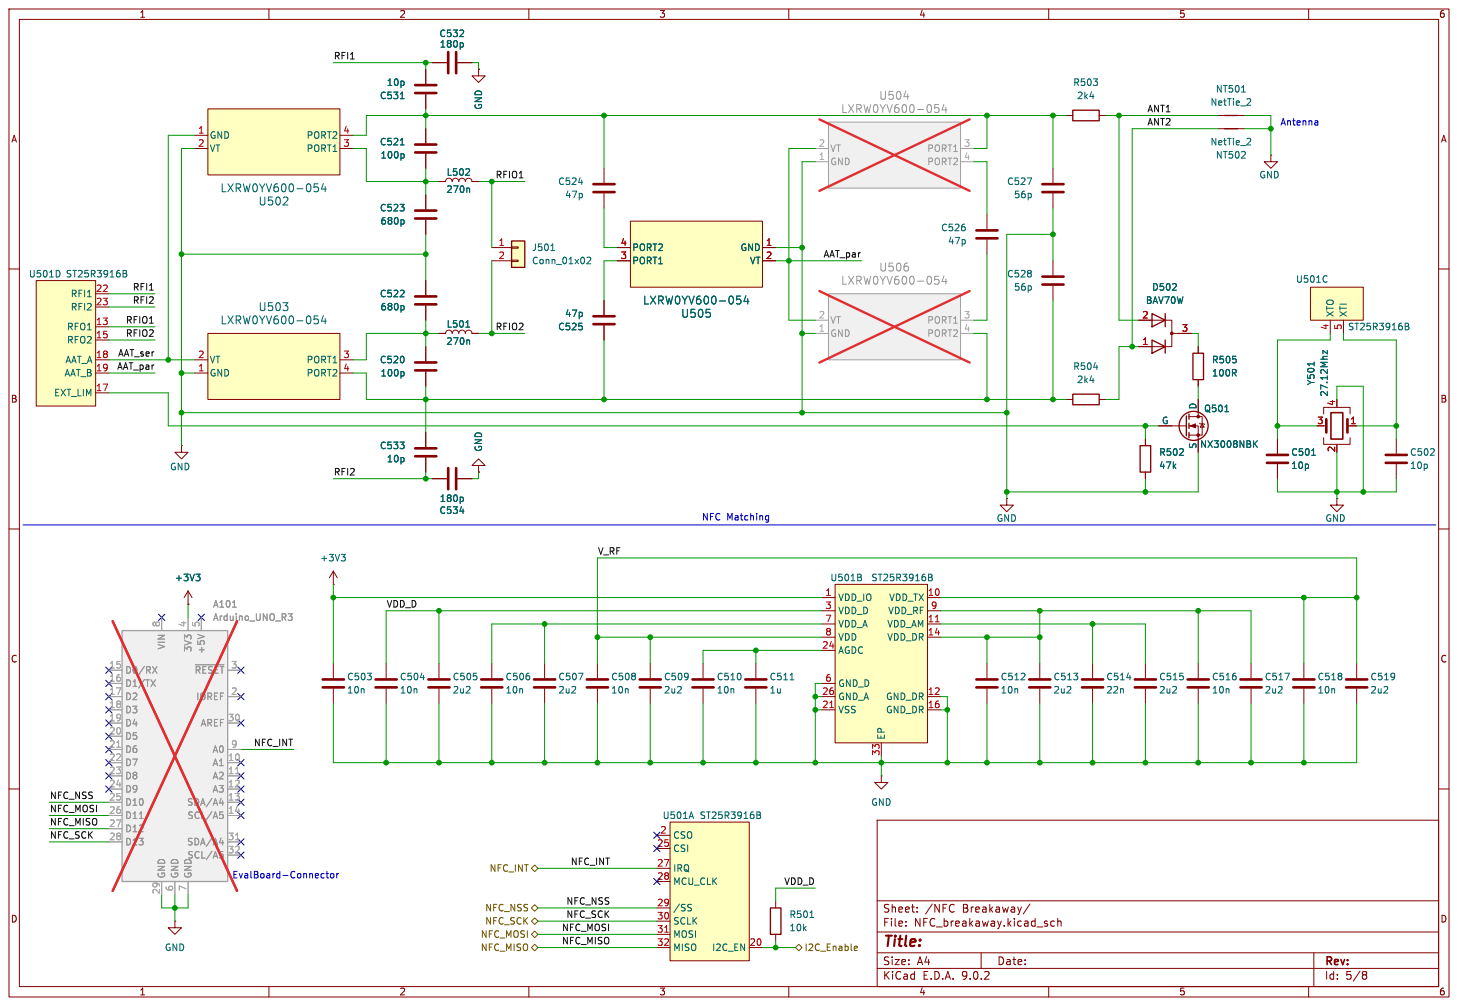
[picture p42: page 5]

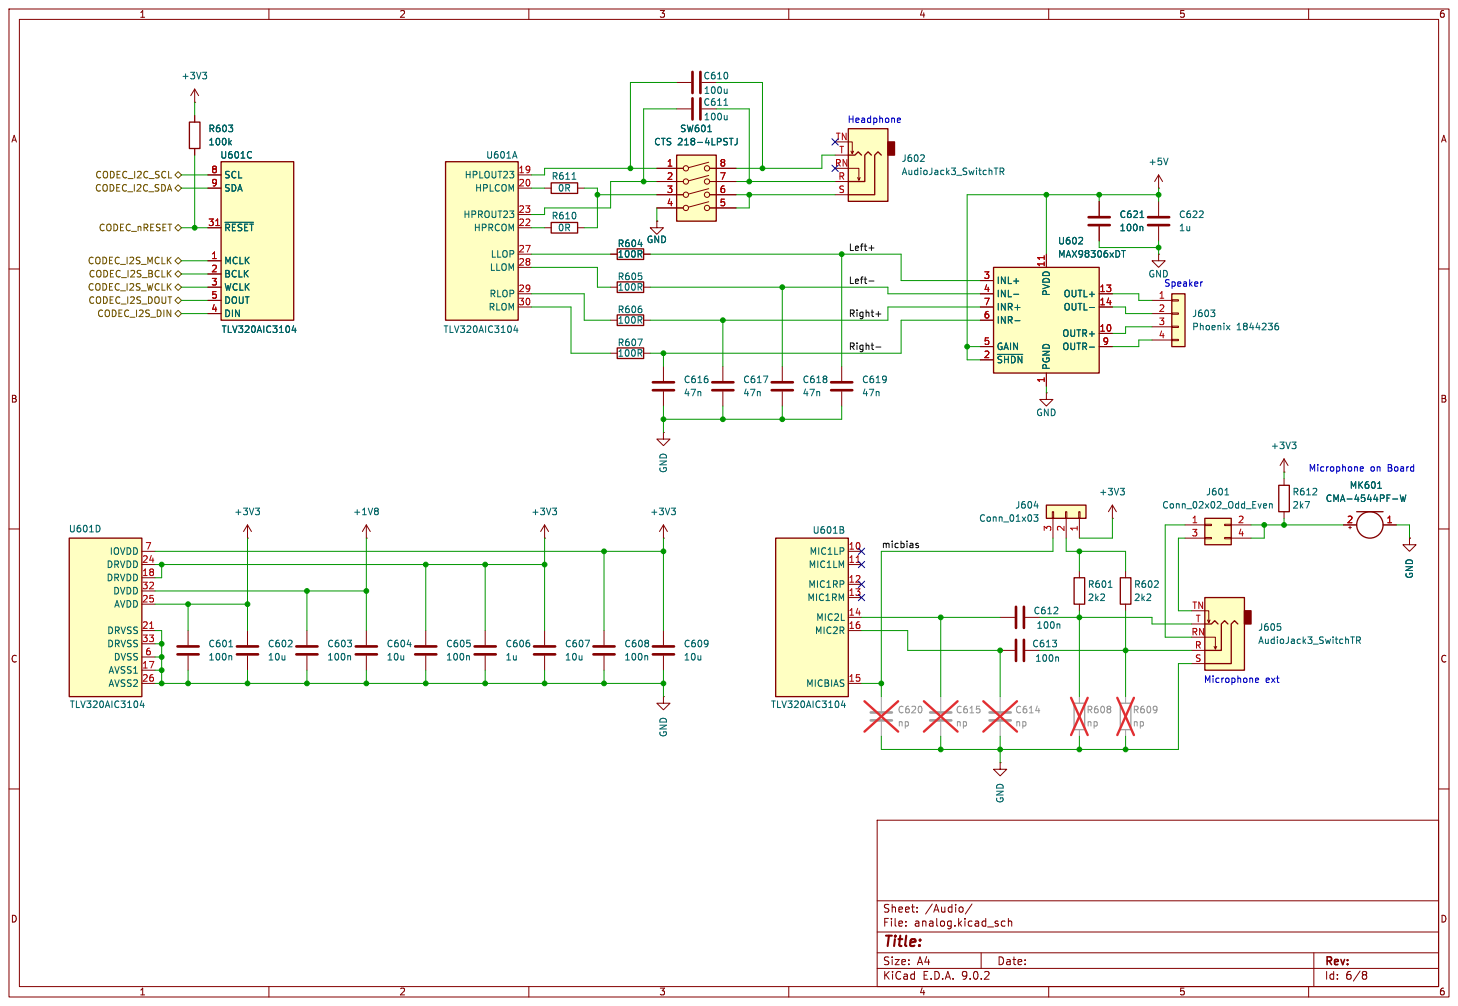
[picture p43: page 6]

1 OUTL+ 13 OUTL- 14 OUTR+ 10 OUTR- 9 GND R604

1 OUTL+ 13 OUTL- 14 OUTR+ 10 OUTR- 9 U602 MAX98306xDT

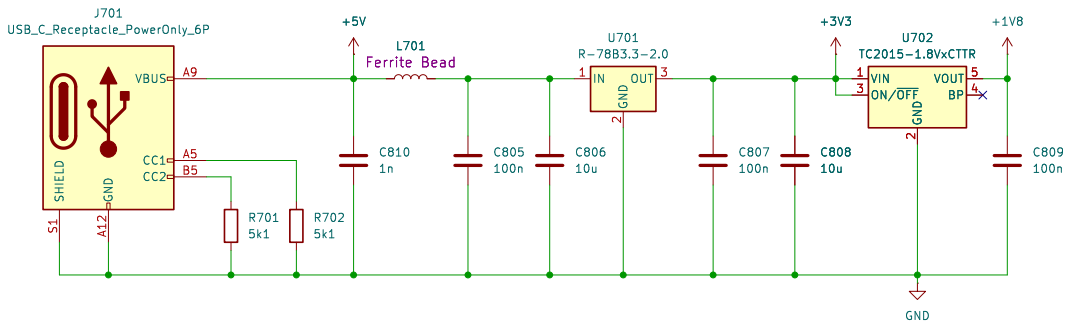
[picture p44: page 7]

2 OUT 3 U701 R-78B3.3-2.0 +1V8 SHIELD S1 GND A12 VBUS A9 CC1 A5 CC2 B5

Id: 7/8 Title: File: powersupply.kicad_sch Sheet: /Powersupply/ R702

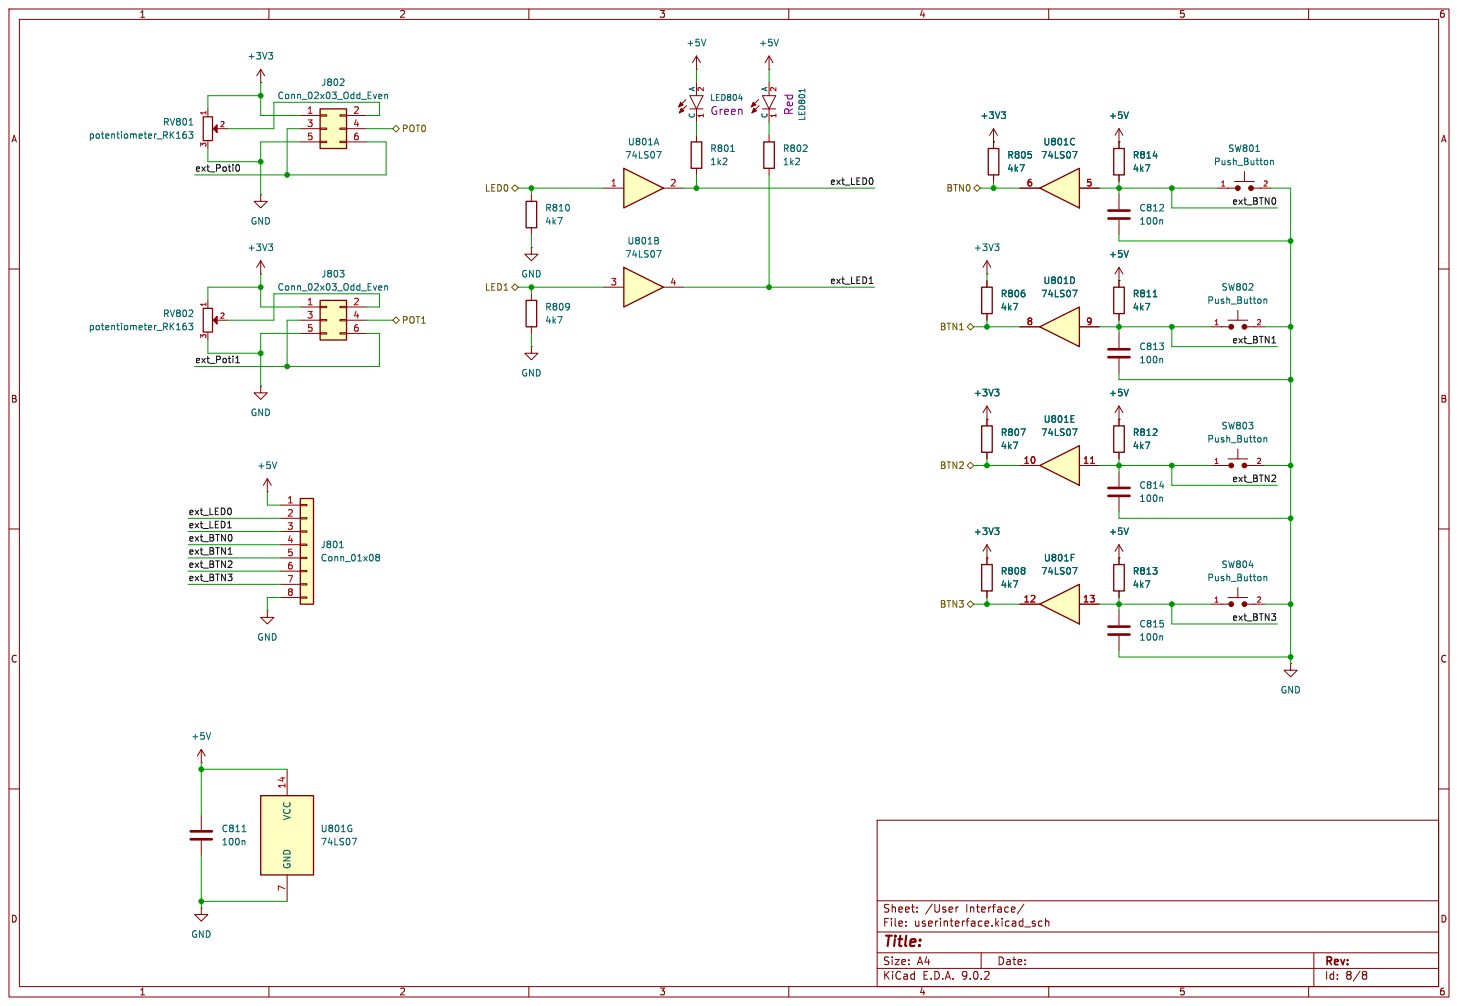
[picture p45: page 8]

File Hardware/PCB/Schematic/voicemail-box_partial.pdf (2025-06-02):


INT Wireless Connectivity File: wireless.kicad_sch SD_CLK

File: voicemail-box.kicad_sch Sheet: /


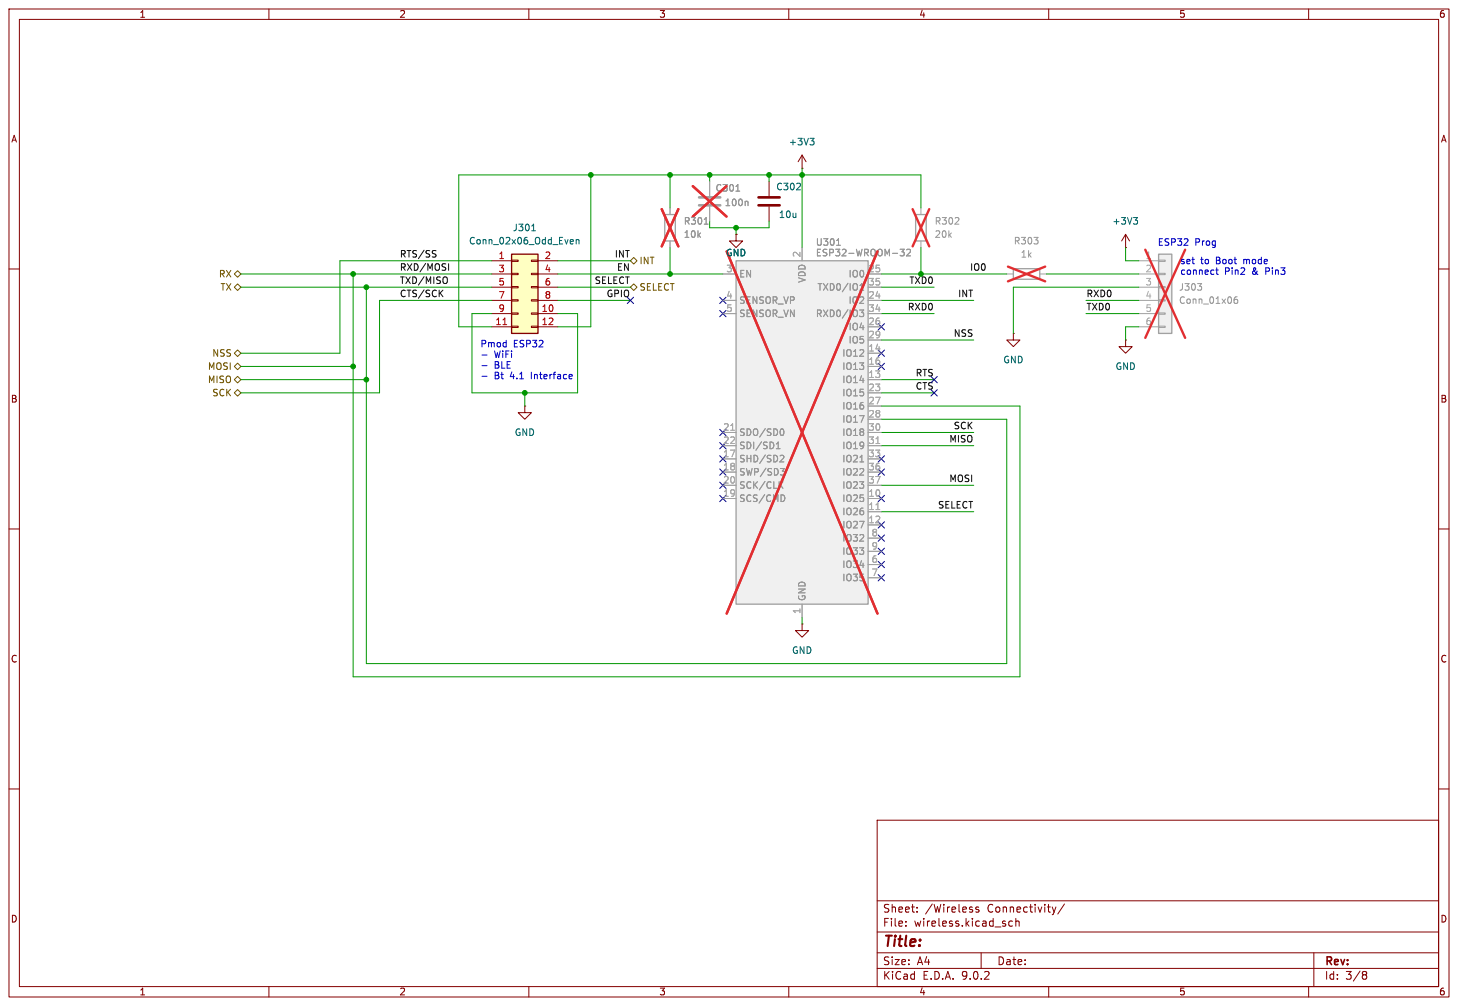
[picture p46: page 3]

INT SELECT MOSI SCK
TX MISO

set to Boot mode




TLV320AIC3104 SCL 8 SDA 9 ~{RESET} 31 MCLK 1 BCLK 2 WCLK 3 DOUT 5 DIN 4R603
100kSCL 8 SDA 9 ~{RESET} 31 MCLK 1 BCLK 2 WCLK 3 DOUT 5 DIN 4 U601C

1 OUTL+ 13 OUTL- 14 OUTR+ 10 OUTR- 9 GND R604

1 OUTL+ 13 OUTL- 14 OUTR+ 10 OUTR- 9 U602 MAX98306xDT


Id: 7/8 Title: File: powersupply.kicad_sch Sheet: /Powersupply/ R702



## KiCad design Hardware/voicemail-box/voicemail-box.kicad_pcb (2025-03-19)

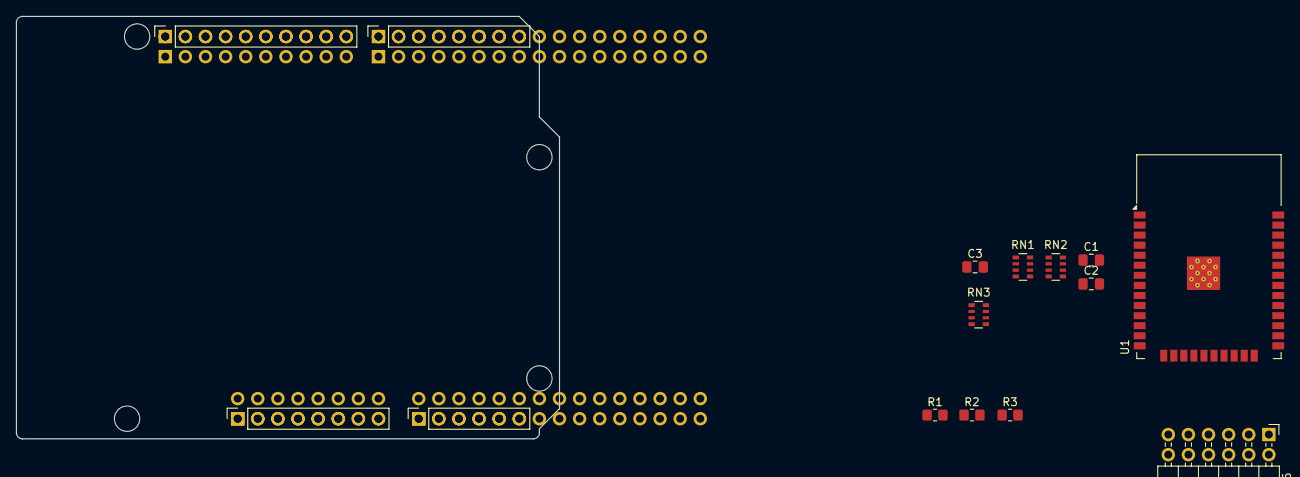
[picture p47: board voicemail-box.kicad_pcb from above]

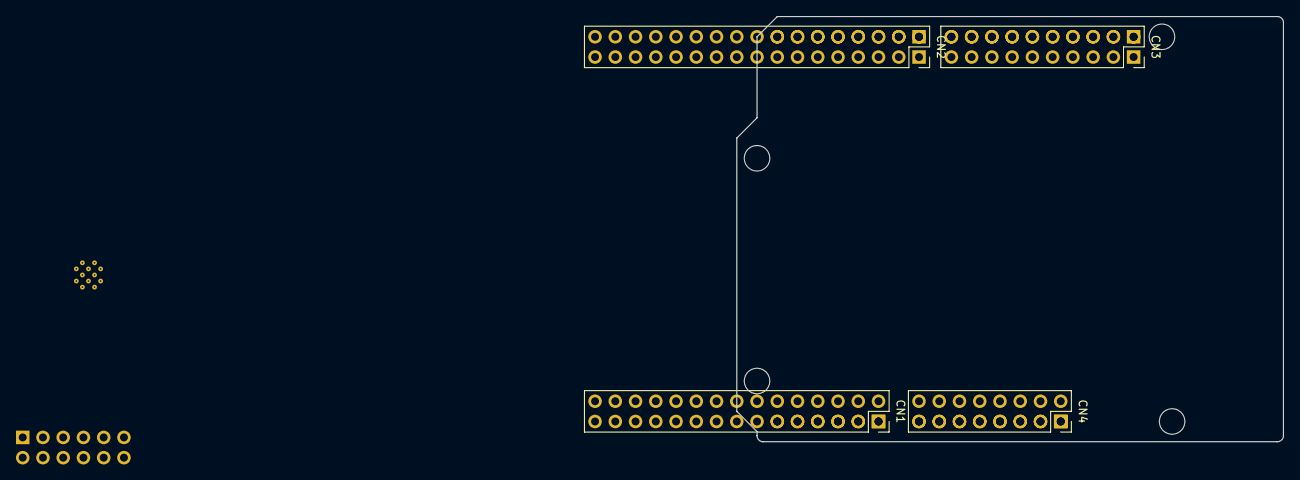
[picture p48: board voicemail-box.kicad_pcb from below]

Board: 2 copper layers, 68.6 x 53.3 mm, 23 parts (4 on the bottom side), 17 nets, no tracks yet.

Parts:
C1, C3: 100n; C_0805_2012Metric_Pad1.18x1.45mm_HandSolder
C2: 10u; C_0805_2012Metric_Pad1.18x1.45mm_HandSolder
CN1: PinSocket_2x15_P2.54mm_Vertical
CN2: PinSocket_2x17_P2.54mm_Vertical
CN3: PinSocket_2x10_P2.54mm_Vertical
CN4: PinSocket_2x08_P2.54mm_Vertical
J1: Power; PinSocket_1x08_P2.54mm_Vertical
J2: Digital/PWM; PinSocket_1x10_P2.54mm_Vertical
J3: Analog; PinSocket_1x06_P2.54mm_Vertical
J4: Digital/PWM; PinSocket_1x08_P2.54mm_Vertical
J5: Conn_02x06_Top_Bottom; PinHeader_2x06_P2.54mm_Horizontal
MH1, MH2, MH3, MH4: MountingHole_3.2mm
R1: 10k; R_0805_2012Metric_Pad1.20x1.40mm_HandSolder
R2: 20k; R_0805_2012Metric_Pad1.20x1.40mm_HandSolder
R3: 1k; R_0805_2012Metric_Pad1.20x1.40mm_HandSolder
RN1: np_0R; R_Array_Convex_4x0603
RN2: 0R; R_Array_Convex_4x0603
RN3: 10k; R_Array_Convex_4x0603
U1: ESP32-WROOM-32

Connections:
+3V3: C1.1, C2.1, C3.1, J1.2, J1.4, J5.6, J5.12, R1.1, R2.1, RN3.1 (R1.1), RN3.2 (R2.1), RN3.3 (R3.1), RN3.4 (R4.1), U1.2 (VDD)
/CTS/SCK: J5.4, RN1.1 (R1.1), RN2.1 (R1.1)
/EN: J5.8, R1.2, U1.3 (EN)
/GPIO: J5.10, U1.8 (IO32)
/INT: J5.7, U1.24 (IO2)
/IO0: R2.2, R3.1, U1.25 (IO0)
/MISO: RN2.7 (R2.2), U1.31 (IO19)
/MOSI: RN2.6 (R3.2), U1.37 (IO23)
/RTS/SS: J5.1, RN1.4 (R4.1), RN2.4 (R4.1)
/RXD: RN1.6 (R3.2), U1.27 (IO16)
/RXD/MOSI: J5.2, RN1.3 (R3.1), RN2.3 (R3.1)
/SCK: RN2.8 (R1.2), U1.30 (IO18)
/SELECT: J5.9, U1.11 (IO26)
/SS: RN2.5 (R4.2), U1.29 (IO5)
/TXD: RN1.7 (R2.2), U1.28 (IO17)
/TXD/MISO: J5.3, RN1.2 (R2.1), RN2.2 (R2.1)
GND: C1.2, C2.2, C3.2, J1.6, J1.7, J2.4, J5.5, J5.11, R3.2, U1.1 (GND), U1.15 (GND), U1.38 (GND), U1.39 (GND)

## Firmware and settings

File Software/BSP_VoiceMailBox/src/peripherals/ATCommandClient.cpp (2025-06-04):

#include "peripherals/ATCommandClient.hpp"
#include "utilities/File.hpp"
#include "platform.hpp"
#include <string>
#include <cstring>
#include <limits>
#include <charconv>  // For std::from_chars (C++17 and later)

namespace VoiceMailBox
{
	// Helper class to automatically clear the LED after the operation
	class AutoLedClearer
	{
	public:
		AutoLedClearer(DigitalPin* led)
			: m_led(led)
		{
			if(m_led)
				m_led->set(true);
		}
		~AutoLedClearer()
		{
			if (m_led)
				m_led->set(false);
		}

	private:
		DigitalPin* m_led;
	};

	ATCommandClient::ATCommandClient(VMB_UART_Handle* uartHandle, uint16_t uartBufferSize)
#ifdef VMB_USE_LOGGER_OBJECTS
		: Logger("ATCommandClient")
		, m_uart(uartHandle, uartBufferSize)
#else
		: m_uart(uartHandle, uartBufferSize)
#endif
		, m_trafficLed(nullptr)
	{

	}
	ATCommandClient::ATCommandClient(VMB_UART_Handle* uartHandle, uint16_t uartBufferSize, DigitalPin& trafficLed)
#ifdef VMB_USE_LOGGER_OBJECTS
		: Logger("ATCommandClient")
		, m_uart(uartHandle, uartBufferSize)
#else
		: m_uart(uartHandle, uartBufferSize)
#endif
		, m_trafficLed(&trafficLed)
	{
		setLED(false);
	}

	ATCommandClient::~ATCommandClient()
	{
	}

	bool ATCommandClient::setup()
	{
		// Setup the UART for AT command client
		bool success = m_uart.setup();


		success &= sendCommand("ATE0");
		if(waitUntilAndFlush("OK\r\n", 5000) && success) // Disable echo
		{
			VMB_LOGLN("Echo deactivated");
		}
		else
		{
			success = false;
			VMB_LOGLN("Can't deactivate echo");
			VMB_LOGLN("ATCommandClient setup failed, check UART connection and settings.");
		}
		return success;
	}


	bool ATCommandClient::sendCommand(const std::string& command)
	{
		return sendCommand(command.c_str());
	}
	bool ATCommandClient::sendCommand(const char* command)
	{
		m_uart.flush();
		m_uart.send((uint8_t*)command, strlen(command));
		m_uart.send((uint8_t*)("\r\n"), 2);
		uint32_t currentTick = VMB_HAL_GetTickCountInMs();
		uint32_t timeout = currentTick + 1000; // 1 second timeout
		bool timedOut = false;
		while (m_uart.isSending() && !timedOut)
		{
			timedOut =  VMB_HAL_GetTickCountInMs() > timeout;
			VMB_HAL_Delay(1); // Wait for the UART to finish sending
		}
		return !timedOut;
	}
	bool ATCommandClient::sendBytes(const uint8_t* data, uint16_t size)
	{
		m_uart.send(data, size);
		uint32_t currentTick = VMB_HAL_GetTickCountInMs();
		uint32_t timeout = currentTick + 1000; // 1 second timeout
		bool timedOut = false;
		while (m_uart.isSending() && !timedOut)
		{
			timedOut = VMB_HAL_GetTickCountInMs() > timeout;
			VMB_HAL_Delay(1); // Wait for the UART to finish sending
		}
		return !timedOut;
	}

	bool ATCommandClient::waitUntil(const char* response, uint32_t timeout)
	{
		return m_uart.waitUntil(response, timeout);
	}
	bool ATCommandClient::waitUntilAndFlush(const char* response, uint32_t timeout)
	{
		return m_uart.waitUntilAndFlush(response, timeout);
	}
	void ATCommandClient::flushRX()
	{
		m_uart.flushRX();
	}
	uint32_t ATCommandClient::flushNBytes(uint32_t nBytes)
	{
		return m_uart.flushNBytes(nBytes);
	}


	bool ATCommandClient::doesRespond()
	{
		flushRX();
		bool success = sendCommand("AT");
		if(m_uart.waitUntil("OK\r\n", 5000) && success)
		{
			flushRX();
			VMB_LOGLN("responds to AT command");
			return true; // Device responds to AT command
		}
		else
		{
			VMB_LOGLN("does not respond to AT command");
			return false; // Device does not respond
		}
	}



	bool ATCommandClient::connectToWifi(const std::string& ssid, const std::string& password)
	{
		bool success = sendCommand("AT+CWMODE=1");
		if (!waitUntilAndFlush("OK\r\n", 5000) && success) // Set WiFi mode to station
		{
			VMB_LOGLN("Can't set ESP to station mode");
			return false;
		}

		std::string command = "AT+CWJAP=\"" + ssid + "\",\"" + password + "\"";
		success = sendCommand(command.c_str());
		if (waitUntil("WIFI GOT IP\r\n", 10000) && success)
		{
			// Successfully connected to WiFi
			VMB_LOGLN("Connected to WiFi");
			return true;
		}
		else
		{
			// Failed to connect to WiFi
			VMB_LOGLN("Failed to connect to WiFi");
			return false;
		}
	}

	bool ATCommandClient::sendFileToServer(const std::string& localFileName, const std::string& urlPath, const std::string& serverIP, uint16_t serverPort)
	{
		AutoLedClearer clearer(m_trafficLed);

		flushRX();
		File file;
		if (!file.open(localFileName.c_str(), File::AccessMode::read))
		{
			VMB_LOGLN("Failed to open file: \"" +localFileName+"\"");
			return false; // Failed to open the file
		}

		uint32_t fileSize = file.getSize();
		if (fileSize == 0)
		{
			VMB_LOGLN("File is empty: \"" + localFileName + "\"");
			return false; // File is empty
		}

		// open TCP connection to the server
		std::string startRequest = "AT+CIPSTART=\"TCP\",\"" + serverIP + "\"," + std::to_string(serverPort);
		sendCommand(startRequest.c_str());
		if (!waitUntilAndFlush("OK\r\n", 5000))
		{
			VMB_LOGLN("Failed to connect to server: \"" + serverIP + ":" + std::to_string(serverPort) + "\"");
			return false; // Failed to connect to the server
		}

		std::string _localFileName = localFileName;
		if (_localFileName.find("/") != std::string::npos)
		{
			_localFileName = _localFileName.substr(_localFileName.find_last_of("/") + 1);
		}
		else if (_localFileName.find("\\") != std::string::npos)
		{
			_localFileName = _localFileName.substr(_localFileName.find_last_of("\\") + 1);
		}

		std::string boundary = "ESP";


		std::string post = "POST /"+ urlPath +" HTTP/1.1\r\n";
		std::string host = "Host: " + serverIP + ":" + std::to_string(serverPort) + "\r\n";
		std::string contentType = "Content-Type: multipart/form-data; boundary=" + boundary + "\r\n";
		std::string emptyLine = "\r\n";
		std::string boundaryStart = "--" + boundary + "\r\n";
		std::string contentDisposition = "Content-Disposition: form-data; name=\"test\"; filename=\"" + _localFileName + "\"\r\n";
		std::string contentTypeFile = "Content-Type: text/plain\r\n";
		std::string boundaryEnd = "\r\n--" + boundary + "--\r\n";




		std::string contentLength = "Content-Length: " + std::to_string(fileSize + boundaryStart.size() + 
			contentDisposition.size() + contentTypeFile.size() + emptyLine.size()*2 + boundaryEnd.size()) + "\r\n";


		uint32_t postRequestSize =
			post.length() +
			host.length() +
			contentLength.length() +
			contentType.length() +
			emptyLine.length() +
			boundaryStart.length() +
			contentDisposition.length() +
			contentTypeFile.length() +
			emptyLine.length();


		sendCommand("AT+CIPSEND=" + std::to_string(postRequestSize));
		toggleLED();
		if (!waitUntilAndFlush(">", 5000))
		{
			VMB_LOGLN("Failed to send data to server 1");
			return false; // Failed to send data to the server
		}
		toggleLED();
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

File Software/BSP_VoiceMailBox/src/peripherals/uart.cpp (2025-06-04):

#include "peripherals/uart.hpp"
#include "utilities/Logger.hpp"
#include <string>
#include <cstring>


namespace VoiceMailBox
{
	UART* UART::s_instances[] = { nullptr };


	UART::UART(VMB_UART_Handle* uartHandle, uint16_t bufferSize)
		: m_uart(uartHandle)
#ifdef VMB_UART_USE_STATIC_BUFFER_SIZE
		, m_bufferSize(VMB_UART_STATIC_BUFFER_SIZE)
		, rx_buffer{ 0 }
		, tx_buffer{ 0 }
#else
		, m_bufferSize(bufferSize)
		, rx_buffer(new uint8_t[bufferSize])
		, tx_buffer(new uint8_t[bufferSize])
#endif
		, rx_data(0)
		, rx_write_index(0)
		, rx_read_index(0)
		, tx_write_index(0)
		, tx_read_index(0)
		, m_sending(false)
		, m_bytesToSend(0)
	{
		for (std::size_t i = 0; i < sizeof(s_instances); i++)
		{
			if (s_instances[i] == nullptr)
			{
				s_instances[i] = this;
				break;
			}
		}

#ifndef VMB_UART_USE_STATIC_BUFFER_SIZE
		memset(tx_buffer, 0, m_bufferSize);
		memset(rx_buffer, 0, m_bufferSize);
#endif
		rx_data = 0;
		rx_write_index = 0;
		rx_read_index = 0;
	}
	UART::~UART()
	{
		for (std::size_t i = 0; i < sizeof(s_instances); i++)
		{
			if (s_instances[i] == this)
			{
				s_instances[i] = nullptr;
				break;
			}
		}
#ifndef VMB_UART_USE_STATIC_BUFFER_SIZE
		delete[] rx_buffer;
		delete[] tx_buffer;
#endif
	}
	bool UART::setup()
	{
		VMB_HAL_Status status = VMB_HAL_UART_Receive_IT(m_uart, &rx_data, 1);
		VMB_LOGGER_PRINT_STATUS(status, "UART::setup()");
		return status == VMB_HAL_Status::OK;
	}

	void UART::send(const char* str)
	{
		send((uint8_t*)str, strlen(str));
	}
	void UART::send(const uint8_t* data, uint32_t size)
	{
		if (size > m_bufferSize)
		{
			size = m_bufferSize;
		}
		if (data == nullptr)
		{
			return;
		}
		for (uint32_t i = 0; i < size; i++)
		{
			tx_buffer[tx_write_index] = data[i];
			tx_write_index = (tx_write_index + 1) % m_bufferSize;
		}
		m_bytesToSend += size;
		if (size > 0 && !m_sending) 
		{
			m_sending = true;
			m_bytesToSend--;
			VMB_HAL_UART_Transmit_IT(m_uart, &tx_buffer[tx_read_index], 1);
		}		
	}


	uint32_t UART::hasBytesReceived() const
	{
		return (m_bufferSize + rx_write_index - rx_read_index) % m_bufferSize;
	}
	uint32_t UART::receive(uint8_t* data, uint32_t size)
	{
		if (data == nullptr)
		{
			return 0;
		}
		uint16_t bytesReceived = hasBytesReceived();
		if (bytesReceived == 0)
		{
			return 0;
		}
		if (size > bytesReceived)
		{
			size = bytesReceived;
		}
		for (uint16_t i = 0; i < size; i++)
		{
			data[i] = rx_buffer[(rx_read_index + i) % m_bufferSize];
		}
		rx_read_index = (rx_read_index + size) % m_bufferSize; // Update read index
		return size;
	}
	uint32_t UART::receiveUntil(uint8_t* data, uint32_t size, uint8_t* target, uint32_t targetSize, uint32_t timeoutMS)
	{
		if (data == nullptr || target == nullptr)
		{
			return 0;
		}
		uint32_t startTime = VMB_HAL_GetTickCountInMs();
		uint32_t currentWriteIndex = 0;

		while (VMB_HAL_GetTickCountInMs() - startTime < timeoutMS)
		{
			uint32_t rb = hasBytesReceived();
			if (rb >= targetSize)
			{
				bool found = false;
				uint32_t matchCount = 0;
				uint32_t foundIndex = 0;
				for (uint32_t i = rx_read_index; i != (rx_write_index-targetSize+1) % m_bufferSize; i = (i + 1) % m_bufferSize)
				{
					for (uint32_t j = 0; j < targetSize; j++)
					{
						if (rx_buffer[(i + j) % m_bufferSize] == target[j])
						{
							if(j == 0)
								foundIndex = i;
							matchCount++;
							if(matchCount == targetSize)
							{
								found = true;
								goto extractData;
							}
						}
						else
						{
							matchCount = 0;
							goto nextIndex;
						}
					}
					nextIndex:;
				}
				extractData:


				if (found)
				{
					while(1)
					{
						if (currentWriteIndex < size)
						{
							if (rx_read_index == foundIndex)
							{
								return currentWriteIndex;
							}
							data[currentWriteIndex] = rx_buffer[rx_read_index];
							rx_read_index = (rx_read_index + 1) % m_bufferSize; // Update read index
							currentWriteIndex++;
						}
						else
						{
							return currentWriteIndex;
						}
					}
				}
				else
				{
					for (uint32_t i = 0; i < rb - targetSize; i++)
					{					
						if (currentWriteIndex < size)
						{
							data[currentWriteIndex] = rx_buffer[rx_read_index];
							currentWriteIndex++;
							rx_read_index = (rx_read_index + 1) % m_bufferSize; // Update read index
						}
						else
						{
							return currentWriteIndex;
						}
					}
				}
			}
		}
		// Timeout reached, return the data received so far
		VMB_LOGGER_PRINTLN("UART::receiveUntil() timeout reached, returning data received so far.");
		return currentWriteIndex;
	}
	bool UART::waitUntil(char character, uint32_t timeoutMS)
	{
		uint32_t startTime = VMB_HAL_GetTickCountInMs();
		uint32_t readIndex = rx_read_index;
		uint32_t currentReceivedBytes = hasBytesReceived();
		// Search first occurrence of character in the buffer
		for (uint32_t i = 0; i < currentReceivedBytes; i++)
		{
			if (rx_buffer[(readIndex + i) % m_bufferSize] == character)
			{
				return true;
			}
		}
		readIndex = currentReceivedBytes;
		uint32_t timeoutTime = startTime + timeoutMS;

		// If not found, wait for the character to be received
		while (VMB_HAL_GetTickCountInMs() > timeoutTime)
		{
			uint16_t rb = hasBytesReceived();
			if (currentReceivedBytes != rb)
			{
				currentReceivedBytes = rb;
				if (rx_buffer[readIndex % m_bufferSize] == character)
				{
					return true; // Character found
				}
				++readIndex;
			}
		}
		// Timeout reached
		VMB_LOGGER_PRINTLN(std::string("UART::waitUntil() timeout reached, character: '")+character+"' not found.");
		return false;
	}
	bool UART::waitUntil(const char* str, uint32_t timeoutMS)
	{
		uint32_t startIndex = 0;
		bool result = waitUntil_internal(str, timeoutMS, startIndex);
		if (!result)
		{
			VMB_LOGGER_PRINTLN("UART::waitUntil() timeout reached, string: \""+std::string(str)+"\" not found.");
		}
		return result;
	}
	bool UART::waitUntilAndFlush(const char* str, uint32_t timeoutMS)
	{
		uint32_t startIndex = 0;
		bool result = waitUntil_internal(str, timeoutMS, startIndex);
		if (result)
		{
			rx_read_index = (startIndex + strlen(str)) % m_bufferSize; // Update read index
		}
		else
		{
			VMB_LOGGER_PRINTLN("UART::waitUntilAndFlush() timeout reached, string: \"" + std::string(str) + "\" not found.");
		}
		return result;
	}

	bool UART::waitUntil_internal(const char* str, uint32_t timeoutMS, uint32_t& startIndex)
	{
		uint16_t strLength = strlen(str);
		uint32_t startTime = VMB_HAL_GetTickCountInMs();
		uint32_t startOffset = 0;
		uint16_t currentReceivedBytes = hasBytesReceived();
		// Search first occurrence of string in the buffer
		if (currentReceivedBytes >= strLength)
		{
			for (uint16_t i = 0; i <= currentReceivedBytes - strLength; ++i)
			{
				bool found = true;

				for (uint16_t j = 0; j < strLength; j++)
				{
					if (rx_buffer[(rx_read_index + i + j) % m_bufferSize] != str[j])
					{
						found = false;
						++startOffset;
						break;
					}
				}
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

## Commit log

2025-03-05 + Doku drawio files + Doku Board pdfs + NFC Sandbox Project + uSD Sandbox Project
2025-03-05 ~ fixed NFC Example ~ started testing of MicroSD Example
    [main.c]
2025-03-06 SPI & UART Communication attempt
2025-03-07 Wifi AP via UART working
2025-03-07 + Micro SD Project based on STM32F469 - Micro SD Project based on NUCLEO-H755 + Timeplan drawio
2025-03-11 start HW
    [voicemail-box.kicad_pcb, voicemail-box.kicad_sch]
2025-03-12 + gitignore ~ added existing pinout of sandbox tests
    [voicemail-box.kicad_pcb, voicemail-box.kicad_sch]
2025-03-12 - old project
    [voicemail-box.kicad_pcb, voicemail-box.kicad_sch]
2025-03-12 ~changed to hierarchical schematic
    [NFC_breakaway.kicad_sch, nucleo144_ext.kicad_sch, pinout.kicad_sch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]
2025-03-19 ~ HW Configuration
    [NFC_breakaway.kicad_sch, analog.kicad_sch, nucleo144_ext.kicad_sch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]
2025-04-01 ~working on first pcb-Draft
    [NFC_breakaway.kicad_sch, analog.kicad_sch, nucleo144_ext.kicad_sch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]
2025-04-02 - unused datasheets + new datasheets
    [analog.kicad_sch]
2025-04-03 schematic draft
    [NFC_breakaway.kicad_sch, analog.kicad_sch, nucleo144_ext.kicad_sch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]
2025-04-04 corrected pinout to nucleo description
    [pinout.kicad_sch, voicemail-box.kicad_sch]
2025-04-11 HW Layout progress todo: + Antenna + Audio Jacks + Planes (Supply only)
    [NFC_breakaway.kicad_sch, analog.kicad_sch, nucleo144_ext.kicad_sch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]
2025-04-16 layout progress step
    [pinout.kicad_sch, userinterface.kicad_sch, voicemail-box.kicad_sch]
2025-04-16 + CodecTest
    CodecTest: Project to test the audio codec.
    ~ ESP32_WIFI: Connecting to wifi, try to send data to a server (not working)
    [main.c]
2025-04-17 schema review
    [NFC_breakaway.kicad_sch, analog.kicad_sch, pinout.kicad_sch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]
2025-04-25 state of pcb ordered
    [NFC_breakaway.kicad_sch, pinout.kicad_sch, userinterface.kicad_sch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]
2025-05-07 + WIFI UART
    ~ UART is now working with DMA
    fast sending and receiving not working correctly yet.
    [Application.cpp, F469Discovery_Application.ioc, main.c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]
2025-05-08 - Removed DMA for UART
    + I2S Configuration
2025-05-12 + DBG Pins
    ~ UART
    + WaitUntil
    ~ Utils
    + TickCountInMS
2025-05-16 ~ doku
    [voicemail-box.kicad_sch]
2025-05-19 + MP3 class
    + MP3 encoder
2025-05-21 + Abstract
    [wireless.kicad_sch]
2025-05-22 + Automatic update for updatable objects
    + Updatable interface
    ~ The internal usage of the leds can now be enabled or disabled in the settings.h
    ~ Internal debug prints can now be enabled or disabled in the settings.h -> this enables/disables the compilation of the Logger class completly
    ~ Changed the plarform interface to reduce the files, removed BSP_VoiceMailBox.cpp
    + Documentation
2025-05-23 reorder Folderstructure
    [NFC_breakaway.kicad_sch, analog.kicad_sch, nucleo144_ext.kicad_sch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]
2025-05-24 ~ Moved I2C as private peripheral to a platform wide I2C instance
2025-05-26 ~ hw-files update
    [NFC_breakaway.kicad_sch, analog.kicad_sch, nucleo144_ext.kicad_sch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]
2025-05-26 + Initial H755 Example project but not configured correctly yet
    [Application.cpp, main.c]
2025-05-27 First not working H755 Test ¯\(°_o)/¯
    [AudioCodec.hpp, F469Discovery_Application.ioc]
2025-05-27 ~ Changed StLink UART Baud to 115200
2025-05-28 ~fixes on schematic and pcb ~prep for final output generation
    [NFC_breakaway.kicad_sch, analog.kicad_sch, nucleo144_ext.kicad_sch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]
2025-05-29 ~flash part ESP32 started
    [mfg_nvs.csv]
2025-05-29 + F469 HelloAudio example
    ~ Moved demos to board specific folders
2025-05-29 ~ board 3D files improved ~ bom output prep
    [218-4LPJ.STEP, 613012243121.stp, NFC_breakaway.kicad_sch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]
2025-05-30 finaly working variants
    [NFC_breakaway.kicad_sch, nucleo144_ext.kicad_sch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]
2025-05-30 ~bom rem from ignore
    [voicemail-box_full.csv, voicemail-box_partial.csv]
2025-05-31 + I2C example
2025-05-31 + MP3 Encoder/Decoder example
2025-05-31 + UART example
2025-06-01 + Microphone DC offset autocorrection for the AudioCodec class
    + DC offset correction example
    [Application.cpp, AudioCodec.hpp]
2025-06-02 + assembly plan
2025-06-02 ~assembly plan
2025-06-02 + Timer class, documentation & example
2025-06-04 added part labeling
    [voicemail-box-B_Cu.gbl, voicemail-box-B_Mask.gbs, voicemail-box-F_Cu.gtl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]
2025-06-05 re-added step files for propper 3D view
    [LXRW0_MUR.step, MAX98306ETD_T.step, ST25R3916B_AQET.step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]
2025-10-24 ~ Timer class
    + Added missing return in Timer::stop()
    + Doku in Timer.hpp
